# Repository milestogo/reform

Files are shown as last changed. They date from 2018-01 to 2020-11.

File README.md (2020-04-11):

# MNT Reform

This is the main repository for the MNT Reform open source laptop.

For details, check out [Finishing Reform](https://mntre.com/media/reform_md/2020-01-18-finishing-reform.html) and related articles.

## Impressions

Reform Version 2 Prototype
Reform Version 2 Motherboard

## License

Copyright 2018-2020 MNT Research GmbH.

The following licenses are used in the project, unless specified differently in a particular subfolder:

- Schematics, PCBs: [CERN-OHL-S v2](https://www.ohwr.org/project/cernohl/wikis/uploads/002d0b7d5066e6b3829168730237bddb/cern_ohl_s_v2.txt)
- Other documentation, artwork, photos and drawings that are not trademarks (see below): [CC-BY-SA 4.0](https://creativecommons.org/licenses/by-sa/4.0/legalcode)
- Software, firmware: Various. [GPL 3.0](https://www.gnu.org/licenses/gpl-3.0.en.html) if not specified otherwise in the file/subdirectory.

The "MNT" and "MNT REFORM" logos are trademarks of MNT Research GmbH. You may not use these in derived works. The reason for this is that we cannot be responsible for regulatory issues with derived boards and we cannot support them. If someone sees an MNT brand on a product, it has to be clear that it comes from MNT Research and not from a third party.

## Made With

* [KiCAD EDA](http://kicad-pcb.org/)
* [OpenSCAD](https://www.openscad.org/)
* [LUFA](http://www.fourwalledcubicle.com/LUFA.php)
* Autodesk Fusion (Case parts)

## MNT Reform Team

* **Lukas F. Hartmann (mntmn)** - *Schematics, PCB*
* **Ana Dantas** - *Industrial Design*
* **Greta Melnik** - *Quality & Assembly, Sleeve*

## Credits and Contributions

* [fully automated technologies](https://fully.automated.ee/) - *inrush limiter circuit*

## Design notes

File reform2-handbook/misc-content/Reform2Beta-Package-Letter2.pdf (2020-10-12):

MNT Research GmbH
Fehlerstr. 8, 12161 Berlin Germany

Email: lukas@mntre.com
Web: https://mntre.com

Director: Lukas F. Hartmann Amtsgericht Charlottenburg Aktenzeichen: HRB 136605 B WEEE: DE 33315564

Berlin, 2020-07-03
Dear MNT Customer,

Today we are delivering your MNT Reform 2.0 Beta unit. Thank you for putting your trust in us and for supporting our mission at this early stage: to ship a mobile computer that is as open and documented as possible, while still enabling productivity, privacy and easy maintenance.

We’ve put together this intro document to get you started quickly. We’re available for any further technical assistance.

Enjoy your MNT Reform!

Lukas F. Hartmann, Founder and Managing Director

Package Contents

- MNT Reform laptop with 2.0D-4 motherboard (with one wire patch for LTC4020 SHDN signal)
- MeanWell 24V 2.5A power supply with adapter
- This document and a hard copy of schematics

Safety

Please be extremely careful after opening the bottom panel, as there are up to 29V generated inside of the device which, when shorted, can cause sparks that can potentially ignite flammable material around the device. For this reason, we advise to unplug the battery cables from the motherboard before further disassembling the device. Do not touch/short the exposed metal pins of the battery holders with a metal tool!

Quick Start

First, you should learn a few keyboard shortcuts. Please note that currently, HYPER and the Circle Key (located next to F12) have the same function. This will likely change in the near future.

To turn the system on and off (hard power enable/disable) press Circle-1 or Circle-0 (zero), respectively. Circle-1 also does a hard reset of the main SoC if the system is already on.

To display cell voltage information, press Circle-V. Battery voltage, current and charger status can be checked with Circle-Y and Circle-S. The percentage displayed on the cell information screen is currently just a rough approximation based on total voltage. With the next update, a more useful percentage based on capacity and Amp hours spent will be implemented.

Circle-F1 and Circle-F2 decrease and increase the keyboard backlight brightness (but only if the main CPU/USB hub is powered). Circle-2 switches off the OLED. Circle-3 turns it back on.

To log in after boot, use “root” as the username with no password, and then create a new user account for yourself, following the on-screen instructions.

Boot

DIP switches SW5 on the motherboard allow you to toggle between eMMC and SD card boot (see schematics page 1). In the factory configuration, i.MX8MQ boots from the SD card.

Debugging

To control U-Boot or your own boot loader via UART, connect a UART adapter cable to the 3-pin header J18 (TX, RX and GND are labeled on the board) and configure your terminal to 115200 Baud 8N1. Please note that SER1 and SER2 labels are erroneously swapped on the silkscreen, so SER2 is UART1 and vice versa.

Trackball Tricks

The trackball has five buttons. The top two buttons function as left and right mouse buttons, the lower center button maps to the middle mouse button. Holding either the lower left or right buttons activates wheel mode, where vertical movement of the ball is translated into vertical mouse wheel events. The lower left button also generates a left click, but this will probably change in future versions.

The trackball is optical. We noticed that in direct bright sunlight, the optical sensor can be overwhelmed and works only if you block the sunlight with your other hand. This will be fixed by changing the trackball holder to a non-translucent material.

Display

The current beta version (2020-06-05) of the system image features an experimentally patched kernel module for the i.MX8MQ DCSS block that takes a parameter dcss_use_hdmi=1 (or 0) to activate either HDMI or internal MIPI DSI to eDP output at runtime. The eDP output is the default. Because the driver is loaded as a module, the display activates after a delay of a few seconds during boot. This is normal.

The display brightness can be controlled with the preinstalled brightnessctl tool (example: brightnessctl s 7). Brightness decrease/increase is mapped in sway to MNT-F1 / MNT-F2.

Speakers

To avoid damaging the speakers, keep the volume in check and lower it if audio distortion happens.

Further Information

The detailed Reform Operator’s Handbook is still being written. Meanwhile, refer to the following resources:

### 1. The system image build scripts

URL: https://source.mntmn.com/MNT/reform-system-image

Here you’ll find, in the reform2-imx8mq directory, the mkimage.sh and related scripts which generate the system image (including U-Boot and Linux Kernel) that is written on the MicroSD card preinstalled in your MNT Reform. You can find binary image files in the “Releases” section.

### 2. The interactive system diagram

URL: https://mntre.com/reform2-handbook/system.html

This is a technical block diagram of the individual components of the MNT Reform hardware with explanations and further links for each block.

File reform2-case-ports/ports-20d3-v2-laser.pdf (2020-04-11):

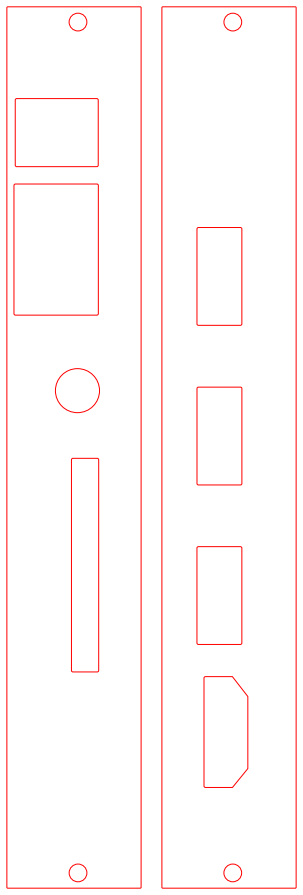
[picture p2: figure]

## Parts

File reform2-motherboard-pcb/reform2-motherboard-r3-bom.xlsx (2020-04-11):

Reference | Quantity | Value | Footprint | Distributor | Manufacturer | Manufacturer_No | THT | In Stock | To Order
J14 | 1 | USB_INT2 | Connector_JST:JST_PH_B4B-PH-K_1x04_P2.00mm_Vertical | Digikey | JST | B4B-PH-K-S(LF)(SN) | y
J16 | 1 | LINE_IN | Connector_PinHeader_2.00mm:PinHeader_1x03_P2.00mm_Vertical |  |  |  | y
J19 | 1 | JTAG | Connector_PinHeader_2.54mm:PinHeader_2x04_P2.54mm_Vertical | Mouser | Amphenol FCI | 79425-408HLF | y
J20 J18 | 2 | Conn_01x03_Male | Connector_PinHeader_2.54mm:PinHeader_1x03_P2.54mm_Vertical | Mouser | Wurth | 61300311121 | y
J21 | 1 | Conn_01x04 | Connector_JST:JST_PH_B4B-PH-K_1x04_P2.00mm_Vertical | Digikey | JST | B4B-PH-K-S(LF)(SN) | y
J22 | 1 | LPC_IO | Connector_PinHeader_2.54mm:PinHeader_2x08_P2.54mm_Vertical | Mouser | Molex | 87914-1616 | y
J23 | 1 | KDBSYSCTL | Connector_JST:JST_PH_B4B-PH-K_1x04_P2.00mm_Vertical | Digikey | JST | B4B-PH-K-S(LF)(SN) | y
J24 | 1 | EDP_HEADER | Connector_PinHeader_2.00mm:PinHeader_2x15_P2.00mm_Vertical | Mouser | Molex | 87758-3016 | y
J6 J5 J17 | 3 | USB3_A | Connector_USB:USB3_A_Molex_48393-001 | Mouser | Molex | 48393-0003 | y
J9 | 1 | USB_INT1 | Connector_JST:JST_PH_B4B-PH-K_1x04_P2.00mm_Vertical | Digikey | JST | B4B-PH-K-S(LF)(SN) | y
P1 | 1 | J0G-0003NL | footprints:PULSE_J0G-0003NL | Mouser | Pulse | J0G-0003NL | y
BT1 | 1 | CR1220 | Battery:BatteryHolder_Keystone_3000_1x12mm | Mouser | Keystone | 3000
C122 C161 | 2 | 100uF | Capacitor_SMD:CP_Elec_6.3x7.7 | Mouser | Panasonic | EEE-FTH101XAP
C141 C100 C111 C114 C129 C130 C4 C5 C32 C1 C146 C145 | 12 | 1uF | Capacitor_SMD:C_0603_1608Metric | Mouser | Taiyo Yuden | UMK107AB7105KA-T
C143 C144 C154 C142 C30 C29 C28 C27 C138 C56 C57 C52 C53 C54 C55 C58 C59 C60 C61 C119 C101 C103 C113 C118 C115 C105 C108 C106 C109 C107 C110 C135 C136 C23 C24 C25 C22 C26 C40 C42 C39 C41 C66 C73 C70 C85 C76 C77 C84 C67 C74 C75 C94 C93 C92 C90 C97 C96 C95 C89 C88 C87 C86 C14 C8 C13 C12 C11 C10 C9 C15 C7 C49 C50 C2 C80 C140 C149 | 78 | 0.1uF | Capacitor_SMD:C_0603_1608Metric | Mouser | Yageo | CC0603JPX7R9BB104
C147 C127 C83 C123 C124 C126 C121 | 7 | 47uF | Capacitor_SMD:C_0603_1608Metric | Mouser | Murata | GRM188R60J476ME15D
C150 C137 C120 C99 C112 C131 C133 C132 C134 C43 C91 C63 C81 C72 C69 C71 C37 C46 C47 C34 | 20 | 10uF | Capacitor_SMD:C_0603_1608Metric | Mouser | Murata | GRM188R6YA106MA73D
C151 C139 C35 C33 C6 | 5 | 4.7uF | Capacitor_SMD:C_0603_1608Metric | Mouser | TDK | C1608X5R1V475K080AC
C152 C153 C102 C104 C116 C117 C128 C148 | 8 | 10nF | Capacitor_SMD:C_0603_1608Metric | Mouser | KEMET | C0603C103K5RAC3190
C18 C16 C17 C19 | 4 | 220uF | Capacitor_SMD:CP_Elec_8x10 | Mouser | UCC | EMZR500ARA221MHA0G
C3 C31 | 2 | 0.33uF | Capacitor_SMD:C_0603_1608Metric | Mouser | TDK | C1608X7R1H334K080AC
C36 C38 | 2 | 6.8pF | Capacitor_SMD:C_0603_1608Metric | Mouser | Vishay | VJ0603A6R8DXQCW1BC
C44 C82 C125 C160 | 4 | 2.2uF | Capacitor_SMD:C_0603_1608Metric | Mouser | Taiyo Yuden | UMK107BBJ225KA-T
C45 | 1 | 0.033uF | Capacitor_SMD:C_0603_1608Metric | Mouser | KEMET | C0603C333J4REC7411
C65 | 1 | 680pF | Capacitor_SMD:C_0603_1608Metric | Mouser | KEMET | C0603C681J5GACTU
C68 C78 C79 C64 | 4 | 2nF | Capacitor_SMD:C_0603_1608Metric | Mouser | Murata | GRM1885C1H202JA01D
C98 C62 C21 C20 C51 C48 | 6 | 18pF | Capacitor_SMD:C_0603_1608Metric | Mouser | Yageo | CC0603JRNPO9BN180
D1 | 1 | BZT52C10 | Diode_SMD:D_SOD-123 | Mouser | Diodes, Inc. | BZT52C10-7-F
D11 | 1 | LED3V | LED_SMD:LED_0603_1608Metric | Mouser | ROHM | SMLEN3WBC8W1
D12 | 1 | LED5V | LED_SMD:LED_0603_1608Metric | Mouser | ROHM | SMLEN3WBC8W1
D2 | 1 | BAT46WJ,115 | Diode_SMD:D_SOD-323 | Mouser | Nexperia | BAT46WJ,115
D20 D21 | 2 | SK54A-LTP | Diode_SMD:D_SMA | Mouser | MCC | SK54A-LTP
D22 | 1 | LED_WLAN1 | LED_SMD:LED_0603_1608Metric | Mouser | ROHM | SMLEN3WBC8W1
D23 | 1 | LED_NVME | LED_SMD:LED_0603_1608Metric | Mouser | ROHM | SMLEN3WBC8W1
D3 D6 D4 | 3 | SBR0560S1 | Diode_SMD:D_SOD-123 | Mouser | Diodes, Inc. | SBR0560S1
D5 | 1 | RBR3MM60ATF | Diode_SMD:D_SOD-123 | Mouser | ROHM | RBR3MM60ATF
D7 | 1 | BZT52C6V2-7-F | Diode_SMD:D_SOD-123 | Mouser | Diodes, Inc. | BZT52C6V2-7-F
D8 | 1 | LEDCHG1 | LED_SMD:LED_0603_1608Metric | Mouser | ROHM | SML-D12Y1WT86
D9 | 1 | LEDCHG2 | LED_SMD:LED_0603_1608Metric | Mouser | ROHM | SML-D12Y1WT86
F2 F1 | 2 | 0157004.DR | footprints:fuse_smf | Mouser | Littelfuse | 0157004.DR
FB3 FB4 FB2 FB1 FB8 FB9 FB5 FB6 FB7 | 9 | 220@100MHz 1.4A | Inductor_SMD:L_0603_1608Metric | Mouser | Murata | BLM18PG221SH1D
H22 H24 H25 H27 | 4 | MountingHole_Pad | footprints:WA-SMSI-M2 | Mouser | Wurth | 9774010243
J1 | 1 | Jack-DC | footprints:SWC_RAPC712X | Mouser | Switchcraft | RAPC712X
J10 | 1 | 1-2199230-6 | footprints:TE_1-2199230-6 | Mouser | TE | 1-2199230-6
J11 | 1 | 48099-5701 | footprints:MOLEX_48099-5701 | Mouser | Molex | 48099-5701
J13 | 1 | BATCON1 | Connector_Molex:Molex_Pico-Lock_504050-0591_1x05-1MP_P1.50mm_Horizontal | Mouser | Molex | 504050-0591
J15 | 1 | Conn_01x33 | Connector_FFC-FPC:Hirose_FH12-33S-0.5SH_1x33-1MP_P0.50mm_Horizontal | Mouser | Hirose | FH12-33S-0.5SH(55)
J2 | 1 | BATCON2 | Connector_Molex:Molex_Pico-Lock_504050-0591_1x05-1MP_P1.50mm_Horizontal | Mouser | Molex | 504050-0591
J3 | 1 | SD_Card | footprints:TE_1775059-1 | Mouser | TE | 1775059-1
J4 | 1 | HDMI_A | footprints:HDMI-685119134923 | Mouser | Wurth | 685119134923
J7 | 1 | SJ-43516-SMT | footprints:SJ-43516-SMT | Mouser | CUI | SJ-43516-SMT-TR
J8 | 1 | USB_B_Micro | Connector_USB:USB_Micro-B_Molex-105017-0001 | Mouser | Molex | 105017-0001
L1 | 1 | 22uH 5A | Inductor_SMD:L_12x12mm_H6mm | Mouser | Wurth | 7447709220
L2 | 1 | IMC1210ER100K | Inductor_SMD:L_1210_3225Metric | Mouser | Vishay Dale | IMC1210ER100K
L3 L4 | 2 | 68uH | Inductor_SMD:L_Bourns_SRR1210A | Mouser | Bourns | SRR1210-680M
L5 | 1 | 10uH | Inductor_SMD:L_1210_3225Metric | Mouser | Taiyo Yuden | CBC3225T100MRV
L6 L7 | 2 | 2.2uH | Inductor_SMD:L_1210_3225Metric | Mouser | Taiyo Yuden | BRL3225T2R2M
Q14 Q11 Q5 Q10 Q9 Q8 Q7 Q6 Q12 | 9 | PMV50EPEAR | Package_TO_SOT_SMD:SOT-23 | Mouser | Nexperia | PMV50EPEAR
Q18 Q3 | 2 | Si7461DP | footprints:PowerPAK_SO-8_Single_8Pads | Mouser | Vishay Siliconix | SI7461DP-T1-E3
Q2 Q1 Q15 Q17 | 4 | Si7850DP | footprints:PowerPAK_SO-8_Single_8Pads | Mouser | Vishay Siliconix | SI7850DP-T1-E3
R1 | 1 | 9.1k 1% | Resistor_SMD:R_0603_1608Metric | Mouser | Yageo | RC0603FR-079K1L
R113 R119 R118 R117 R115 R45 R161 R128 R172 R54 | 10 | 10k | Resistor_SMD:R_0603_1608Metric | Mouser | Yageo | RC0603FR-0710KL
R120 R46 R86 R85 R84 R81 R178 R179 R181 R3 R56 R53 R8 R188 R189 | 15 | 100k | Resistor_SMD:R_0603_1608Metric | Mouser | Vishay Dale | CRCW0603100KJNEAC
R135 R136 R43 R44 R132 R131 R59 R58 R63 R60 R69 R68 R174 | 13 | 4.7k | Resistor_SMD:R_0603_1608Metric | Mouser | Yageo | RC0603FR-074K7L
R138 R114 R139 R150 R151 R121 R31 R25 R30 R29 R28 R27 R26 R32 R70 R72 | 16 | 33 | Resistor_SMD:R_0603_1608Metric | Mouser | Vishay Dale | CRCW060333R0FKEAC
R140 | 1 | 680 | Resistor_SMD:R_0603_1608Metric | Mouser | Yageo | RC0603FR-07680RL
R143 R142 R144 R48 R47 R80 | 6 | 47k | Resistor_SMD:R_0603_1608Metric | Mouser | Vishay Dale | CRCW060347K0FKEAC
R15 R9 R14 R13 R12 R11 R10 R16 R7 R52 R176 | 11 | 100 | Resistor_SMD:R_0603_1608Metric | Mouser | Vishay Dale | CRCW0603100RFKEAC
R156 R41 R55 R96 R97 R4 R5 R6 R153 | 9 | 1M | Resistor_SMD:R_0603_1608Metric | Mouser | Yageo | RC0603FR-071ML
R159 R158 R155 R154 R111 R191 R192 R145 R141 R187 R152 R35 R34 R65 R107 R104 R108 R105 R109 R106 R166 R149 R39 R123 R148 R77 R133 R134 R130 R129 R116 R146 R147 R103 R89 R88 R100 R101 R82 R83 R94 R95 R98 R73 R74 R75 R76 R79 R78 R124 R125 R126 R127 R157 R165 R163 R175 R51 R182 R185 R186 R137 R190 R193 | 64 | 0 | Resistor_SMD:R_0603_1608Metric | Mouser | Vishay Dale | CRCW06030000Z0EAC
R167 | 1 | 62 | Resistor_SMD:R_0603_1608Metric | Mouser | Yageo | RC0603FR-0762RL
R169 R170 R171 R168 R42 R160 R122 R40 R38 R37 R102 R71 | 12 | 1.5k | Resistor_SMD:R_0603_1608Metric | Mouser | Yageo | RC0603FR-071K5L
R173 | 1 | 49.9k | Resistor_SMD:R_0603_1608Metric | Mouser | Vishay Dale | CRCW060349K9FKEAC
R177 | 1 | 0.02 | Resistor_SMD:R_0612_1632Metric | Mouser | ROHM | LTR18EZPFSR020
R180 | 1 | 150k | Resistor_SMD:R_0603_1608Metric | Mouser | Vishay Dale | CRCW0603150KFKEAC
R2 | 1 | 1.3k 1% | Resistor_SMD:R_0603_1608Metric | Mouser | Yageo | RC0603FR-071K3L
R23 R17 R22 R21 R20 R19 R18 R24 | 8 | 3.3k | Resistor_SMD:R_0603_1608Metric | Mouser | Vishay Dale | CRCW06033K30FKEAC
R33 R164 R183 R184 | 4 | 1k | Resistor_SMD:R_0603_1608Metric | Mouser | Yageo | RC0603FR-071KL
R50 R49 | 2 | 0.01 | Resistor_SMD:R_0612_1632Metric | Mouser | ROHM | LTR18EZPFU10L0
R57 | 1 | 9.53k | Resistor_SMD:R_0603_1608Metric | Mouser | Yageo | RC0603FR-079K53L
R61 | 1 | 90.9k 1% | Resistor_SMD:R_0603_1608Metric | Mouser | Vishay Dale | CRCW060390K9FKEAC
R62 | 1 | 10k 1% | Resistor_SMD:R_0603_1608Metric | Mouser | Yageo | RC0603FR-0710KL
R64 | 1 | 51k | Resistor_SMD:R_0603_1608Metric | Mouser | Yageo | RC0603FR-0751KL
R66 R112 | 2 | 220 | Resistor_SMD:R_0603_1608Metric | Mouser | Yageo | RC0603FR-07220RL
R67 R110 R36 | 3 | 475 | Resistor_SMD:R_0603_1608Metric | Mouser | Yageo | RC0603FR-07475RL
R87 R99 | 2 | 24.9k | Resistor_SMD:R_0603_1608Metric | Mouser | Yageo | RC0603FR-0724K9L
R90 R92 R91 R93 | 4 | 27 | Resistor_SMD:R_0603_1608Metric | Mouser | Yageo | RC0603FR-0727RL
SW1 | 1 | SW_LPCPROG | Button_Switch_SMD:SW_DIP_SPSTx01_Slide_Omron_A6S-110x_W8.9mm_P2.54mm | Mouser | Omron | A6S-1101-H
SW2 | 1 | SW_LPCRST | Button_Switch_SMD:SW_Push_1P1T_NO_CK_KMR2 | Mouser | CK | KMR223NGULCLFG
SW3 | 1 | SW_DIP_x01 | Button_Switch_SMD:SW_DIP_SPSTx01_Slide_Omron_A6S-110x_W8.9mm_P2.54mm | Mouser | Omron | A6S-1101-H
SW5 | 1 | SW_DIP_x04 | Button_Switch_SMD:SW_DIP_SPSTx04_Slide_Omron_A6S-410x_W8.9mm_P2.54mm | Mouser | Omron | A6S-4101-H
SW6 | 1 | SW_Push | Button_Switch_SMD:SW_Push_1P1T_NO_CK_KMR2 | Mouser | CK | KMR223NGULCLFG
U1 | 1 | Nitrogen8M | footprints:TE_1473149-4 | Mouser | TE | 1717254-1
U10 | 1 | SN65DSI86IPAPQ1 | Package_QFP:HTQFP-64-1EP_10x10mm_P0.5mm_EP8x8mm | Mouser | Texas Instruments | SN65DSI86IPAPQ1
U11 | 1 | 679105700 | footprints:MOLEX_67910-5700 | Mouser | Molex | 67910-5700
U12 | 1 | LM2677SX-3.3 | Package_TO_SOT_SMD:TO-263-7_TabPin8 | Mouser | Texas Instruments | LM2677S-3.3/NOPB
U13 U19 | 2 | TLV62568DBV | Package_TO_SOT_SMD:SOT-23-5 | Mouser | Texas Instruments | TLV62568DBVR
U14 | 1 | LM2841X | Package_TO_SOT_SMD:TSOT-23-6 | Mouser | Texas Instruments | LM2841XMK-ADJL/NOPB
U15 U16 | 2 | TPS2561 | Package_SON:VSON-10-1EP_3x3mm_P0.5mm_EP1.65x2.4mm_ThermalVias | Mouser | Texas Instruments | TPS2561DRCR
U17 | 1 | TLV1117-18 | Package_TO_SOT_SMD:SOT-223 | Mouser | Texas Instruments | TLV1117-18CDCYR
U18 | 1 | LPC11U24FBD48-301 | Package_QFP:LQFP-48_7x7mm_P0.5mm | Mouser | NXP | LPC11U24FBD48-301
U2 | 1 | LTC4020EUHFPBF | Package_DFN_QFN:QFN-38-1EP_5x7mm_P0.5mm_EP3.15x5.15mm | Mouser | Analog Devices | LTC4020EUHF#PBF
U22 | 1 | TPD12S521 | footprints:TSSOP50P640X120-38N | Mouser | Texas Instruments | TPD12S521
U23 | 1 | IDT5V41066 | Package_SO:TSSOP-20_4.4x6.5mm_P0.65mm | Mouser | IDT | 5V41066PGGI8
U3 | 1 | WM8960 | Package_DFN_QFN:QFN-32-1EP_5x5mm_P0.5mm_EP3.45x3.45mm_ThermalVias | Mouser | Cirrus Logic | WM8960CGEFL/V
U4 | 1 | LTC6803-4 | Package_SO:SSOP-44_5.3x12.8mm_P0.5mm | Mouser | Analog Devices | LTC6803IG-4#PBF
U5 | 1 | PCF8523T | Package_SO:SOIC-8_3.9x4.9mm_P1.27mm | Mouser | NXP | PCF8523T/1,118
U6 | 1 | INA260 | Package_SO:TSSOP-16_4.4x5mm_P0.65mm | Mouser | Texas Instruments | INA260AIPWR
U7 | 1 | LM2677SX-5 | Package_TO_SOT_SMD:TO-263-7_TabPin8 | Mouser | Texas Instruments | LM2677SX-5
U8 | 1 | TXS0108EPW | Package_SO:TSSOP-20_4.4x6.5mm_P0.65mm | Mouser | Texas Instruments | TXS0108EPW
U9 | 1 | TUSB8041IPAPRQ1 | Package_QFP:HTQFP-64-1EP_10x10mm_P0.5mm_EP8x8mm_Mask4.4x4.4mm_ThermalVias | Mouser | Texas Instruments | TUSB8041IPAPRQ1
Y1 | 1 | 24MHz | Crystal:Crystal_SMD_Abracon_ABM8G-4Pin_3.2x2.5mm | Mouser | Abracon | ABM8AIG-24.000MHz-R40-4-T
Y2 | 1 | 12MHz | Crystal:Crystal_SMD_Abracon_ABM8G-4Pin_3.2x2.5mm | Mouser | Abracon | ABM8AIG-12.000MHz-2-T
Y3 | 1 | 25MHz | Crystal:Crystal_SMD_Abracon_ABM8G-4Pin_3.2x2.5mm | Mouser | Abracon | ABM8AIG-25.000MHz-R40-4-T
Y4 | 1 | 32.768 kHz | Crystal:Crystal_SMD_3215-2Pin_3.2x1.5mm | Mouser | ECS | ECS-.327-7-34B-TR
 | 441

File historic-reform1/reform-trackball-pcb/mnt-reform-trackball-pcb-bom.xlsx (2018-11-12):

 |  |  | MNT Reform-Trackball 20PCS BOM
Item # | *Ref Des | *Qty | Manufacturer | *Mfg Part # | Description / Value | *Package | Type | Your Instructions / Notes
1 | C1,C2 | 2 | Generic | Generic | 18pF >=6V | 0603 | SMD
2 | C3 | 1 | Generic | Generic | 0.1uF >=6V | 0603 | SMD
3 | C4 | 1 | Generic | Generic | 1uF >=6V | 0603 | SMD
4 | U1 | 1 | Microchip | ATMEGA32U2-AU | 8 Bit MCU | TQFP-32 | SMD | Pin 1 on bottom right
5 | Y1 | 1 | Fox | FC3BACALI16.0 | 16MHz 18pF 30ppm -40C +125C | 3.2 mm x 2.5 mm x 1.7 mm | SMD | Pin 1 on bottom left
6 | R1,R2 | 2 | Generic | Generic | 10kOhm | 0603 | SMD

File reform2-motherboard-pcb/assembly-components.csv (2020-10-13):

references | value | manufacturer | part_number | qty
ZPCB | PCB | MNT Research / PCBWay | MREFPMOB20R01 | 1

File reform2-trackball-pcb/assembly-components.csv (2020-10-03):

references | value | manufacturer | part_number | qty
ZPCB | PCB | MNT Research | MREFPTBC20R01 | 1

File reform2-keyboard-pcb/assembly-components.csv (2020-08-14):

references | value | manufacturer | part_number | qty
ZKCAP15 | Keycap 1.5U | Kailh | BSPG1350-06009 | 10
ZKCAP10 | Keycap 1U | Kailh | BSPG1350-06001P2 | 72
ZPCB | PCB | MNT Research / PCBWay | MREFPKBD20D04 | 1

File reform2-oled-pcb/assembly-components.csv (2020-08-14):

references | value | manufacturer | part_number | qty
ZPCB | PCB | MNT Research | MREFPOLE20D04 | 1

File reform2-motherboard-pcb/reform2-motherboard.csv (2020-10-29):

Reference | Quantity | Value | Footprint | Datasheet | Checked | Distributor | Manufacturer | Manufacturer_No | DNP | Availability | Field12 | Field13 | Field14 | Field15 | Field17 | Field18 | Field21 | Field22 | Field23 | Field25 | Field28 | Field30 | Field33 | Field34 | Field38 | Field39 | Field40 | Field42 | Field43 | Field5 | Field6 | Field4
BT1 | 1 | CR1220 | Battery:BatteryHolder_Keystone_3000_1x12mm | ~ | y | Mouser | Keystone | 3000
C122 C161 | 2 | 100uF | Capacitor_SMD:CP_Elec_6.3x7.7 | ~ | y | Mouser | Panasonic | EEE-FTH101XAP
C141 C162 C163 C100 C111 C114 C129 C130 C4 C5 C32 C1 C146 C145 | 14 | 1uF | Capacitor_SMD:C_0603_1608Metric | ~ | y | Mouser | Taiyo Yuden | UMK107BJ105KA-T
C143 C144 C154 C142 C156 C158 C165 C166 C30 C29 C28 C27 C138 C56 C57 C169 C168 C53 C54 C55 C59 C60 C61 C119 C101 C103 C113 C118 C115 C105 C108 C106 C109 C107 C110 C135 C136 C23 C24 C25 C22 C26 C86 C87 C88 C89 C95 C96 C97 C90 C92 C93 C94 C75 C74 C67 C84 C77 C76 C85 C70 C73 C66 C41 C39 C42 C40 C14 C8 C13 C12 C11 C10 C9 C15 C7 C49 C50 C2 C80 C140 C149 | 82 | 0.1uF | Capacitor_SMD:C_0603_1608Metric | ~ | y | Mouser | Yageo | CC0603JPX7R9BB104
C147 C127 C83 C123 C124 C126 C121 | 7 | 47uF | Capacitor_SMD:C_0603_1608Metric | ~ | y | Mouser | Murata | GRM188R60J476ME15D
C150 C137 C120 C155 C99 C112 C131 C133 C132 C134 C164 C71 C69 C72 C81 C63 C91 C43 C167 C37 C46 C47 C34 | 23 | 10uF | Capacitor_SMD:C_0603_1608Metric | ~ | y | Mouser | Murata | GRM188R6YA106MA73D
C151 C139 C170 C35 C33 C6 | 6 | 4.7uF | Capacitor_SMD:C_0603_1608Metric | ~ | y | Mouser | TDK | C1608X5R1V475K080AC
C157 C159 | 2 | 470nF | Capacitor_SMD:C_0603_1608Metric | ~ | y | Mouser | Taiyo Yuden | TMK107B7474KA-TR
C16 C17 | 2 | 100uF | Capacitor_SMD:CP_Elec_8x10 | ~ | y | Mouser | UCC | EMZR500ARA221MHA0G
C18 C19 | 2 | 220uF | Capacitor_SMD:CP_Elec_8x10 | ~ | y | Mouser | UCC | EMZR500ARA221MHA0G
C3 C31 | 2 | 0.33uF | Capacitor_SMD:C_0603_1608Metric | ~ | y | Mouser | TDK | C1608X7R1H334K080AC
C36 C38 | 2 | 6.8pF | Capacitor_SMD:C_0603_1608Metric | ~ | y | Mouser | Vishay | VJ0603A6R8DXQCW1BC
C44 C82 C125 C160 | 4 | 2.2uF | Capacitor_SMD:C_0603_1608Metric | ~ | y | Mouser | Taiyo Yuden | UMK107BBJ225KA-T
C45 | 1 | 0.033uF | Capacitor_SMD:C_0603_1608Metric | ~ | y | Mouser | KEMET | C0603C333J4REC7411
C52 C58 C152 C153 C102 C104 C116 C117 C128 C148 | 10 | 10nF | Capacitor_SMD:C_0603_1608Metric | ~ | y | Mouser | KEMET | C0603C103K5RAC3190
C65 | 1 | 680pF | Capacitor_SMD:C_0603_1608Metric | ~ | y | Mouser | KEMET | C0603C681J5GACTU
C79 C78 C68 C64 | 4 | 2nF | Capacitor_SMD:C_0603_1608Metric | ~ | y | Mouser | Murata | GRM1885C1H202JA01D
C98 C62 C20 C21 C51 C48 | 6 | 18pF | Capacitor_SMD:C_0603_1608Metric |  | y | Mouser | Yageo | CC0603JRNPO9BN180
D1 | 1 | BZT52C10 | Diode_SMD:D_SOD-123 | ~ | y | Mouser | Diodes, Inc. | BZT52C10-7-F
D10 | 1 | SP0503BAHT | Package_TO_SOT_SMD:SOT-143 | http://www.littelfuse.com/~/media/files/littelfuse/technical%20resources/documents/data%20sheets/sp05xxba.pdf | y | Mouser | Littelfuse | SP0503BAHT
D11 | 1 | LED3V | LED_SMD:LED_0603_1608Metric | ~ | y | Mouser | ROHM | SMLEN3WBC8W1
D12 | 1 | LED5V | LED_SMD:LED_0603_1608Metric | ~ | y | Mouser | ROHM | SMLEN3WBC8W1
D13 | 1 | SMAJ36CA-E3/5A | Diode_SMD:D_SMA | ~ | y | Mouser | Vishay | SMAJ36CA-E3/5A
D14 D15 | 2 | SD0603S040S0R2 | Diode_SMD:D_0603_1608Metric_Castellated | ~ | y | Mouser | AVX | SD0603S040S0R2
D2 | 1 | BAT46WJ,115 | Diode_SMD:D_SOD-323 | ~ | y | Mouser | Nexperia | BAT46WJ,115
D20 D21 | 2 | SK54A-LTP | Diode_SMD:D_SMA | https://www.mouser.de/datasheet/2/258/SK52A-L-SK510A-L(DO-214AC)-1375089.pdf | y | Mouser | MCC | SK54A-LTP
D22 | 1 | LED_WLAN1 | LED_SMD:LED_0603_1608Metric | ~ | y | Mouser | ROHM | SMLEN3WBC8W1
D23 | 1 | LED_NVME | LED_SMD:LED_0603_1608Metric | ~ | y | Mouser | ROHM | SMLEN3WBC8W1
D3 D6 D4 | 3 | SBR0560S1 | Diode_SMD:D_SOD-123 |  | y | Mouser | Diodes, Inc. | SBR0560S1-7
D5 | 1 | RBR3MM60ATF | Diode_SMD:D_SOD-123 | ~ | y | Mouser | ROHM | RBR3MM60ATFTR
D7 | 1 | BZT52C6V2-7-F | Diode_SMD:D_SOD-123 | ~ | y | Mouser | Diodes, Inc. | BZT52C6V2-7-F
D8 | 1 | LEDCHG1 | LED_SMD:LED_0603_1608Metric | ~ | y | Mouser | ROHM | SML-D12Y1WT86
D9 | 1 | LEDCHG2 | LED_SMD:LED_0603_1608Metric | ~ | y | Mouser | ROHM | SML-D12Y1WT86
F2 F1 | 2 | 0157004.DR | footprints:fuse_smf | ~ | y | Mouser | Littelfuse | 0157004.DR
FB10 FB11 FB16 FB17 FB20 FB18 FB19 FB21 FB22 FB3 FB4 FB12 FB15 FB14 | 14 | 100@100MHz 3A | Inductor_SMD:L_0603_1608Metric | ~ | y | Mouser | Murata | BLM18KG101TN1D
FB7 FB6 FB5 FB9 FB8 FB1 FB2 | 7 | 220@100MHz 1.4A | Inductor_SMD:L_0603_1608Metric | ~ | y | Mouser | Murata | BLM18PG221SH1D
H1 | 1 | NGFF-Mount1 | footprints:WA-SMSI-M2 | ~ | y | None |  |  | y
H10 | 1 | LOGO_REFORM | reform2-motherboard:mntreform | ~ | y | None |  |  | y
H11 | 1 | LABEL_MPCIE1 | footprints:mpcie | ~ | y | None |  |  | y
H12 | 1 | LABEL_MPCIE2 | footprints:nvme | ~ | y | None |  |  | y
H13 | 1 | LABEL_CPU | footprints:cpu | ~ | y | None |  |  | y
H14 | 1 | BADGE | footprints:reform2-motherboard-badge | ~ | y | None |  |  | y
H15 | 1 | NOTOUCH | Symbol:ESD-Logo_8.9x8mm_SilkScreen | ~ | y | None |  |  | y
H2 | 1 | NGFF-Mount2 | footprints:WA-SMSI-M2 | ~ | y | None |  |  | y
H22 H24 H25 H27 | 4 | MountingHole_Pad | footprints:WA-SMSI-M2 | ~ | y | Mouser | Wurth | 9774010243
H3 | 1 | NGFF-Mount3 | footprints:WA-SMSI-M2 | ~ | y | None |  |  | y
H8 H7 H6 H5 | 4 | MountingHole_Pad | MountingHole:MountingHole_2.2mm_M2_DIN965_Pad | ~ | y | None |  |  | y
H9 | 1 | OSHWA_DE17 | footprints:oshwa-de17 | ~ | y | None |  |  | y
J1 | 1 | Jack-DC | footprints:SWC_RAPC712X | ~ | y | Mouser | Switchcraft | RAPC712X
J10 | 1 | 1-2199230-6 | footprints:TE_1-2199230-6 |  | y | Mouser | TE | 1-2199230-6
J11 | 1 | 48099-5701 | footprints:MOLEX_48099-5701 |  | y | Mouser | Molex | 48099-5701
J13 | 1 | BATCON1 | Connector_Molex:Molex_Pico-Lock_504050-0591_1x05-1MP_P1.50mm_Horizontal | ~ | y | Mouser | Molex | 504050-0591
J14 | 1 | USB_INT2 | Connector_JST:JST_PH_B4B-PH-K_1x04_P2.00mm_Vertical | ~ | y | Digikey | JST | B4B-PH-K-S(LF)(SN)
J15 | 1 | Conn_01x33 | Connector_FFC-FPC:Hirose_FH12-33S-0.5SH_1x33-1MP_P0.50mm_Horizontal | ~ | y | Mouser | Hirose | FH12-33S-0.5SH(55)
J16 | 1 | LINE_IN | Connector_PinHeader_2.00mm:PinHeader_1x03_P2.00mm_Vertical | ~ | y |  |  |  | y
J18 | 1 | Conn_01x03_Male | Connector_PinHeader_2.54mm:PinHeader_1x03_P2.54mm_Horizontal | ~ | y | Mouser | Wurth | 61300311121
J19 | 1 | JTAG | Connector_PinHeader_1.27mm:PinHeader_2x05_P1.27mm_Vertical | ~ | y | Mouser | Amphenol FCI | 20021111-00010T4LF
J2 | 1 | BATCON2 | Connector_Molex:Molex_Pico-Lock_504050-0591_1x05-1MP_P1.50mm_Horizontal | ~ | y | Mouser | Molex | 504050-0591
J20 | 1 | Conn_01x03_Male | Connector_PinHeader_2.54mm:PinHeader_1x03_P2.54mm_Vertical | ~ | y | Mouser | Wurth | 61300311121
J21 | 1 | Conn_01x04 | Connector_JST:JST_PH_B4B-PH-K_1x04_P2.00mm_Vertical | ~ | y | Digikey | JST | B4B-PH-K-S(LF)(SN)
J22 | 1 | LPC_IO | Connector_PinHeader_2.54mm:PinHeader_2x08_P2.54mm_Vertical | ~ | y | Mouser | Molex | 87914-1616
J23 | 1 | KDBSYSCTL | Connector_JST:JST_PH_B4B-PH-K_1x04_P2.00mm_Vertical | ~ | y | Digikey | JST | B4B-PH-K-S(LF)(SN)
J24 | 1 | EDP_HEADER | Connector_PinHeader_2.00mm:PinHeader_2x15_P2.00mm_Vertical | ~ | y | Mouser | Molex | 87758-3016
J3 | 1 | SD_Card | footprints:TE_1775059-1 | https://www.te.com/usa-en/product-1775059-1.html | y | Mouser | TE | 1775059-1
J4 | 1 | HDMI_A | footprints:HDMI-685119134923 | https://en.wikipedia.org/wiki/HDMI | y | Mouser | Wurth | 685119134923
J5 J17 J6 | 3 | USB3_A | footprints:692121030100 | ~ | y | Mouser | Wurth | 692121030100
J7 | 1 | SJ-43516-SMT | footprints:SJ-43516-SMT |  | y | Mouser | CUI | SJ-43516-SMT-TR
J8 | 1 | USB_B_Micro | footprints:WE_629105136821 | ~ | y | Mouser | Wurth | 629105136821
J9 | 1 | USB_INT1 | Connector_JST:JST_PH_B4B-PH-K_1x04_P2.00mm_Vertical | ~ | y | Digikey | JST | B4B-PH-K-S(LF)(SN)
L1 | 1 | 22uH 5A | Inductor_SMD:L_12x12mm_H6mm | ~ | y | Mouser | Wurth | 7447709220
L10 L9 L11 L8 | 4 | 15uH | Inductor_SMD:L_1210_3225Metric | ~ | y | Mouser | Murata | LQH32PB150MN0L
L2 | 1 | IMC1210ER100K | Inductor_SMD:L_1210_3225Metric | ~ | y | Mouser | Vishay Dale | IMC1210ER100K
L3 L4 | 2 | 68uH | Inductor_SMD:L_Bourns_SRR1210A | ~ | y | Mouser | Bourns | SRR1210-680M
L5 | 1 | 10uH | Inductor_SMD:L_1210_3225Metric | ~ | y | Mouser | Taiyo Yuden | CBC3225T100MRV
L6 L7 | 2 | 2.2uH | Inductor_SMD:L_1210_3225Metric | ~ | y | Mouser | Taiyo Yuden | BRL3225T2R2M
P1 | 1 | J0G-0003NL | footprints:PULSE_J0G-0003NL | Conn RJ-45 Integrated Magnetics F 8 POS 2.03mm Solder RA Thru-Hole 17 Terminal 1 Port | y | Mouser | Pulse | J0G-0003NL |  | Good
Q11 Q5 Q10 Q9 Q8 Q7 Q6 Q12 | 8 | PMV50EPEAR | Package_TO_SOT_SMD:SOT-23 | https://www.diodes.com/assets/Datasheets/DMG2301L.pdf | y | Mouser | Nexperia | PMV50EPEAR
Q13 Q14 Q4 | 3 | PMV50ENEAR | Package_TO_SOT_SMD:SOT-23 | http://www.diodes.com/assets/Datasheets/ds30376.pdf | y | Mouser | Nexperia | PMV50ENEAR
Q18 Q3 | 2 | Si7461DP | footprints:PowerPAK_SO-8_Single_8Pads |  | y | Mouser | Vishay Siliconix | SI7461DP-T1-E3
Q2 Q1 Q15 Q17 | 4 | Si7850DP | footprints:PowerPAK_SO-8_Single_8Pads | http://www.irf.com/product-info/datasheets/data/irf8721pbf-1.pdf | y | Mouser | Vishay Siliconix | SI7850DP-T1-E3
R113 R119 R118 R117 R115 R45 R161 R196 R83 R2 R128 R172 R54 R95 | 14 | 10k | Resistor_SMD:R_0603_1608Metric | ~ | y | Mouser | Yageo | RC0603FR-0710KL
R120 R46 R160 R82 R81 R84 R85 R86 R103 R178 R179 R181 R3 R56 R8 R188 R189 R89 R94 R88 | 20 | 100k | Resistor_SMD:R_0603_1608Metric | ~ | y | Mouser | Vishay Dale | CRCW0603100KJNEAC
R123 R148 R198 R199 | 4 | 49.9 | Resistor_SMD:R_0603_1608Metric | ~ | y | Mouser | Yageo | RC0603FR-1049R9L
R135 R136 R43 R44 R132 R131 R60 R63 R58 R59 R69 R68 R174 | 13 | 4.7k | Resistor_SMD:R_0603_1608Metric | ~ | y | Mouser | Yageo | RC0603FR-074K7L
R138 R114 R139 R150 R151 R121 R70 R72 | 8 | 33 | Resistor_SMD:R_0603_1608Metric | ~ | y | Mouser | Vishay Dale | CRCW060333R0FKEAC
R140 | 1 | 680 | Resistor_SMD:R_0603_1608Metric | ~ | y | Mouser | Yageo | RC0603FR-07680RL
R143 R142 R144 R48 R47 R197 R80 | 7 | 47k | Resistor_SMD:R_0603_1608Metric | ~ | y | Mouser | Vishay Dale | CRCW060347K0FKEAC
R15 R9 R14 R13 R12 R11 R10 R16 R7 R52 R175 R176 | 12 | 100 | Resistor_SMD:R_0603_1608Metric | ~ | y | Mouser | Vishay Dale | CRCW0603100RFKEAC
R155 R154 R111 R141 R187 R152 R65 R107 R104 R108 R105 R109 R106 R39 R101 R77 R130 R129 R116 R146 R147 R73 R74 R75 R76 R79 R78 R124 R125 R126 R127 R157 R51 R182 R185 R186 R137 R194 R1 R193 R100 R98 | 42 | 0 | Resistor_SMD:R_0603_1608Metric | ~ | y | Mouser | Vishay Dale | CRCW06030000Z0EAC
R156 R97 R96 R55 R41 R4 R5 R6 R153 | 9 | 1M | Resistor_SMD:R_0603_1608Metric |  | y | Mouser | Yageo | RC0603FR-071ML
R167 | 1 | 62 | Resistor_SMD:R_0603_1608Metric | ~ | y | Mouser | Yageo | RC0603FR-0762RL
R169 R170 R171 R168 R42 R35 R122 R40 R38 R37 R102 R71 R195 | 13 | 1.5k | Resistor_SMD:R_0603_1608Metric | ~ | y | Mouser | Yageo | RC0603FR-071K5L
R173 | 1 | 49.9k | Resistor_SMD:R_0603_1608Metric | ~ | y | Mouser | Vishay Dale | CRCW060349K9FKEAC
R177 | 1 | 0.02 | Resistor_SMD:R_0612_1632Metric | ~ | y | Mouser | ROHM | LTR18EZPFSR020
R180 R34 | 2 | 150k | Resistor_SMD:R_0603_1608Metric | ~ | y | Mouser | Vishay Dale | CRCW0603150KFKEAC
R192 | 1 | 27k | Resistor_SMD:R_0603_1608Metric | ~ | y | Mouser | Bourns | CR0603-FX-2702ELF
R23 R17 R22 R21 R20 R19 R18 R24 | 8 | 3.3k | Resistor_SMD:R_0603_1608Metric | ~ | y | Mouser | Vishay Dale | CRCW06033K30FKEAC
R31 R25 R30 R29 R28 R27 R26 R32 | 8 | 4.7 | Resistor_SMD:R_2512_6332Metric | ~ | y | Mouser | TE Connectivity | 35224R7JT
R36 | 1 | 475 | Resistor_SMD:R_0603_1608Metric | ~ | y | Mouser | Yageo | RC0603FR-07475RL
R50 R49 | 2 | 0.01 | Resistor_SMD:R_0612_1632Metric | ~ | y | Mouser | ROHM | LTR18EZPFU10L0
R53 | 1 | 330 | Resistor_SMD:R_0603_1608Metric | ~ | y | Mouser | Yageo | RC0603FR-07330RL
R57 | 1 | 9.53k | Resistor_SMD:R_0603_1608Metric | ~ | y | Mouser | Yageo | RC0603FR-079K53L
R61 | 1 | 90.9k 1% | Resistor_SMD:R_0603_1608Metric | ~ | y | Mouser | Vishay Dale | CRCW060390K9FKEAC
R62 | 1 | 10k 1% | Resistor_SMD:R_0603_1608Metric | ~ | y | Mouser | Yageo | RC0603FR-0710KL
R64 | 1 | 51k | Resistor_SMD:R_0603_1608Metric | ~ | y | Mouser | Yageo | RC0603FR-0751KL
R66 R112 | 2 | 220 | Resistor_SMD:R_0603_1608Metric | ~ | y | Mouser | Yageo | RC0603FR-07220RL
R67 R110 R33 R164 R183 R184 | 6 | 1k | Resistor_SMD:R_0603_1608Metric | ~ | y | Mouser | Yageo | RC0603FR-071KL
R93 R91 R92 R90 | 4 | 27 | Resistor_SMD:R_0603_1608Metric | ~ | y | Mouser | Yageo | RC0603FR-0727RL
R99 R87 | 2 | 24.9k | Resistor_SMD:R_0603_1608Metric | ~ | y | Mouser | Yageo | RC0603FR-0724K9L
SW3 SW1 | 2 | SW_DIP_x01 | Button_Switch_SMD:SW_DIP_SPSTx01_Slide_Omron_A6S-110x_W8.9mm_P2.54mm | ~ | y | Mouser | Apem | DM01
SW5 | 1 | SW_DIP_x04 | Button_Switch_SMD:SW_DIP_SPSTx04_Slide_Copal_CHS-04B_W7.62mm_P1.27mm |  | y | Mouser | Diptronics | DHA-04TQ
SW6 SW2 | 2 | SW_Push | footprints:UK-B0206-G3.8-250-JZ | ~ | y | Mouser | USAKRO | UK-B0206-G3.8-250-JZ
TP1 | 1 | IMX_PWM4 | TestPoint:TestPoint_Pad_D1.0mm | ~ | y | None |  |  | y
TP10 | 1 | T_M4_NMI | TestPoint:TestPoint_Pad_D1.0mm | ~ | y | None |  |  | y
TP12 | 1 | SAI2_RXC | TestPoint:TestPoint_Pad_D1.0mm | ~ | y | None |  |  | y
TP2 | 1 | T_OTG | TestPoint:TestPoint_Pad_D1.0mm | ~ | y | None |  |  | y
TP8 | 1 | T_PMIC_ON_REQ | TestPoint:TestPoint_Pad_D1.0mm | ~ | y | None |  |  | y
U1 | 1 | Nitrogen8M | footprints:TE_1473149-4 |  | y | Mouser | TE | 1717254-1
U10 | 1 | SN65DSI86IPAPQ1 | Package_QFP:HTQFP-64-1EP_10x10mm_P0.5mm_EP8x8mm | http://www.ti.com/lit/ds/symlink/sn65dsi86-q1.pdf | y | Mouser | Texas Instruments | SN65DSI86IPAPQ1
U11 | 1 | 679105700 | footprints:MOLEX_67910-5700 |  | y | Mouser | Molex | 67910-5700
U12 | 1 | LM2677SX-3.3 | Package_TO_SOT_SMD:TO-263-7_TabPin8 | http://www.ti.com/lit/ds/symlink/lm2677.pdf | y | Mouser | Texas Instruments | LM2677S-3.3/NOPB
U13 U19 | 2 | TLV62568DBV | Package_TO_SOT_SMD:SOT-23-5 | http://www.ti.com/lit/ds/symlink/tlv62568.pdf | y | Mouser | Texas Instruments | TLV62568DBVR
U14 | 1 | LMR16006YQ3 | Package_TO_SOT_SMD:TSOT-23-6 |  | y | Mouser | Texas Instruments | LMR16006YQ3
U16 U15 | 2 | TPS2561 | Package_SON:VSON-10-1EP_3x3mm_P0.5mm_EP1.65x2.4mm_ThermalVias | http://www.ti.com/lit/ds/symlink/tps2561.pdf | y | Mouser | Texas Instruments | TPS2561DRCR
U17 | 1 | TLV1117-18 | Package_TO_SOT_SMD:SOT-223 | http://www.ti.com/lit/ds/symlink/tlv1117.pdf | y | Mouser | Texas Instruments | TLV1117-18CDCYR
U18 | 1 | LPC11U24FBD48-301 | Package_QFP:LQFP-48_7x7mm_P0.5mm | http://www.nxp.com/documents/data_sheet/LPC11U2X.pdf | y | Mouser | NXP | LPC11U24FBD48-301
U2 | 1 | LTC4020EUHFPBF | Package_DFN_QFN:QFN-38-1EP_5x7mm_P0.5mm_EP3.15x5.15mm |  | y | Mouser | Analog Devices | LTC4020EUHF#PBF |  |  |  |  |  |  |  |  |  |  |  |  |  |  |  |  |  |  |  |  |  |  |  | ltc4020euhf#pbf
U20 U24 U27 | 3 | AP22815 | footprints:TSOT-25 |  | y | Mouser | Diodes, Inc. | AP22815AWT-7
U22 | 1 | TPD12S521 | footprints:TSSOP50P640X120-38N |  | y | Mouser | Texas Instruments | TPD12S521
U23 | 1 | IDT5V41066 | Package_SO:TSSOP-20_4.4x6.5mm_P0.65mm | https://www.idt.com/document/dst/5v41066-datasheet | y | Mouser | IDT | 5V41066PGGI8
U26 U25 U21 | 3 | SP3012-06UTG | footprints:SON50P350X135X55-14N |  | y | Mouser | Littelfuse | SP3012-06UTG |  |  | 0.5 | 0.0 | 3.4 | 02/23/17 | 0.55 | 0.25 | 0.35 | 0.55mm | 0.2 | 14.0 | 0.15 | 0.25 | 3.6 | 0.0 | IPC 7351B | 1.35 | 3.5 | Littelfuse | 0.3 | 1.45 | 1.25
U28 | 1 | SN74AVC1T45 | Package_TO_SOT_SMD:SOT-23-6 |  | y | Mouser | Texas Instruments | SN74AVC1T45
U3 | 1 | WM8960 | Package_DFN_QFN:QFN-32-1EP_5x5mm_P0.5mm_EP3.45x3.45mm_ThermalVias |  | y | Mouser | Cirrus Logic | WM8960CGEFL/V
U4 | 1 | LTC6803-4 | Package_SO:SSOP-44_5.3x12.8mm_P0.5mm | https://www.analog.com/media/en/technical-documentation/data-sheets/680324fa.pdf | y | Mouser | Analog Devices | LTC6803IG-4#PBF
U5 | 1 | PCF8523T | Package_SO:SOIC-8_3.9x4.9mm_P1.27mm | https://www.nxp.com/docs/en/data-sheet/PCF8523.pdf | y | Mouser | NXP | PCF8523T/1,118
U6 | 1 | INA260 | Package_SO:TSSOP-16_4.4x5mm_P0.65mm | http://www.ti.com/lit/ds/symlink/ina260.pdf | y | Mouser | Texas Instruments | INA260AIPWR
U7 | 1 | LM2677SX-5 | Package_TO_SOT_SMD:TO-263-7_TabPin8 | http://www.ti.com/lit/ds/symlink/lm2677.pdf | y | Mouser | Texas Instruments | LM2677SX-5
U8 | 1 | TXS0108EPW | Package_SO:TSSOP-20_4.4x6.5mm_P0.65mm | www.ti.com/lit/ds/symlink/txs0108e.pdf | y | Mouser | Texas Instruments | TXS0108EPW
U9 | 1 | TUSB8041IPAPRQ1 | Package_QFP:HTQFP-64-1EP_10x10mm_P0.5mm_EP8x8mm_Mask4.4x4.4mm_ThermalVias | http://www.ti.com/lit/ds/symlink/tusb8041.pdf | y | Mouser | Texas Instruments | TUSB8041IPAPRQ1
Y1 | 1 | 24MHz | Crystal:Crystal_SMD_Abracon_ABM8G-4Pin_3.2x2.5mm | https://www.mouser.de/datasheet/2/3/ABM8AIG-783590.pdf | y | Mouser | Abracon | ABM8AIG-24.000MHz-R40-4-T
Y2 | 1 | 12MHz | Crystal:Crystal_SMD_Abracon_ABM8G-4Pin_3.2x2.5mm | https://www.mouser.de/datasheet/2/3/ABM8AIG-783590.pdf | y | Mouser | Abracon | ABM8AIG-12.000MHz-2-T
Y3 | 1 | 25MHz | Crystal:Crystal_SMD_Abracon_ABM8G-4Pin_3.2x2.5mm |  | y | Mouser | Abracon | ABM8AIG-25.000MHz-R40-4-T
Y4 | 1 | 32.768 kHz | Crystal:Crystal_SMD_3215-2Pin_3.2x1.5mm | ~ | y | Mouser | ECS | ECS-.327-7-34B-TR

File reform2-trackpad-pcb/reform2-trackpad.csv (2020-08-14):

Reference | Quantity | Value | Footprint | Datasheet | Manufacturer | Manufacturer_No | Flags
C1 C2 | 2 | 18pF | Capacitor_SMD:C_0603_1608Metric |  | Yageo | CC0603JRNPO9BN180
C3 C5 | 2 | 0.1uF | Capacitor_SMD:C_0603_1608Metric |  | Yageo | CC0603JPX7R9BB104
C4 | 1 | 1uF | Capacitor_SMD:C_0603_1608Metric |  | Taiyo Yuden | UMK107BJ105KA-T
J1 | 1 | Conn_USB | Connector_JST:JST_PH_B4B-PH-K_1x04_P2.00mm_Vertical |  | JST | B4B-PH-K-S(LF)(SN)
J2 | 1 | Conn_01x06_Female | Connector_FFC-FPC:Hirose_FH12-6S-0.5SH_1x06-1MP_P0.50mm_Horizontal |  | Hirose | FH12-6S-0.5SH(55)
MK1 | 1 | WEEE | Symbol:WEEE-Logo_4.2x6mm_SilkScreen
MK13 | 1 | LOGO | footprints:mnt-minilogo
MK5 MK6 | 2 | Mounting_Hole | MountingHole:MountingHole_2.2mm_M2_Pad
R10 R11 | 2 | 4.7k | Resistor_SMD:R_0603_1608Metric |  | Yageo | RC0603FR-074K7L
R2 R1 | 2 | 10k | Resistor_SMD:R_0603_1608Metric |  | Vishay Dale | CRCW060310K0JNEAC
R8 R9 | 2 | 22 | Resistor_SMD:R_0603_1608Metric |  | Yageo | RT0603DRD0722RL
SW6 | 1 | SW_RST | Button_Switch_SMD:SW_Push_1P1T_NO_CK_KMR2 |  | CK | KMR221GLFS
SW7 | 1 | SW_HWB | Button_Switch_SMD:SW_DIP_SPSTx01_Slide_Omron_A6S-110x_W8.9mm_P2.54mm |  | Omron | A6S-1101-H
U1 | 1 | ATmega32U2-AU | Package_QFP:TQFP-32_7x7mm_P0.8mm |  | Microchip | ATMEGA32U2-AU
U2 | 1 | TLV75533PDBV | Package_TO_SOT_SMD:SOT-23-5 |  | Texas Instruments | TLV75533PDBVR
Y1 | 1 | Crystal_GND24 | Crystal:Crystal_SMD_3225-4Pin_3.2x2.5mm_HandSoldering |  | Abracon | ABM8AIG-16.000MHz-4-T

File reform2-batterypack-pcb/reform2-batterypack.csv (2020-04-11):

Reference | Quantity | Value | Footprint | Datasheet | Manufacturer | Manufacturer_No
H1 H2 H3 H4 H5 H6 H7 H8 | 8 | MountingHole | MountingHole:MountingHole_2.2mm_M2 | ~
H9 | 1 | LOGO | footprints:mnt-minilogo | ~
J1 | 1 | Conn_01x05_Female | Connector_Molex:Molex_Pico-Lock_504050-0591_1x05-1MP_P1.50mm_Horizontal | ~ | Molex | 504050-0591
U2 U3 U4 U1 | 4 | KEYSTONE_54 | reform2-batterypack:Keystone54 |  | Keystone | 54

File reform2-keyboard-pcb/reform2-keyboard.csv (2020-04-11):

Reference | Quantity | Value | Footprint | Datasheet | Manufacturer | Manufacturer_No
C1 C2 | 2 | 18pF | Capacitor_SMD:C_0603_1608Metric |  | Yageo | CC0603JRNPO9BN180
C10 C7 | 2 | 4.7uF | Capacitor_SMD:C_0603_1608Metric | ~ | Taiyo Yuden | JMK107BB7475KA-T
C3 C5 C9 C8 | 4 | 1uF | Capacitor_SMD:C_0603_1608Metric |  | TDK | C1608X8L1C105K080AC
C4 C6 | 2 | 0.1uF | Capacitor_SMD:C_0603_1608Metric |  | Yageo | CC0603JPX7R9BB104
D1 D7 D13 D19 D25 D31 D37 D43 D49 D55 D61 D67 D73 D78 D8 D14 D20 D26 D32 D38 D44 D50 D56 D62 D68 D74 D79 D9 D15 D21 D27 D33 D39 D45 D51 D57 D63 D69 D75 D80 D4 D10 D16 D22 D28 D34 D40 D46 D52 D58 D64 D70 D76 D81 D5 D11 D17 D23 D29 D35 D41 D47 D53 D59 D65 D71 D77 D82 D6 D12 D18 D24 D30 D36 D42 D3 D2 D48 D54 D60 D66 D72 | 82 | MMDL914T1G | Diode_SMD:D_0603_1608Metric_Pad1.05x0.95mm_HandSolder |  | ON | MMDL914T1G
D83 | 1 | B250-13-F | Diode_SMD:D_SMB_Handsoldering | ~ | Diodes | B250-13-F
D84 D85 D86 D87 D88 D89 D90 D91 D94 D95 D96 D97 D98 D99 D100 D101 D104 D105 D106 D107 D108 D109 D110 D111 D114 D115 D116 D117 D118 D119 D120 D121 D124 D125 D126 D127 D128 D129 D130 D131 D134 D135 D136 D137 D138 D139 D140 D141 D144 D145 D146 D147 D148 D149 D150 D151 D154 D155 D156 D157 D158 D159 D160 D161 D92 D93 D102 D103 D112 D113 D122 D123 D132 D133 D142 D143 D152 D153 D162 D163 | 80 | WLED | LED_SMD:LED_0603_1608Metric | ~ | OSRAM | LW Q38E-Q2OO-3K5L
GFX1 GFX2 | 2 | MNT | reform2-keyboard:mntreform | ~
H1 | 1 | MH1 | MountingHole:MountingHole_2.2mm_M2_Pad | ~
H2 | 1 | MH2 | MountingHole:MountingHole_2.2mm_M2_Pad | ~
H3 | 1 | MH3 | MountingHole:MountingHole_2.2mm_M2_Pad | ~
H4 | 1 | MH4 | MountingHole:MountingHole_2.2mm_M2_Pad | ~
H5 | 1 | MH5 | MountingHole:MountingHole_2.2mm_M2_Pad | ~
H6 | 1 | MH6 | MountingHole:MountingHole_2.2mm_M2_Pad | ~
J1 | 1 | USB | Connector_JST:JST_PH_S4B-PH-SM4-TB_1x04-1MP_P2.00mm_Horizontal |  | JST | S4B-PH-SM4-TB(LF)(SN)
J2 | 1 | UART | Connector_JST:JST_PH_S4B-PH-SM4-TB_1x04-1MP_P2.00mm_Horizontal |  | JST | S4B-PH-SM4-TB(LF)(SN)
J3 | 1 | AUX | Connector_FFC-FPC:Molex_200528-0040_1x04-1MP_P1.00mm_Horizontal |  | Molex | 200528-0040
J4 | 1 | USB_C_Receptacle_USB2.0 | Connector_USB:USB_C_Receptacle_Amphenol_12401610E4-2A | https://www.usb.org/sites/default/files/documents/usb_type-c.zip | Amphenol | 12401610E4#2A
L1 | 1 | 10uH | reform2-keyboard:IND_SRP4020TA-150M | ~ | Bourns | SRP4020TA-100M
R10 | 1 | 715K | Resistor_SMD:R_0603_1608Metric | ~ | Vishay Dale | CRCW0603715KFKEA
R11 | 1 | 1M | Resistor_SMD:R_0603_1608Metric | ~ | Panasonic | ERJ-3EKF1004V
R12 | 1 | 54.9K | Resistor_SMD:R_0603_1608Metric | ~ | Yageo | RC0603FR-0754K9L
R13 R14 | 2 | 5.1k | Resistor_SMD:R_0603_1608Metric | ~ | Yageo | AC0603FR-135K1L
R2 R1 | 2 | 22 | Resistor_SMD:R_0603_1608Metric |  | Vishay Dale | CRCW06030000Z0EAC
R3 | 1 | 10k | Resistor_SMD:R_0603_1608Metric |  | Yageo | AF0603JR-0710KL
R4 R9 | 2 | 0 | Resistor_SMD:R_0603_1608Metric |  | Vishay Dale | CRCW06030000Z0EAC
R5 R6 | 2 | 4.7k | Resistor_SMD:R_0603_1608Metric | ~ | Vishay Dale | CRCW06034K70FKEAC
R7 | 1 | 62K | Resistor_SMD:R_0603_1608Metric | ~ | Vishay Dale | CRCW060362K0FKEAC
R8 | 1 | 604K | Resistor_SMD:R_0603_1608Metric | ~ | Vishay Dale | CRCW0603604KFKEA
SW1 SW7 SW13 SW19 SW25 SW31 SW37 SW43 SW49 SW55 SW61 SW67 SW73 SW78 SW8 SW14 SW20 SW26 SW32 SW38 SW44 SW50 SW56 SW62 SW68 SW74 SW79 SW9 SW15 SW21 SW27 SW33 SW39 SW45 SW51 SW57 SW63 SW69 SW75 SW80 SW4 SW10 SW16 SW22 SW28 SW34 SW40 SW46 SW52 SW58 SW64 SW70 SW76 SW81 SW5 SW11 SW17 SW23 SW29 SW35 SW41 SW47 SW53 SW59 SW65 SW71 SW77 SW82 SW6 SW12 SW18 SW24 SW30 SW36 SW42 SW3 SW2 SW48 SW54 SW60 SW66 SW72 | 82 | Choc | keyswitches:PG1350 |  | Kailh | Choc
SW83 | 1 | RESET | Button_Switch_SMD:SW_Push_1P1T_NO_CK_KMR2 | ~ | C&K | KMR221GLFS
SW84 | 1 | SW_DIP_x01 | Button_Switch_SMD:SW_DIP_SPSTx01_Slide_Omron_A6S-110x_W8.9mm_P2.54mm | ~ | Omron | A6S-1101-H
U1 | 1 | ATMEGA32U4-AU | Housings_QFP:TQFP-44_10x10mm_Pitch0.8mm |  | Microchip | ATMEGA32U4-AU
U2 | 1 | TPS61185 | Package_DFN_QFN:VQFN-24-1EP_4x4mm_P0.5mm_EP2.45x2.45mm |  | Texas Instruments | TPS61185
Y1 | 1 | 16MHz | Crystals:Crystal_SMD_3225-4pin_3.2x2.5mm_HandSoldering |  | Abracon | ABM8AIG-16.000MHz-4-T

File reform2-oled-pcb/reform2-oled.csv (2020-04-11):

Reference | Quantity | Value | Footprint | Datasheet | Manufacturer | Manufacturer_No
C3 C4 | 2 | 10uF | Capacitor_SMD:C_0603_1608Metric_Pad1.05x0.95mm_HandSolder |  | Taiyo Yuden | LMK107BBJ106KALT
C5 C6 C1 C2 C7 | 5 | 1uF | Capacitor_SMD:C_0603_1608Metric_Pad1.05x0.95mm_HandSolder |  | Taiyo Yuden | UMK107BJ105KA-T
GFX1 | 1 | MNT | reform2:mntreform | ~
H1 | 1 | MH1 | MountingHole:MountingHole_2.2mm_M2_Pad | ~
H2 | 1 | MH2 | MountingHole:MountingHole_2.2mm_M2_Pad | ~
J1 | 1 | AUX | Connector_FFC-FPC:Molex_200528-0040_1x04-1MP_P1.00mm_Horizontal |  | Molex | 200528-0040
R1 | 1 | 330k | Resistor_SMD:R_0603_1608Metric_Pad1.05x0.95mm_HandSolder |  | Yageo | AF0603FR-07330KL
R2 | 1 | 4.7k | Resistor_SMD:R_0603_1608Metric_Pad1.05x0.95mm_HandSolder |  | Yageo | RC0603FR-074K7L
U1 | 1 | SSD1306 | KiCad-SSD1306_OLED-0:SSD1306_OLED-0.91-128x32

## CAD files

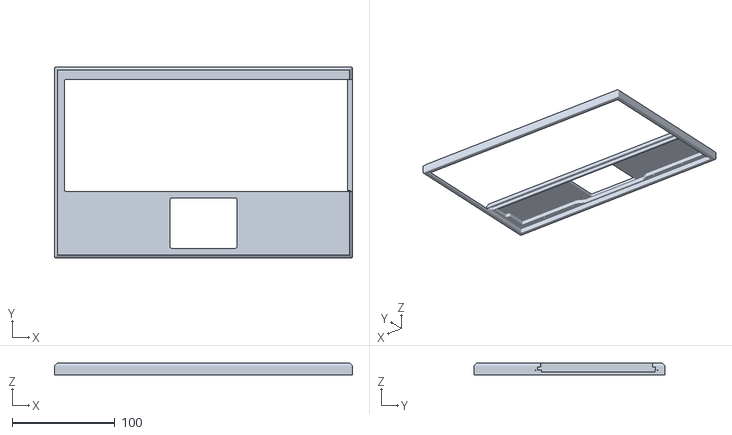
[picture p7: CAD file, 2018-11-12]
historic-reform1/case-parts/main box_top_v2.STL
290.0 x 186.0 x 12.0

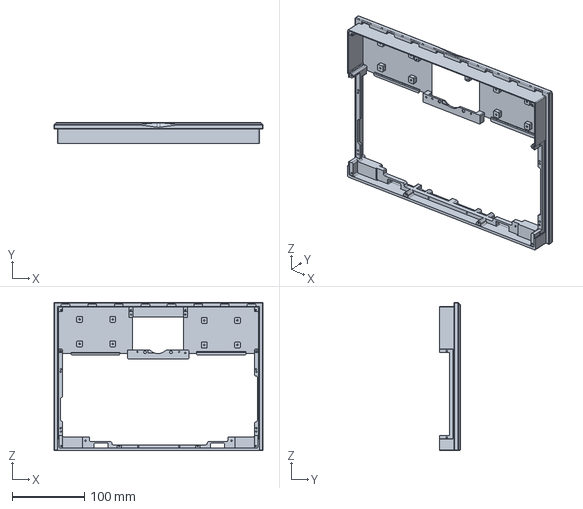
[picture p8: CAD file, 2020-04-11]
reform2-case-cnc/reform2-beta-2d4/main box top_25.02.20.step
290.0 x 29.0 x 205.5 mm

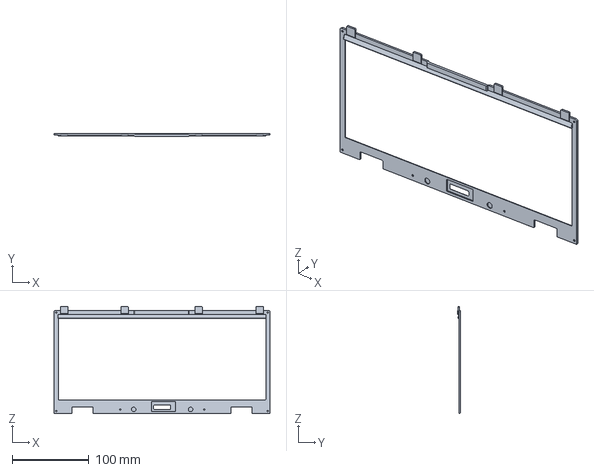
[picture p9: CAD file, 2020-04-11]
reform2-case-cnc/reform2-beta-2d4/closing main box_top_25.02.20.step
280.7 x 4.00 x 139.3 mm

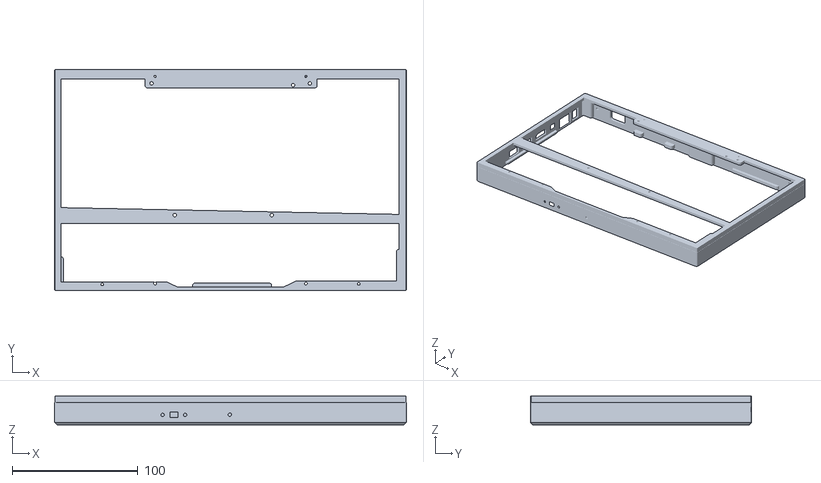
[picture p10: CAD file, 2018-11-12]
historic-reform1/case-parts/main box_bottom_v4.STL
280.0 x 176.0 x 23.0

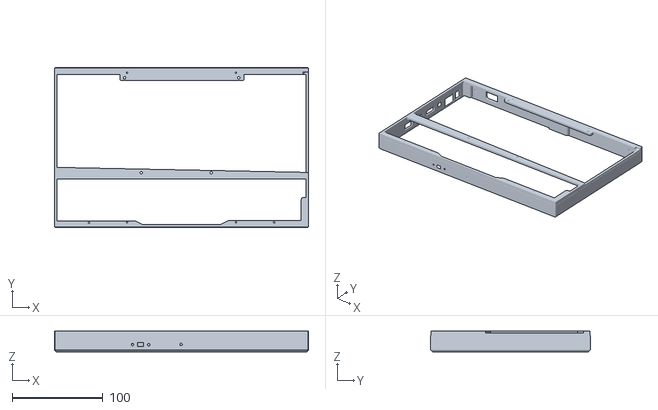
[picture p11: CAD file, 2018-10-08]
historic-reform1/case-parts/main_box_bottom_v3.STL
280.0 x 176.0 x 23.0

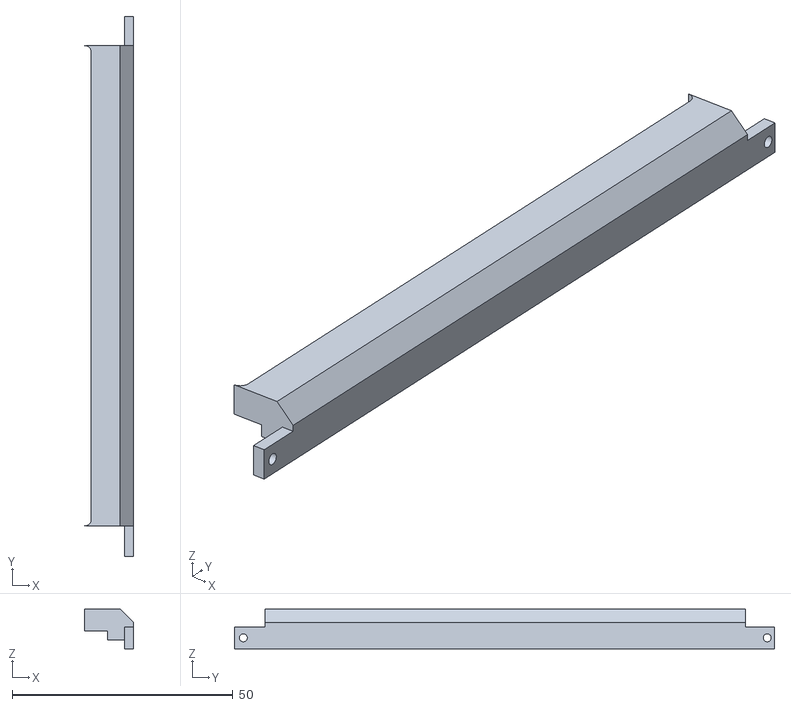
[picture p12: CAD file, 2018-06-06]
historic-reform1/case-parts/main box_closing_v2.STL
11.1 x 122.3 x 9.00

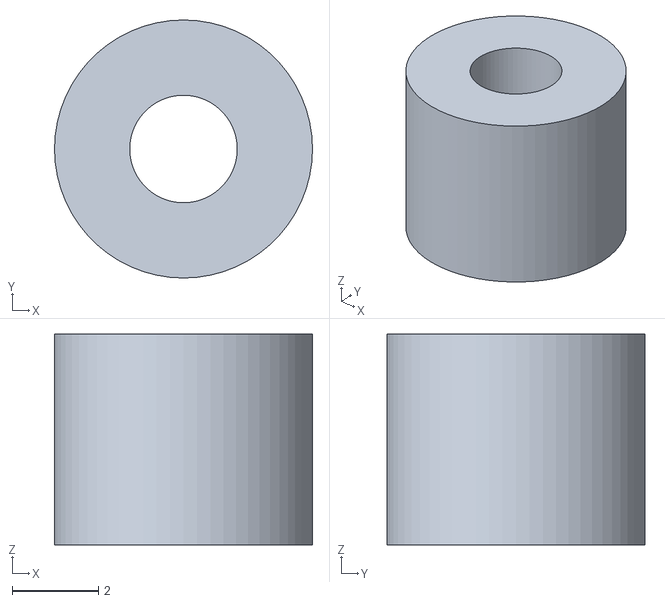
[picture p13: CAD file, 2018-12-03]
historic-reform1/case-parts/trackball-spacer.stl
6.00 x 6.00 x 4.90

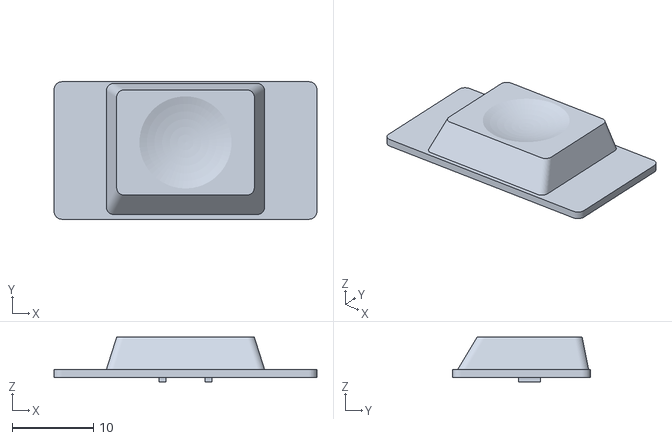
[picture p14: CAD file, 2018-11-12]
historic-reform1/keycaps/ctrl-new.stl
32.4 x 17.0 x 5.50

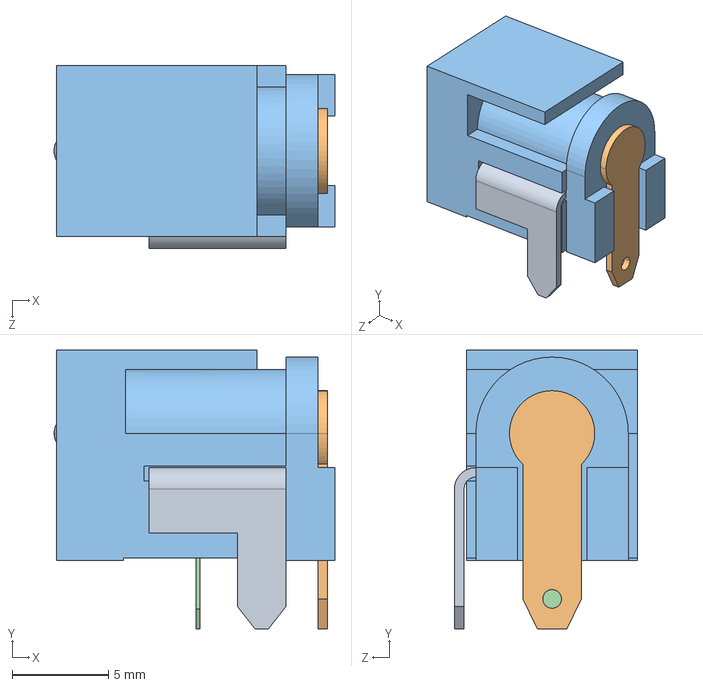
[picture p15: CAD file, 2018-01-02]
historic-reform1/reform-motherboard/693072010801/SW3dPS-rapc722.STEP
14.6 x 14.5 x 9.52 mm

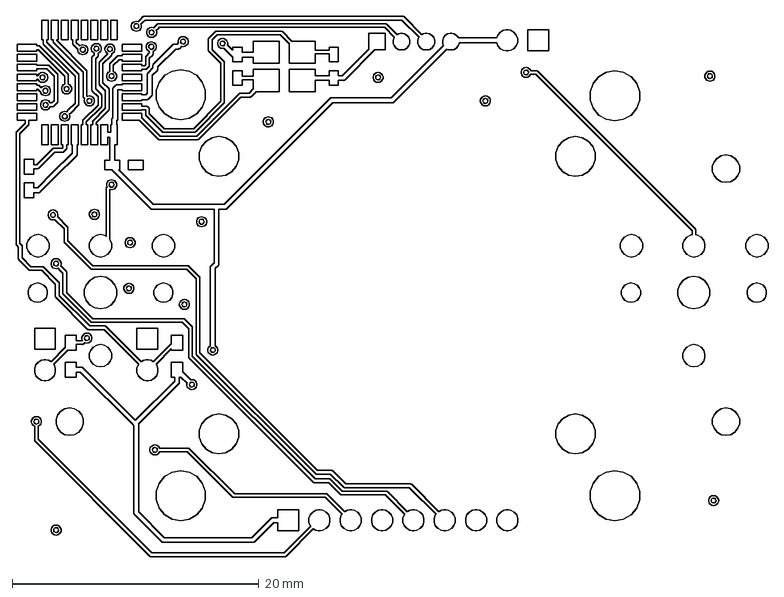
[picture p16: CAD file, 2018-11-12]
historic-reform1/reform-trackball-pcb/dxf/#reform-trackball-F.Cu.dxf
61.0 x 43.8 mm

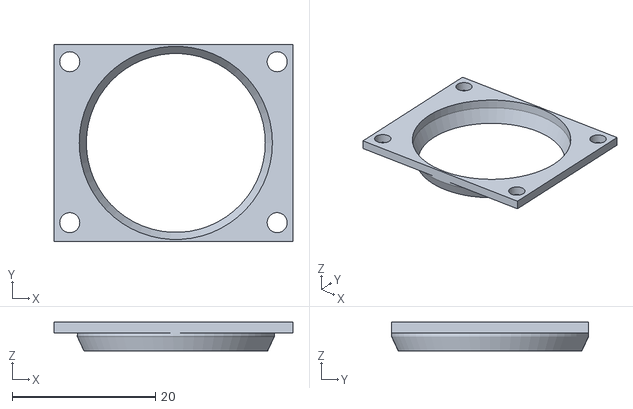
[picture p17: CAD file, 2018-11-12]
historic-reform1/trackball-parts/trackball_cap.stl
33.4 x 27.6 x 4.00

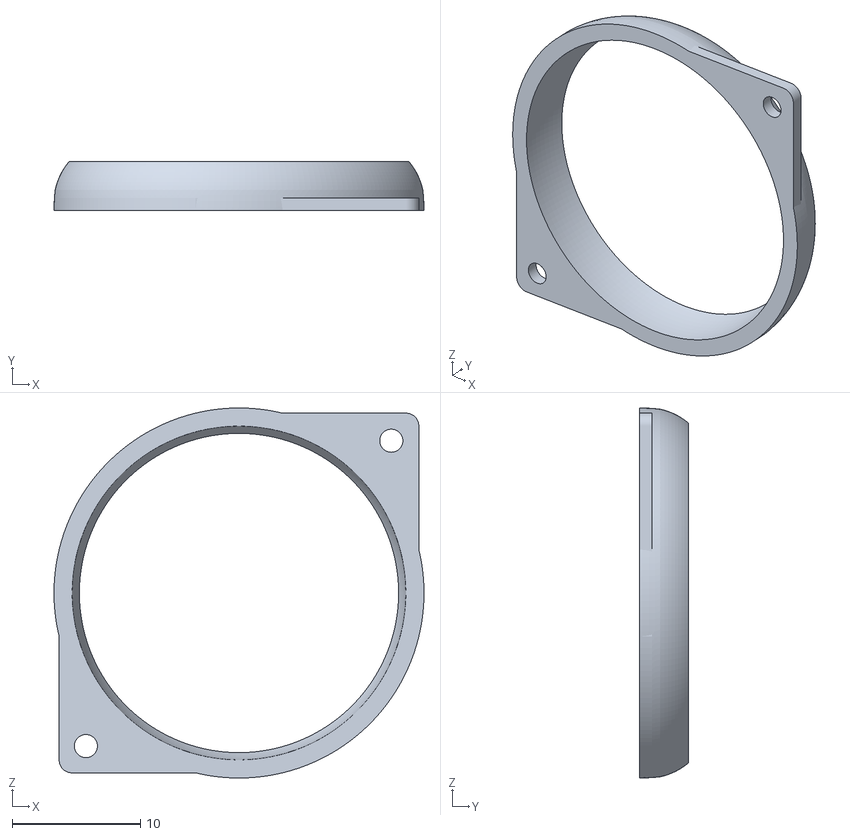
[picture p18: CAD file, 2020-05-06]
reform2-3d-printed-parts/historic-reform2-stl-2d4/trackball lid 20191007.stl
28.8 x 3.83 x 28.8

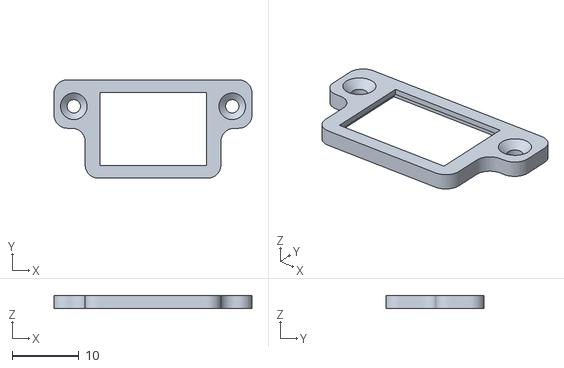
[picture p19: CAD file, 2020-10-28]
reform2-3d-printed-parts/speakers/reform2-speaker-closer-20201005.stl
29.7 x 14.8 x 2.00

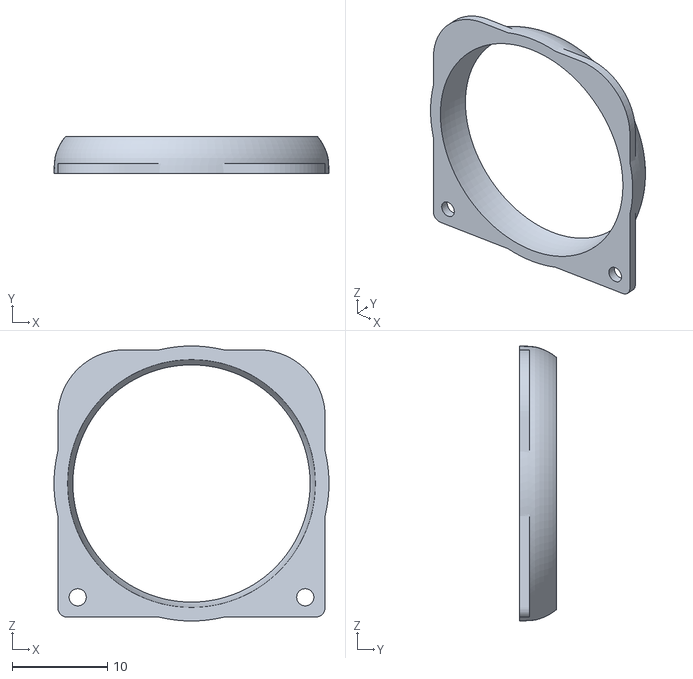
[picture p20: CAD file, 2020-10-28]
reform2-3d-printed-parts/trackball/reform2-trackball-lid-20201005.stl
28.8 x 3.83 x 28.8

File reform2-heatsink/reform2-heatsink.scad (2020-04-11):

x1 = 8;
y1 = 4;

x2 = x1+23;
y2 = y1+10;

x3 = x2+12.75;
y3 = y2+60;

sink_width = 54;
sink_height = 6;
sink_depth = 25+y3+1;

fins_y = 20.5;
fin_width = sink_width+2;
fin_thickness = 2;
fin_spacing = 3;
fin_depth = sink_height-2;

module screw_hole(x,y,height) {
  shh=3;
  translate([x,y,height])   cylinder(h=shh, r=5/2, center = true, $fn=40);
  translate([x,y,height/2]) cylinder(h=height+1, r=2.2/2, center = true, $fn=20);
}

union() {
difference() {
  cube([sink_width,sink_depth,sink_height]);
  
  screw_hole(x1,y1,sink_height);
  screw_hole(x2,y1,sink_height);
  screw_hole(x3,y2,sink_height);
  screw_hole(x3,y3,sink_height);
  
  for (i = [-4 : -2]) {
    translate([-1,fins_y+i*fin_spacing,sink_height-fin_depth]) cube([fin_width-15,fin_thickness,fin_depth+1]);
  }
  
  for (i = [-1 : 16]) {
    translate([-1,fins_y+i*fin_spacing,sink_height-fin_depth]) cube([fin_width,fin_thickness,fin_depth+1]);
  }
  
  for (i = [17 : 18]) {
    translate([-1,fins_y+i*fin_spacing,sink_height-fin_depth]) cube([fin_width-15,fin_thickness,fin_depth+1]);
  }
  
  for (i = [19 : 25]) {
    translate([-1,fins_y+i*fin_spacing,sink_height-fin_depth]) cube([fin_width,fin_thickness,fin_depth+1]);
  }
  
  //translate([42.5,1.5,6.5]) linear_extrude(height = 2, center = true, convexity = 10) scale(0.12) import(file = "mnt.svg");
}

// cpu contact pad
translate([x3-17-15,y2+18.6-3.2,-1]) color([1,0,0]) cube([17,17,1]);
}

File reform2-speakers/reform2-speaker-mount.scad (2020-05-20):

translate([0,20,0])
union() {
    difference() {
        translate([-1,0,0]) cube([22,13.5,1]);
        translate([1.5,1.75,-0.5]) cube([15,10,2]);
    }

    translate([-5.5,0,0]) 
    union() {
        difference() {
            translate([0,0,-1]) cube([5,13.5,2]);
            translate([2.5,4.25,0.5]) cylinder(h = 4, r1 = 1.5, r2 = 1, 
                $fn = 20, center = true);
            translate([2.5,9.5,0.5]) cylinder(h = 4, r1 = 1.5, r2 = 1, 
                $fn = 20, center = true);
        }
    }
    
    translate([19,0,-1.5])
    cube([2,13.5,1.5]);
}

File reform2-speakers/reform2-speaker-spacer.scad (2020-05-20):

difference() {
    cube([18.5,13.5,1]);
    translate([1.75,1.75,-0.5]) cube([15,10,2]);
}

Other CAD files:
reform2-case-cnc/reform2-production-case-20201013/mntreform2-main-box-20201008.step
historic-reform1/reform-trackball-pcb/pcb tracking ball_shape.dxf
reform2-3d-printed-parts/trackpad/reform2-trackpad-support-20201005.stl
reform2-batterypack-pcb/3d-models/KEYSTONE 54 A.step
historic-reform1/case-parts/screen-front-v4b.scad
historic-reform1/case-parts/battery_holder_modified.blend
historic-reform1/case-parts/battery_holder_modified2.stl
historic-reform1/case-parts/screen support bottom_v3.STL
historic-reform1/case-parts/screen support closing.STL
historic-reform1/case-parts/screen_back_3dprint.STL
historic-reform1/case-parts/screen_front_v3.STL
historic-reform1/case-parts/trackball-spacer.scad
historic-reform1/keycaps/back space_final.STL
historic-reform1/keycaps/base keyboard stabilizer_C.STL
historic-reform1/keycaps/base keyboard stabilizer_U.STL
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

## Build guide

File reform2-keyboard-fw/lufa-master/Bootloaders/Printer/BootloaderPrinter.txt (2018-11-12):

/** \file
 *
 *  This file contains special DoxyGen information for the generation of the main page and other special
 *  documentation pages. It is not a project source file.
 */

/** \mainpage Printer Class USB AVR Bootloader
 *
 *  \section Sec_Compat Demo Compatibility:
 *
 *  The following list indicates what microcontrollers are compatible with this demo.
 *
 *  \li Series 7 USB AVRs (AT90USBxxx7)
 *  \li Series 6 USB AVRs (AT90USBxxx6)
 *  \li Series 4 USB AVRs (ATMEGAxxU4)
 *  \li Series 2 USB AVRs (AT90USBxx2, ATMEGAxxU2)
 *
 *  \section Sec_Info USB Information:
 *
 *  The following table gives a rundown of the USB utilization of this demo.
 *
 *  <table>
 *   <tr>
 *    <td><b>USB Mode:</b></td>
 *    <td>Device</td>
 *   </tr>
 *   <tr>
 *    <td><b>USB Class:</b></td>
 *    <td>Printer Class</td>
 *   </tr>
 *   <tr>
 *    <td><b>USB Subclass:</b></td>
 *    <td>Printer Subclass</td>
 *   </tr>
 *   <tr>
 *    <td><b>Relevant Standards:</b></td>
 *    <td>USBIF Printer Class Standard</td>
 *   </tr>
 *   <tr>
 *    <td><b>Supported USB Speeds:</b></td>
 *    <td>Full Speed Mode</td>
 *   </tr>
 *  </table>
 *
 *  \section Sec_Description Project Description:
 *
 *  This bootloader enumerates to the host as a Generic Text Only Printer device, capable of reading and parsing
 *  "printed" plain-text Intel HEX files to load firmware onto the AVR.
 *
 *  Out of the box this bootloader builds for the AT90USB1287 with an 8KB bootloader section size, and will fit
 *  into 4KB of bootloader space. If you wish to alter this size and/or change the AVR model, you will need to
 *  edit the MCU, FLASH_SIZE_KB and BOOT_SECTION_SIZE_KB values in the accompanying makefile.
 *
 *  When the bootloader is running, the board's LED(s) will flash at regular intervals to distinguish the
 *  bootloader from the normal user application.
 *
 *  \section Sec_Running Running the Bootloader
 *
 *  On the USB AVR8 devices, setting the \c HWBE device fuse will cause the bootloader to run if the \c HWB pin of
 *  the AVR is grounded when the device is reset.
 *
 *  The are two behaviours of this bootloader, depending on the device's fuses:
 *
 *  <b>If the device's BOOTRST fuse is set</b>, the bootloader will run any time the system is reset from
 *  the external reset pin, unless no valid user application has been loaded. To initiate the bootloader, the
 *  device's external reset pin should be grounded momentarily.
 *
 *  <b>If the device's BOOTRST fuse is not set</b>, the bootloader will run only if initiated via a software
 *  jump, or if the \c HWB pin was low during the last device reset (if the \c HWBE fuse is set).
 *
 *  For board specific exceptions to the above, see below.
 *
 *  \subsection SSec_XPLAIN Atmel Xplain Board
 *  Ground the USB AVR JTAG's \c TCK pin to ground when powering on the board to start the bootloader. This assumes the
 *  \c HWBE fuse is cleared and the \c BOOTRST fuse is set as the HWBE pin is not user accessible on this board.
 *
 *  \subsection SSec_Leonardo Arduino Leonardo Board
 *  Ground \c IO13 when powering the board to start the bootloader. This assumes the \c HWBE fuse is cleared and the
 *  \c BOOTRST fuse is set as the HWBE pin is not user accessible on this board.
 *
 *  \section Sec_Installation Driver Installation
 *
 *  This bootloader uses the Generic Text-Only printer drivers inbuilt into all modern operating systems, thus no
 *  additional drivers need to be supplied for correct operation.
 *
 *  \section Sec_HostApp Host Controller Application
 *
 *  This bootloader is compatible with Notepad under Windows, and the command line \c lpr utility under Linux.
 *
 *  \subsection SSec_Notepad Notepad (Windows)
 *
 *  While most text applications under Windows will be compatible with the bootloader, the inbuilt Notepad utility
 *  is recommended as it will introduce minimal formatting changes to the output stream. To program with Notepad,
 *  open the target HEX file and print it to the Generic Text Only printer device the bootloader creates.
 *
 *  \subsection SSec_LPR LPR (Linux)
 *
 *  While the CUPS framework under Linux will enumerate the bootloader as a Generic Text-Only printer, many
 *  applications will refuse to print to the device due to the lack of rich formatting options available. As a result,
 *  under Linux HEX files must be printed via the low level \c lpr utility instead.
 *
 *  \code
 *  cat Mouse.hex | lpr
 *  \endcode
 *
 *  \section Sec_API User Application API
 *
 *  Several user application functions for FLASH and other special memory area manipulations are exposed by the bootloader,
 *  allowing the user application to call into the bootloader at runtime to read and write FLASH data.
 *
 *  By default, the bootloader API jump table is located 32 bytes from the end of the device's FLASH memory, and follows the
 *  following layout:
 *
 *  \code
 *  #define BOOTLOADER_API_TABLE_SIZE          32
 *  #define BOOTLOADER_API_TABLE_START         ((FLASHEND + 1UL) - BOOTLOADER_API_TABLE_SIZE)
 *  #define BOOTLOADER_API_CALL(Index)         (void*)((BOOTLOADER_API_TABLE_START + (Index * 2)) / 2)
 *
 *  void    (*BootloaderAPI_ErasePage)(uint32_t Address)               = BOOTLOADER_API_CALL(0);
 *  void    (*BootloaderAPI_WritePage)(uint32_t Address)               = BOOTLOADER_API_CALL(1);
 *  void    (*BootloaderAPI_FillWord)(uint32_t Address, uint16_t Word) = BOOTLOADER_API_CALL(2);
 *  uint8_t (*BootloaderAPI_ReadSignature)(uint16_t Address)           = BOOTLOADER_API_CALL(3);
 *  uint8_t (*BootloaderAPI_ReadFuse)(uint16_t Address)                = BOOTLOADER_API_CALL(4);
 *  uint8_t (*BootloaderAPI_ReadLock)(void)                            = BOOTLOADER_API_CALL(5);
 *  void    (*BootloaderAPI_WriteLock)(uint8_t LockBits)               = BOOTLOADER_API_CALL(6);
 *
 *  #define BOOTLOADER_MAGIC_SIGNATURE_START   (BOOTLOADER_API_TABLE_START + (BOOTLOADER_API_TABLE_SIZE - 2))
 *  #define BOOTLOADER_MAGIC_SIGNATURE         0xDCFB
 *
 *  #define BOOTLOADER_CLASS_SIGNATURE_START   (BOOTLOADER_API_TABLE_START + (BOOTLOADER_API_TABLE_SIZE - 4))
 *  #define BOOTLOADER_PRINTER_SIGNATURE       0xDF20
 *
 *  #define BOOTLOADER_ADDRESS_START           (BOOTLOADER_API_TABLE_START + (BOOTLOADER_API_TABLE_SIZE - 8))
 *  #define BOOTLOADER_ADDRESS_LENGTH          4
 *  \endcode
 *
 *  From the application the API support of the bootloader can be detected by reading the FLASH memory bytes located at address
 *  \c BOOTLOADER_MAGIC_SIGNATURE_START and comparing them to the value \c BOOTLOADER_MAGIC_SIGNATURE. The class of bootloader
 *  can be determined by reading the FLASH memory bytes located at address \c BOOTLOADER_CLASS_SIGNATURE_START and comparing them
 *  to the value \c BOOTLOADER_PRINTER_SIGNATURE. The start address of the bootloader can be retrieved by reading the bytes of FLASH
 *  memory starting from address \c BOOTLOADER_ADDRESS_START.
 *
 *  \subsection SSec_API_MemLayout Device Memory Map
 *  The following illustration indicates the final memory map of the device when loaded with the bootloader.
 *
 *  \verbatim
 *  +----------------------------+ 0x0000
 *  |                            |
 *  |                            |
 *  |                            |
 *  |                            |
 *  |                            |
 *  |                            |
 *  |                            |
 *  |                            |
 *  |      User Application      |
 *  |                            |
 *  |                            |
 *  |                            |
 *  |                            |
 *  |                            |
 *  |                            |
 *  |                            |
 *  +----------------------------+ FLASHEND - BOOT_SECTION_SIZE
 *  |                            |
 *  |   Bootloader Application   |
 *  | (Not User App. Accessible) |
 *  |                            |
 *  +----------------------------+ FLASHEND - 96
 *  |   API Table Trampolines    |
 *  | (Not User App. Accessible) |
 *  +----------------------------+ FLASHEND - 32
 *  |    Bootloader API Table    |
 *  |   (User App. Accessible)   |
 *  +----------------------------+ FLASHEND - 8
 *  |   Bootloader ID Constants  |
 *  |   (User App. Accessible)   |
 *  +----------------------------+ FLASHEND
 *  \endverbatim
 *
 *
 *  \section Sec_KnownIssues Known Issues:
 *
 *  \par On Linux machines, new firmware fails to be sent to the device via CUPS.
 *  Only a limited subset of normal printer functionality is exposed via the
 *  bootloader, causing CUPS to reject print requests from applications that
 *  are unable to handle true plain-text printing. For best results, the low
 *  level \c lpr command should be used to print new firmware to the bootloader.
 *
 *  \section Sec_Options Project Options
 *
 *  The following defines can be found in this demo, which can control the demo behaviour when defined, or changed in value.
 *
 *  <table>
 *   <tr>
 *    <td>
 *     None
 *    </td>
 *   </tr>
 *  </table>
 */

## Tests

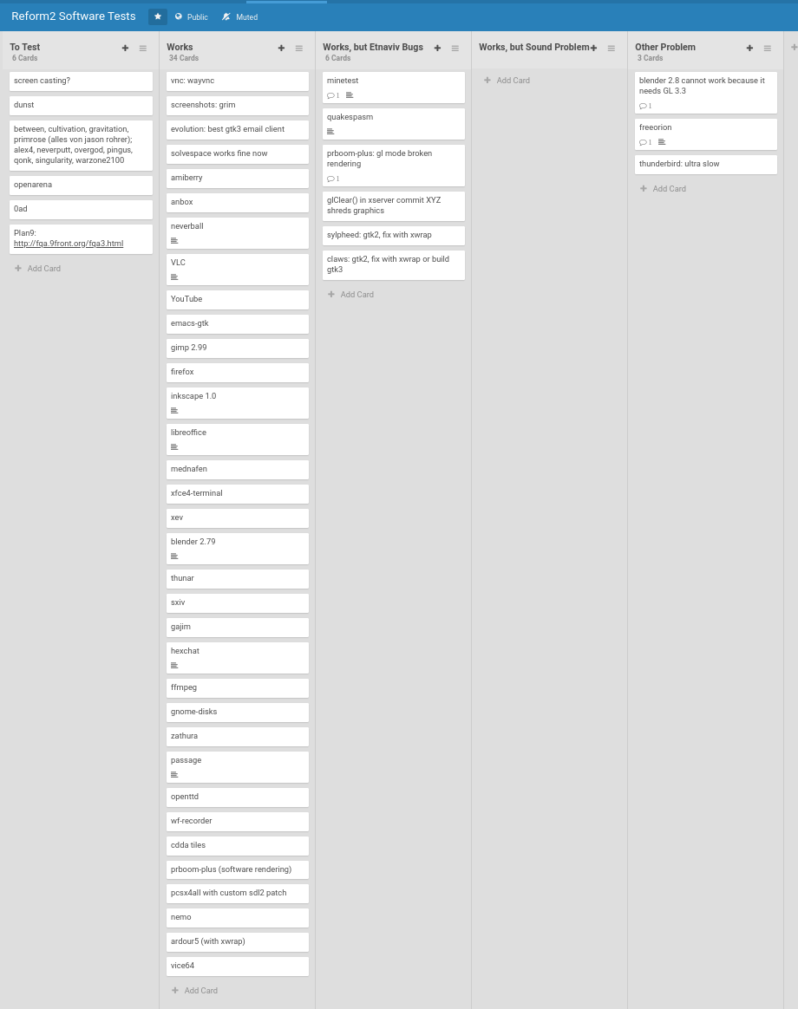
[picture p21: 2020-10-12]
reform2-handbook/misc-content/software-tests.png

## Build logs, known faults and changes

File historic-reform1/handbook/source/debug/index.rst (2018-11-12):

Debugging
=========

Power
-----

The TinyRex module has a red and a green LED. Both have to light up to signal good power.

To troubleshoot power, disconnect the internal battery and all internal and external peripherals, connect the 5V wall adapter. If you want to unplug the TinyRex module, you should take the motherboard out of the case first.

Turn the power switch on. Get a multimeter and find the following voltages in the system:

- **5V** The main input rail. Can be found on pin 1 of J25 or J29.
- **3.3V** The big regulator U4 (AP1501A-33) turns 5V into 3.3V. Check test point TP3 next to the big coil L2.
- **2.5V** Regulated by U11 (LP3962EMP-2.5). Check TP5 next to it.
- **1.5V** Regulated by U13. Check TP12. Needed for PCIe.
- **1.1V** Regulated by U5 near the USB hub U9. Check TP6.

If voltages are way off, there can be a short somewhere on the board which usually generates heat.
  
Serial Console
--------------

The motherboard connector labelled CONSOLE is a serial port (UART) to which U-Boot and the Linux kernel output diagnostic information on startup. The baud rate is 115200.

Wire up a generic USB-to-UART adapter to the following pins of J25 (pin 1 is next to the J25 label):

- **1** 5V, don't connect
- **2** UART1_TXD, connect to RX of your adapter
- **3** UART1_RXD, connect to TX of your adapter
- **4** UART1_RTS, don't connect
- **5** UART1_CTS, don't connect
- **6** GND, connect to GND of your adapter

Then, use a terminal program such as screen on your host computer:

.. code-block:: none

   screen /dev/ttyUSB0 115200

If you then switch on Reform with a prepared SD card inserted, you should see the U-Boot console in *screen*.

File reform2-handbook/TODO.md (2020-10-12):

# MNT Reform: Operator Manual

## TOC

- Preface
- List of existing manuals / references / online communications channels
- Safety / Hazards / Warnings
- Quickstart
  - How to unwrap, plug in, turn on
  - First steps in Debian GNU/Linux
  - Important functions of the default sway-based desktop
    - Windows and workspaces
    - Display brightness
    - CPU/IO/Mem meter
    - Network
    - Audio
    - Date and time
  - (maybe) functions of the alternative GNOME desktop
- Writing a small game/program
  - Creating graphics
  - Making sound
  - Putting it all together
- Software recommendations
  - List of tested productivity applications (creative, office)
  - List of tested communication programs (email, chat, voip)
  - List of tested games
  - List of tested tools
- Reference
  - Electronics
    - Schematics
    - Short explanation of important chips/parts
  - Mechanical
    - Diagram/drawings of mechanical parts
    - Explanation of what connects to what / which screw goes where
  - Common Problems
  - Maintenance
- Credits / Thanks

## Tech

- Sphinx worked well as a generator for the old handbook. Probably we can use it again. I might rather go with markdown than with RSt this time, but this is up for discussion. I'm also OK with looking around for another tool that can do PDF layout.
- We don't have a printing service selected yet, and should do it soon.
- The print format can be unusual, like A4. Ideas welcome.

## Style

- Inspiration: classic computer manuals, like ZX Spectrum, QL, Commodore 64, Amiga 500. But also LISP machines, classic Macintosh. Classic Sony, Nintendo?
- International Typographic Style https://en.wikipedia.org/wiki/International_Typographic_Style
- TODO: Moodboard

## See also

- https://mntre.com/reform2-handbook/system.html
- https://mntre.com/reform2-ibom/reform2-motherboard/ibom.html

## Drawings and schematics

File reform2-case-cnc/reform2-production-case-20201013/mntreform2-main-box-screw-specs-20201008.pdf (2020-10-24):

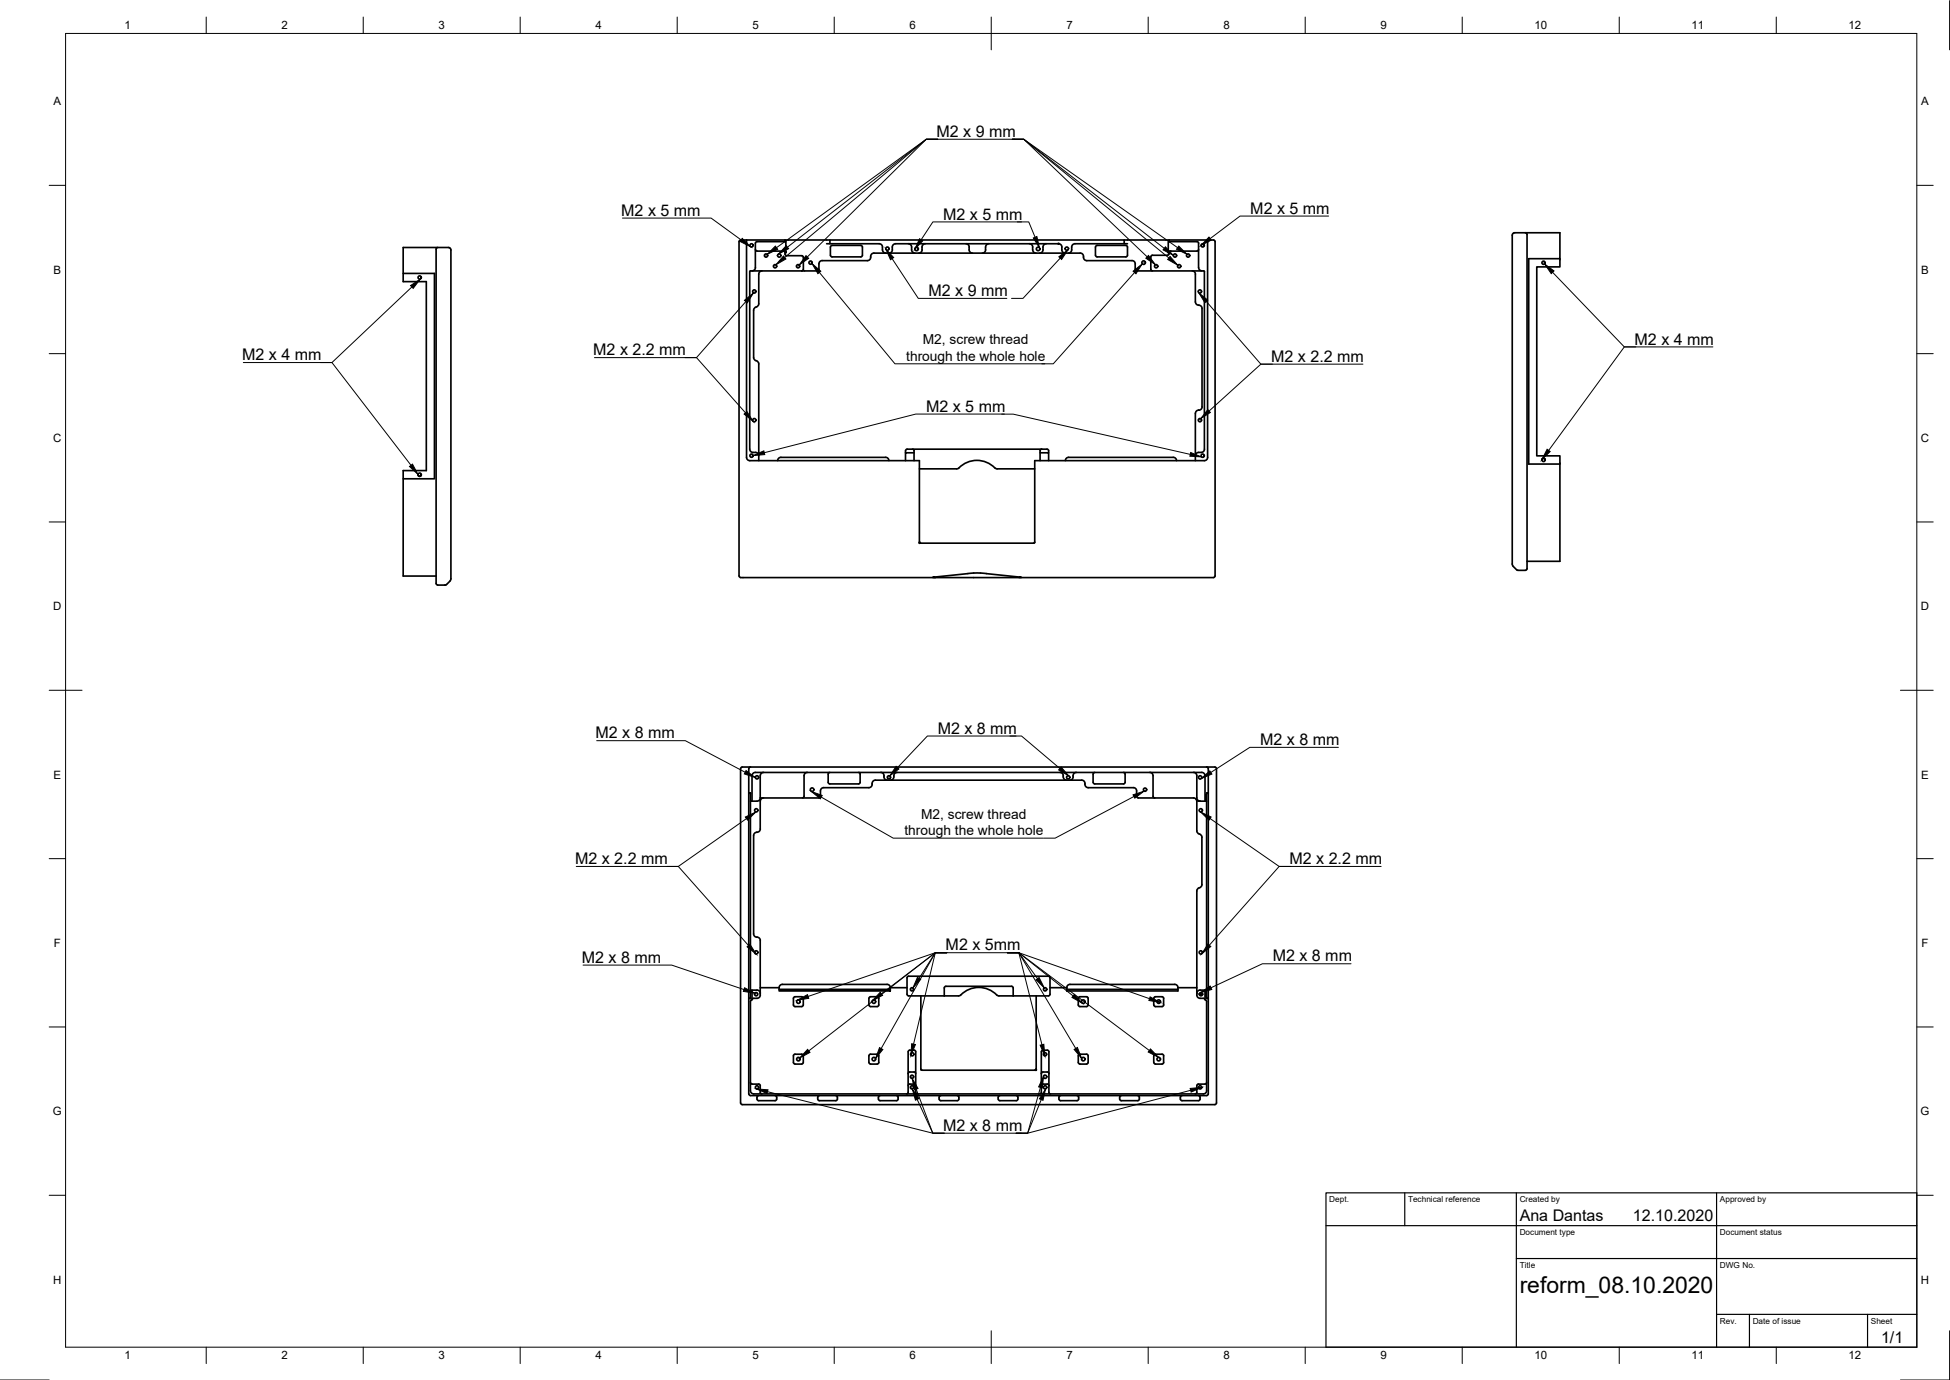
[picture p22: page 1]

M2, screw thread
through the whole hole

Dept. | Technical reference | Created by Ana Dantas 12.10.2020 | Approved by

Document type | Document status

Title reform_08.10.2020 | DWG No.

Rev. | Date of issue | Sheet 1/1

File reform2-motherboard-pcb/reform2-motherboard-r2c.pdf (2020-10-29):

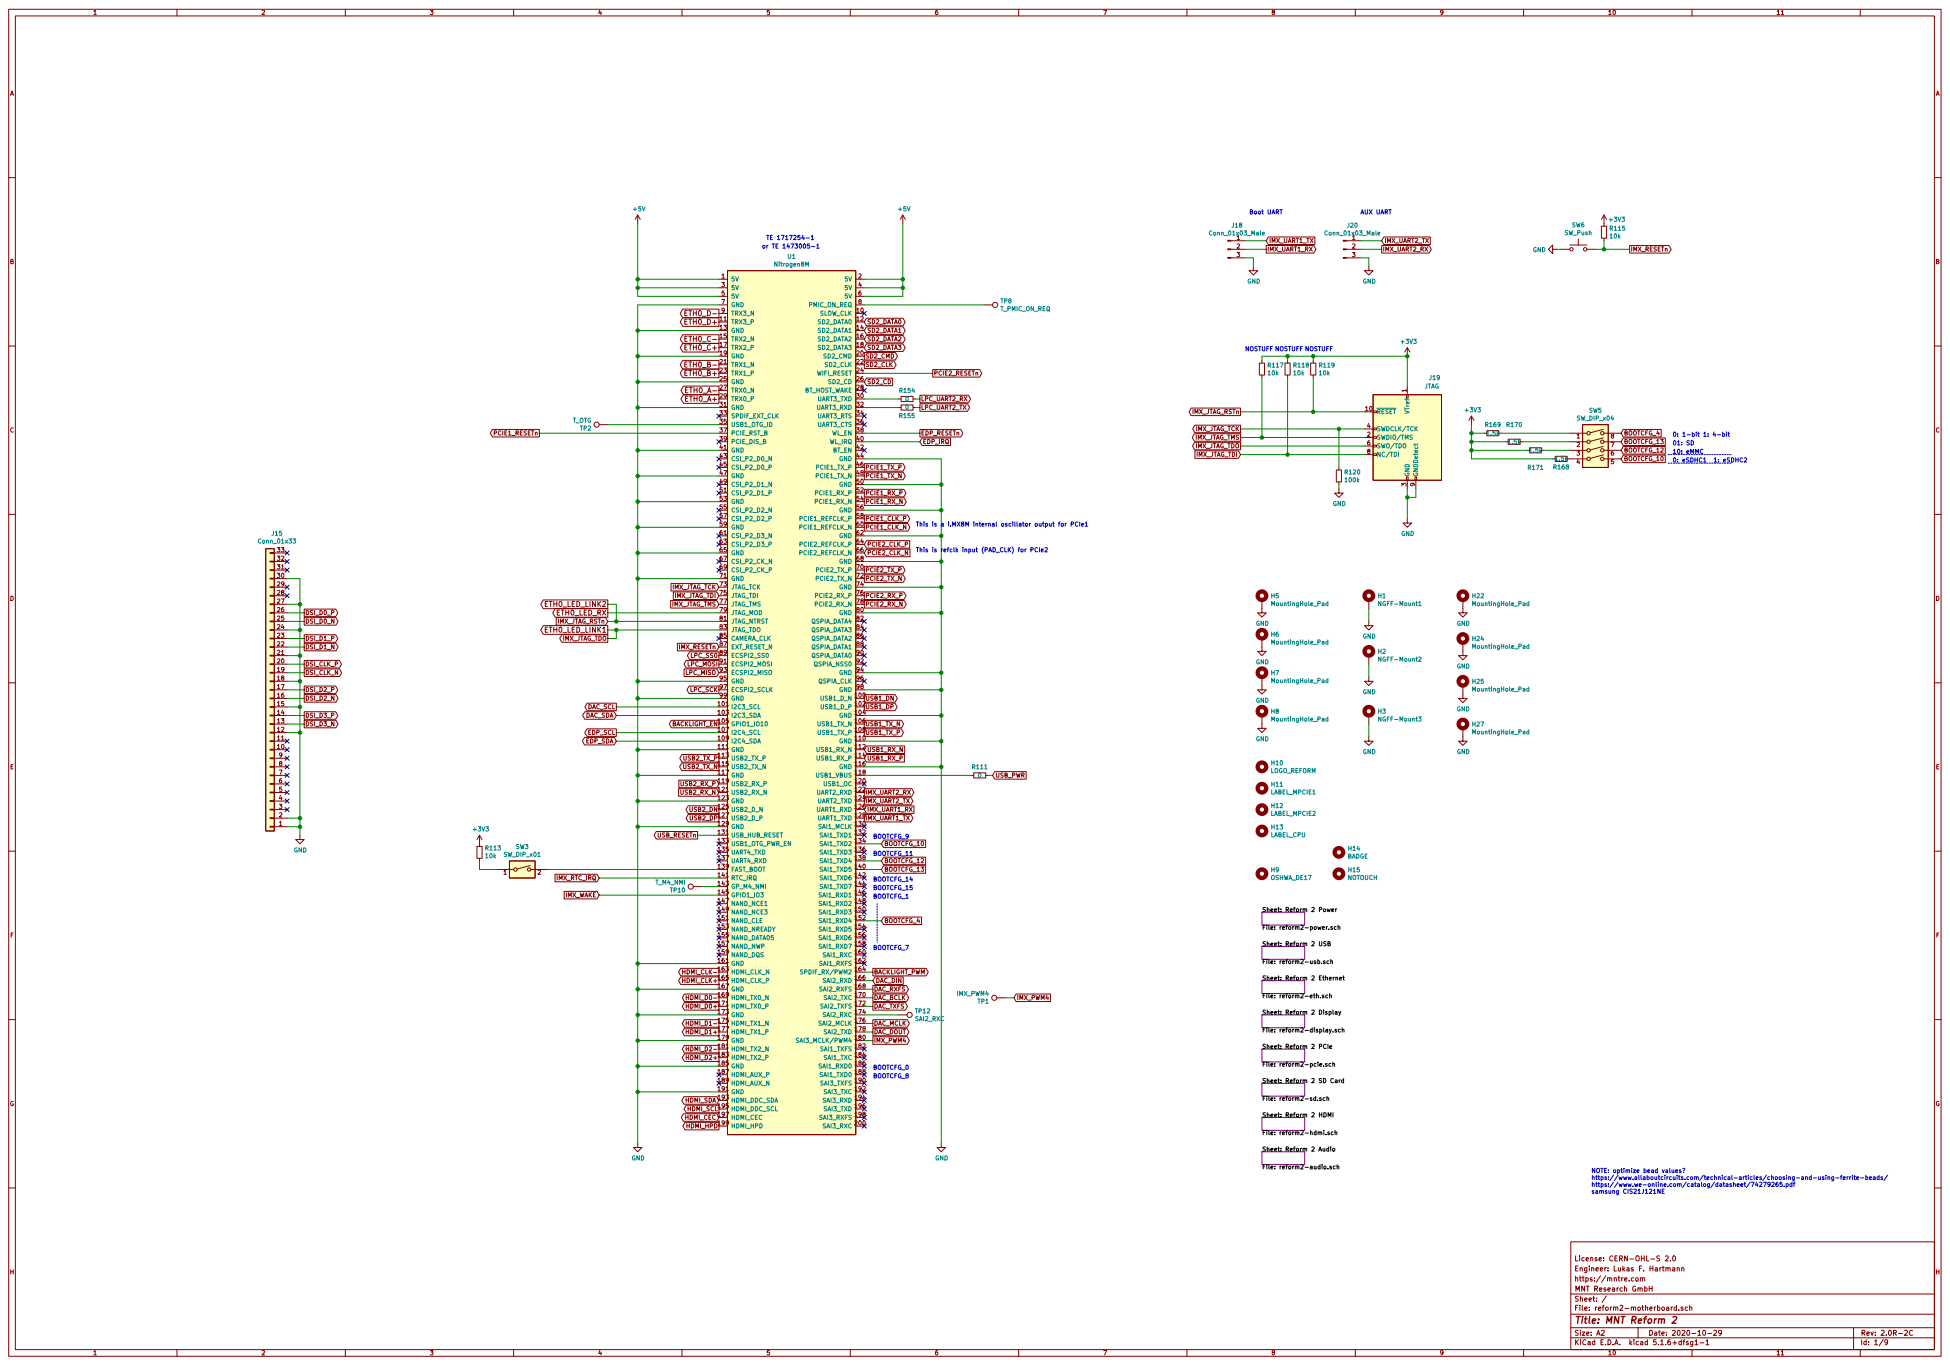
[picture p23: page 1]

This is a i.MX8M internal oscillator output for PCIe1

This is refclk input (PAD_CLK) for PCIe2

File: reform2-display.sch Sheet: Reform 2 Ethernet File: reform2-eth.sch Sheet: Reform 2 USB

License: CERN-OHL-S 2.0 Sheet: Reform 2 Audio File: reform2-audio.sch Sheet: Reform 2 HDMI File: reform2-hdmi.sch Sheet: Reform 2 SD Card File: reform2-sd.sch Sheet: Reform 2 PCIe File: reform2-pcie.sch

NOTE: optimize bead values?
https://www.allaboutcircuits.com/technical-articles/choosing-and-using-ferrite-beads/
https://www.we-online.com/catalog/datasheet/74279265.pdf
samsung CIS21J121NE

Engineer: Lukas F. Hartmann
https://mntre.com
File: reform2-motherboard.sch Sheet: / MNT Research GmbH

Id: 1/9 Title: MNT Reform 2

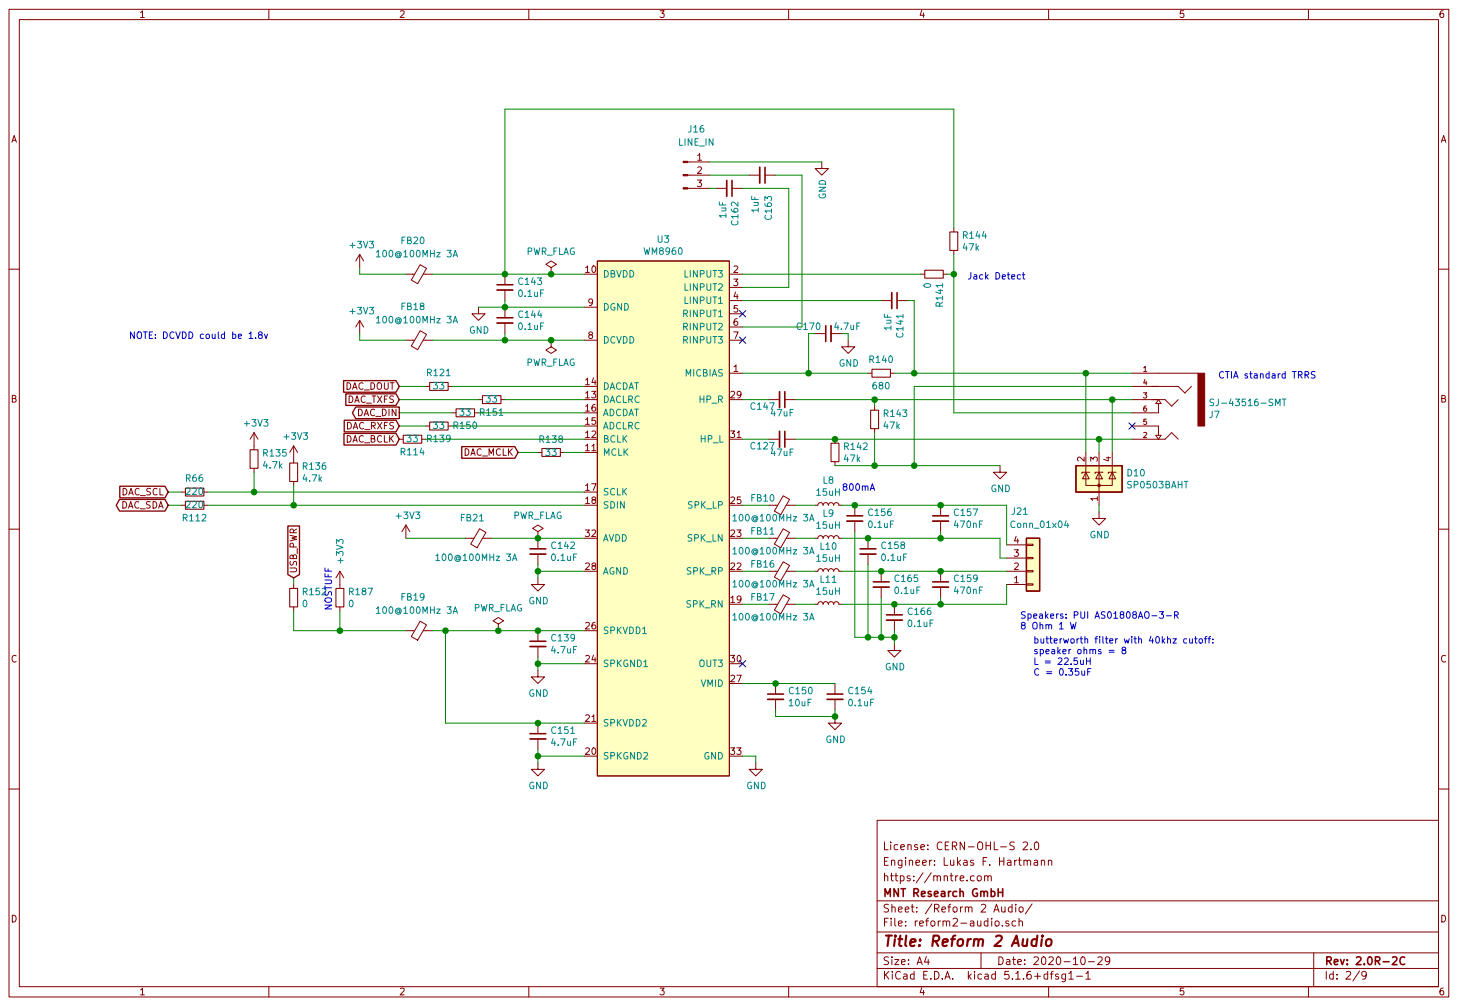
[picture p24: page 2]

C = 0.35uF NOTE: DCVDD could be 1.8v

Speakers: PUI AS01808AO-3-R
8 Ohm 1 W
butterworth filter with 40khz cutoff: speaker ohms = 8

License: CERN-OHL-S 2.0
Engineer: Lukas F. Hartmann
https://mntre.com
File: reform2-audio.sch Sheet: /Reform 2 Audio/ MNT Research GmbH

Id: 2/9 Title: Reform 2 Audio

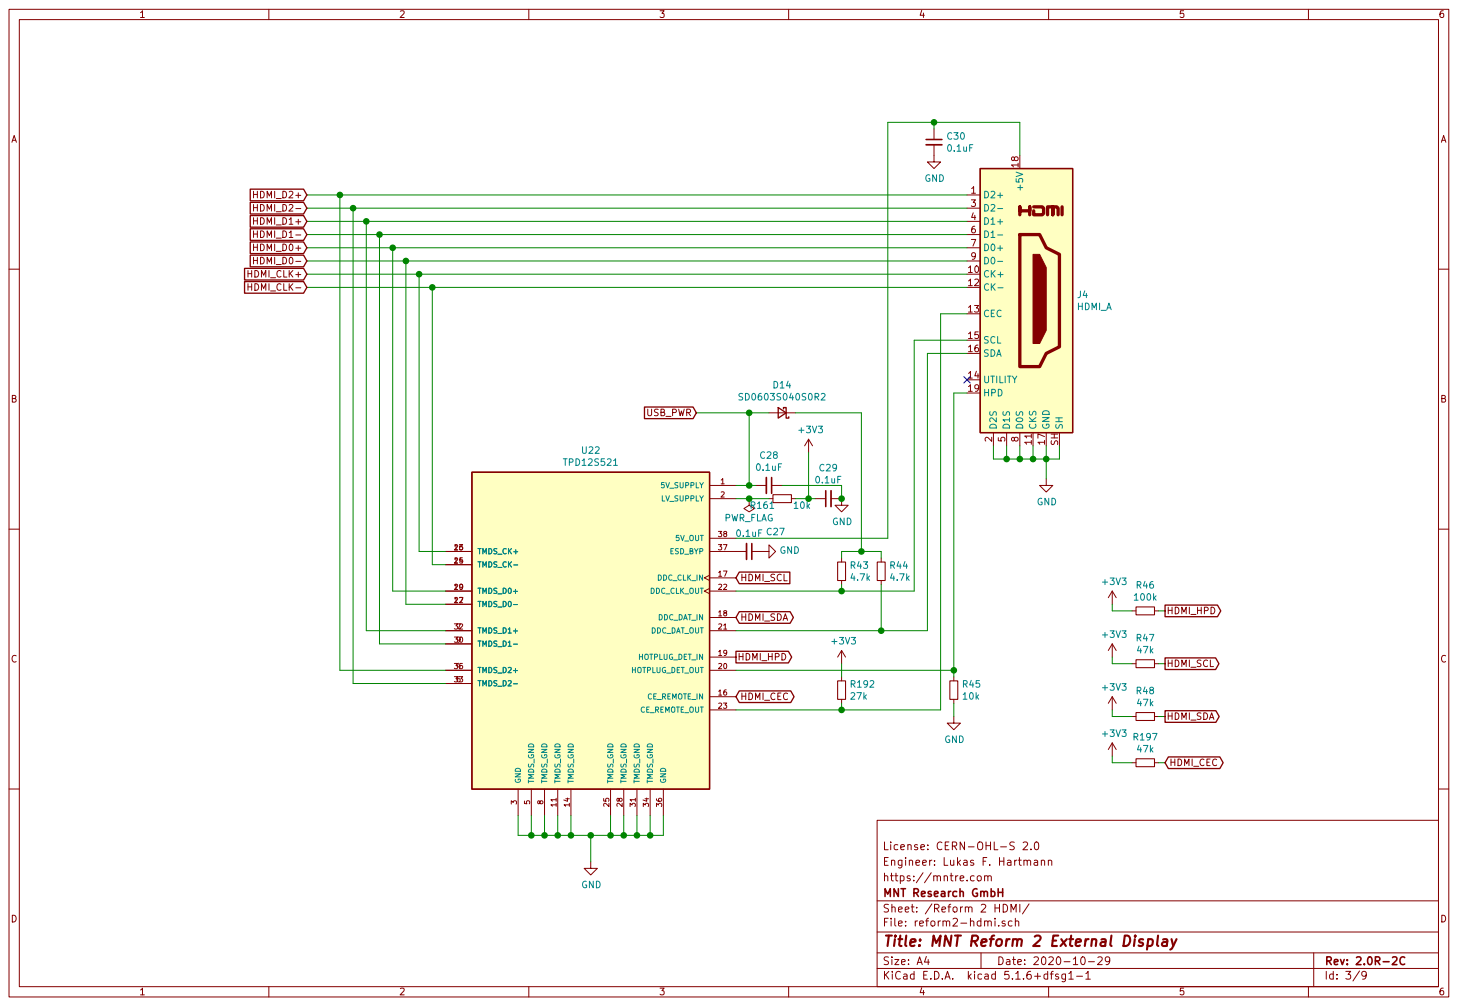
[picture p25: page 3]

License: CERN-OHL-S 2.0 GND

Engineer: Lukas F. Hartmann
https://mntre.com
File: reform2-hdmi.sch Sheet: /Reform 2 HDMI/ MNT Research GmbH

Id: 3/9 Title: MNT Reform 2 External Display

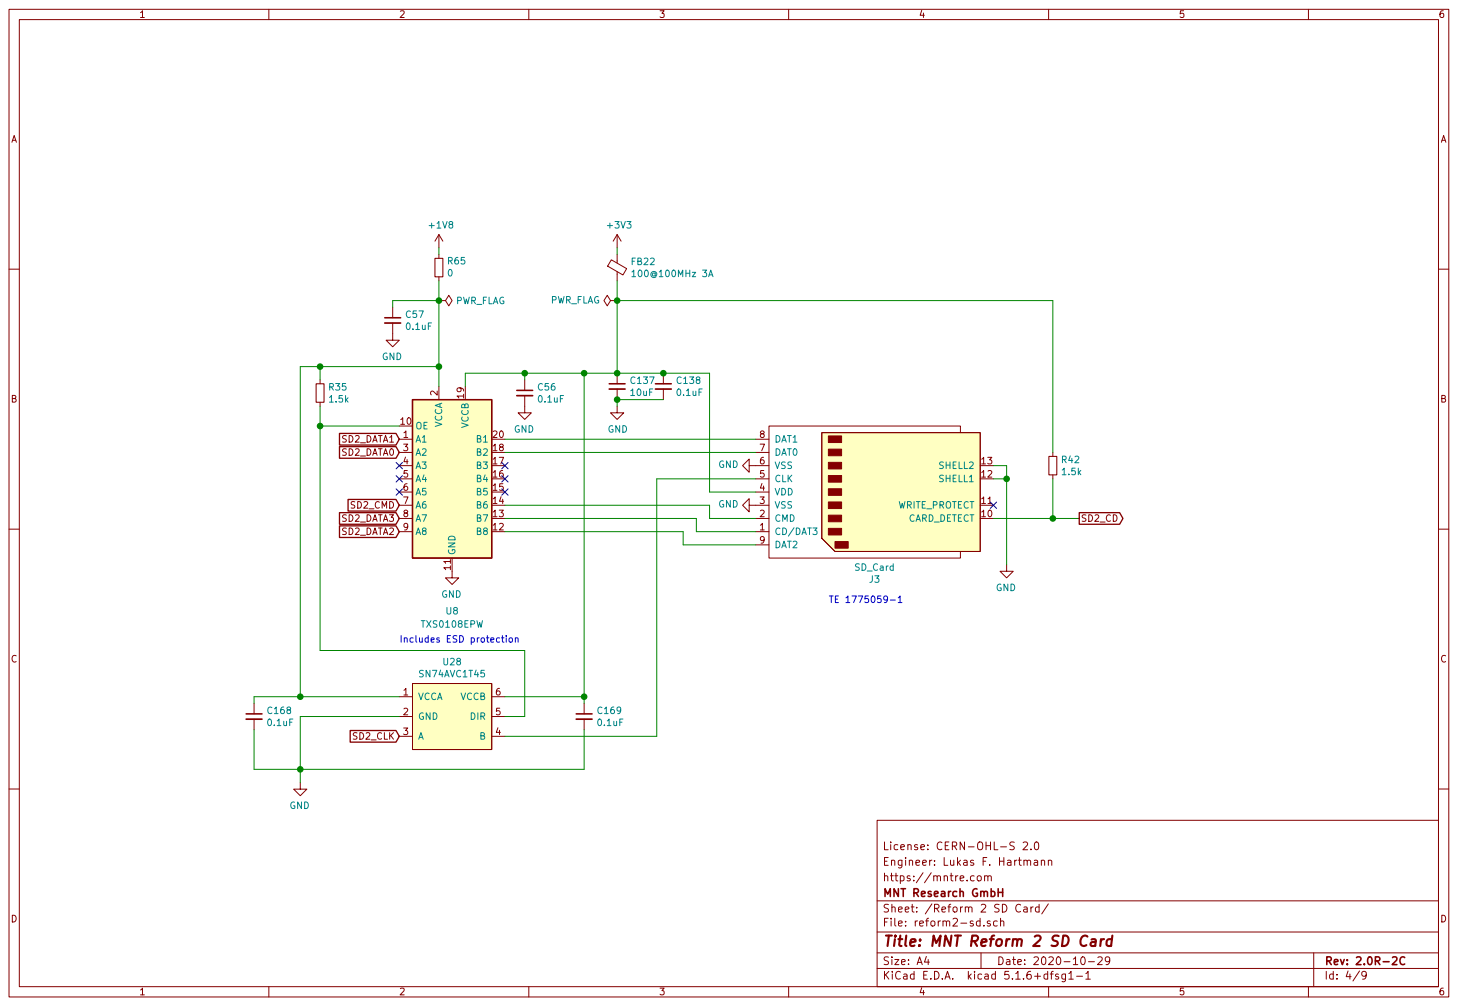
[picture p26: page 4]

License: CERN-OHL-S 2.0 GND

Engineer: Lukas F. Hartmann
https://mntre.com
File: reform2-sd.sch Sheet: /Reform 2 SD Card/ MNT Research GmbH

Id: 4/9 Title: MNT Reform 2 SD Card

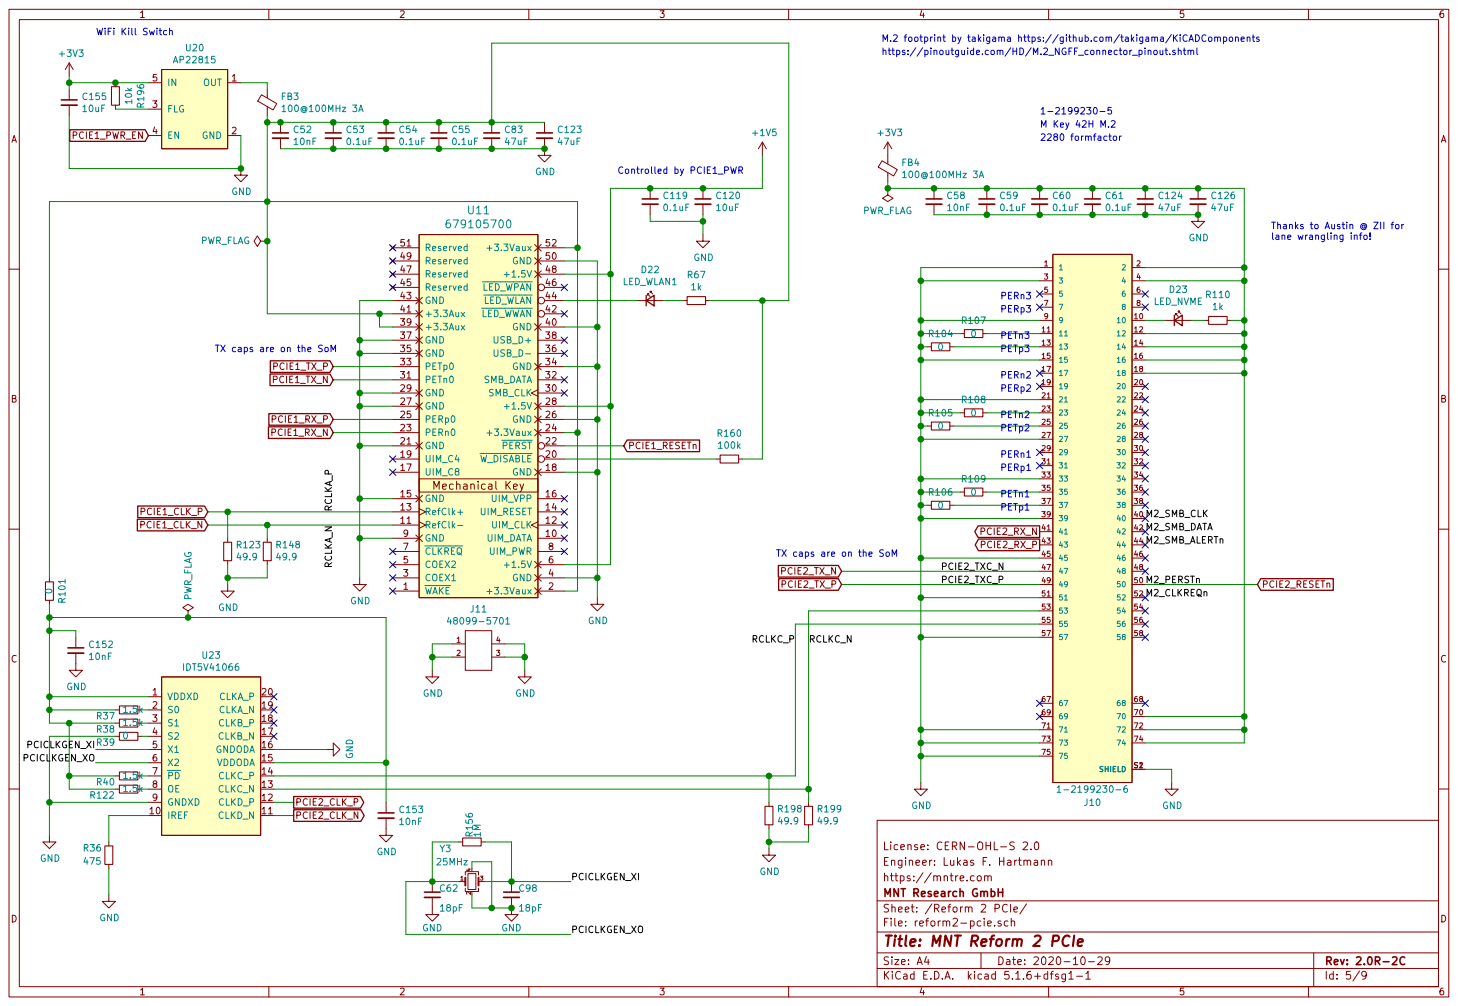
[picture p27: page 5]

1-2199230-5 M.2 footprint by takigama https://github.com/takigama/KiCADComponents

TX caps are on the SoM
PCIE2_TX_N
PCIE2_TX_P

License: CERN-OHL-S 2.0 VDDXD 1

Engineer: Lukas F. Hartmann
https://mntre.com
File: reform2-pcie.sch Sheet: /Reform 2 PCIe/ MNT Research GmbH

Id: 5/9 Title: MNT Reform 2 PCIe

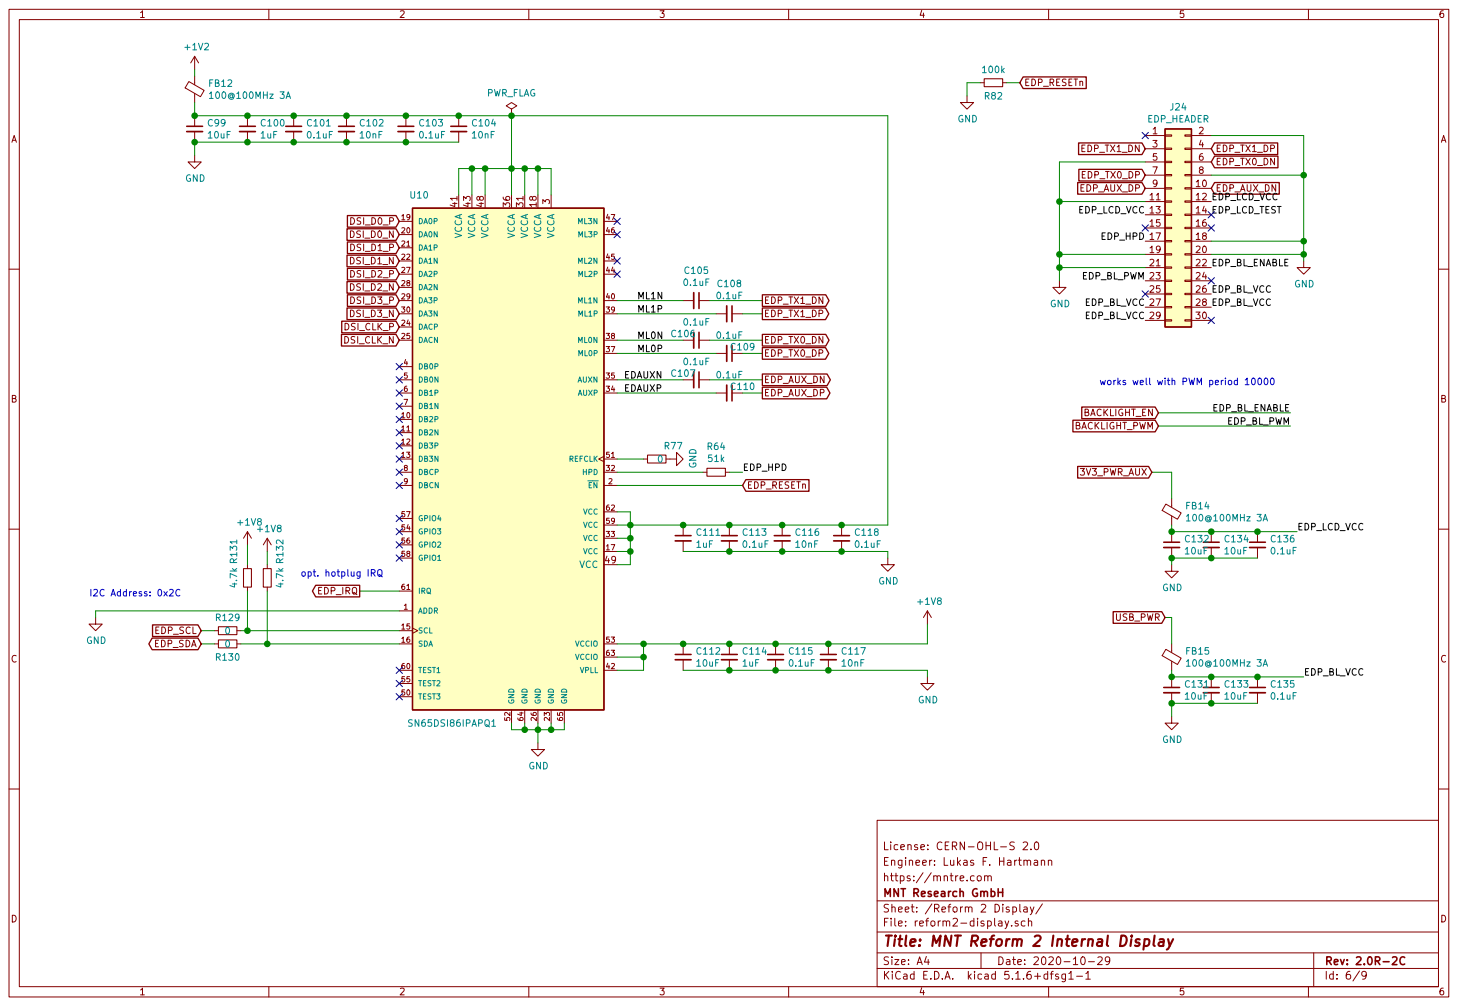
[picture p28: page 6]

3 DA3N 30 VCCA 31 HPD 32 VCC 33 AUXP 34 AUXN 35 VCCA 36 ML0P 37 ML0N 38 ML1P 39 DB0P 4 ML1N 40 VCCA 41

works well with PWM period 10000

License: CERN-OHL-S 2.0
Engineer: Lukas F. Hartmann
https://mntre.com
Sheet: /Reform 2 Display/ MNT Research GmbH

File: reform2-display.sch
Id: 6/9 Title: MNT Reform 2 Internal Display

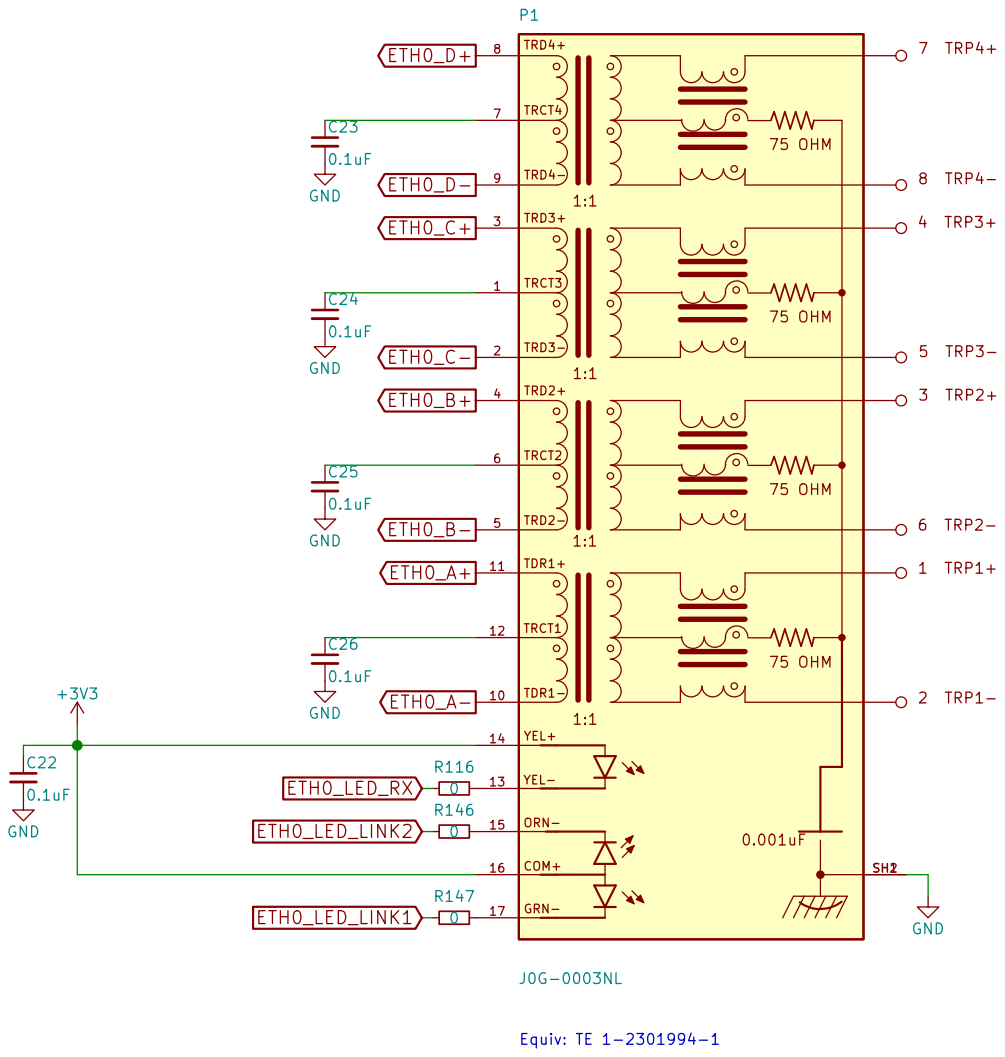
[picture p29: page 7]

8 TRP4- COM+ GRN- ORN- TDR1+ TDR1- TRCT1 TRCT2 TRCT3 TRCT4 TRD2+ TRD2- TRD3+ TRD3- TRD4+ TRD4- YEL+ YEL- 1

License: CERN-OHL-S 2.0
Engineer: Lukas F. Hartmann
https://mntre.com
Id: 7/9 Title: MNT Reform 2 Ethernet File: reform2-eth.sch Sheet: /Reform 2 Ethernet/ MNT Research GmbH

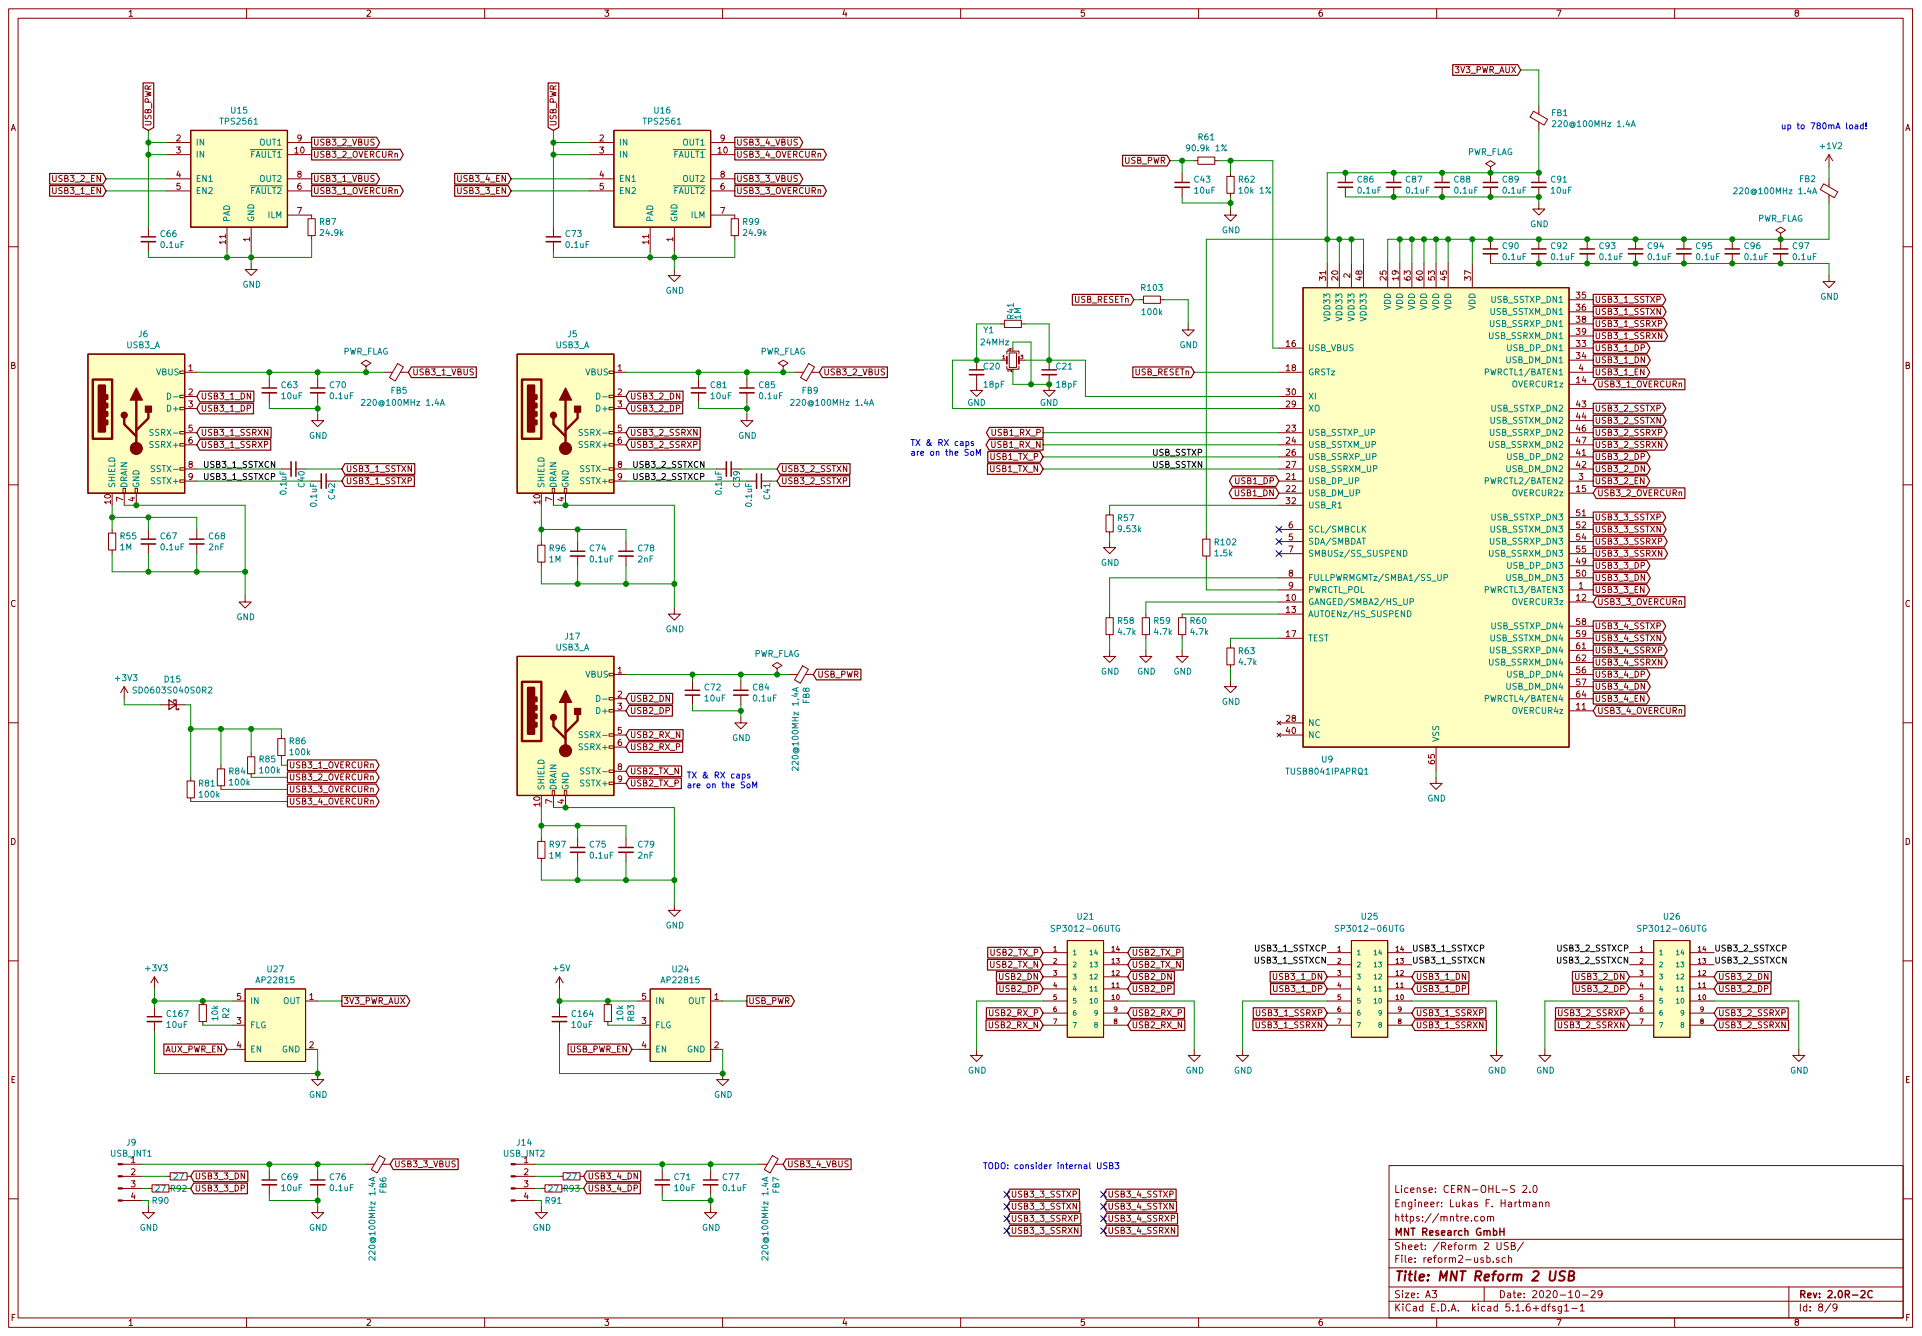
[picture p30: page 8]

2 VDD33 20 USB_DP_UP 21 USB_DM_UP 22 USB_SSTXP_UP 23 USB_SSTXM_UP 24 VDD 25 USB_SSRXP_UP 26 USB_SSRXM_UP 27 NC 28 XO 29 PWRCTL2/BATEN2 3 XI 30 VDD33 31 USB_R1 32 USB_DP_DN1 33 USB_DM_DN1 34 USB_SSTXP_DN1 35 USB_SSTXM_DN1 VDD 36 37 USB_SSRXP_DN1 38 USB_SSRXM_DN1 39 PWRCTL1/BATEN1 4 NC 40 USB_DP_DN2 41 USB_DM_DN2 42 USB_SSTXP_DN2 43 USB_SSTXM_DN2 44 VDD 45 USB_SSRXP_DN2 46 USB_SSRXM_DN2 47 VDD33 48 USB_DP_DN3 49 SDA/SMBDAT 5 USB_DM_DN3 50 USB_SSTXP_DN3 51 USB_SSTXM_DN3 52 VDD 53 USB_SSRXP_DN3 54 USB_SSRXM_DN3 55 USB_DP_DN4 56 USB_DM_DN4 57 USB_SSTXP_DN4 58 USB_SSTXM_DN4 59 SCL/SMBCLK 6 VDD 60 USB_SSRXP_DN4 61 USB_SSRXM_DN4 62 VDD 63 PWRCTL4/BATEN4 64 VSS 65 SMBUSz/SS_SUSPEND 7 FULLPWRMGMTz/SMBA1/SS_UP 8 PWRCTL_POL 9 U9 TUSB8041IPAPRQ1 OUT 1 GND 2 FLG 3 EN 4
GND

TX & RX caps are on the SoM

License: CERN-OHL-S 2.0
Engineer: Lukas F. Hartmann
https://mntre.com
File: reform2-usb.sch Sheet: /Reform 2 USB/ MNT Research GmbH

Id: 8/9 Title: MNT Reform 2 USB

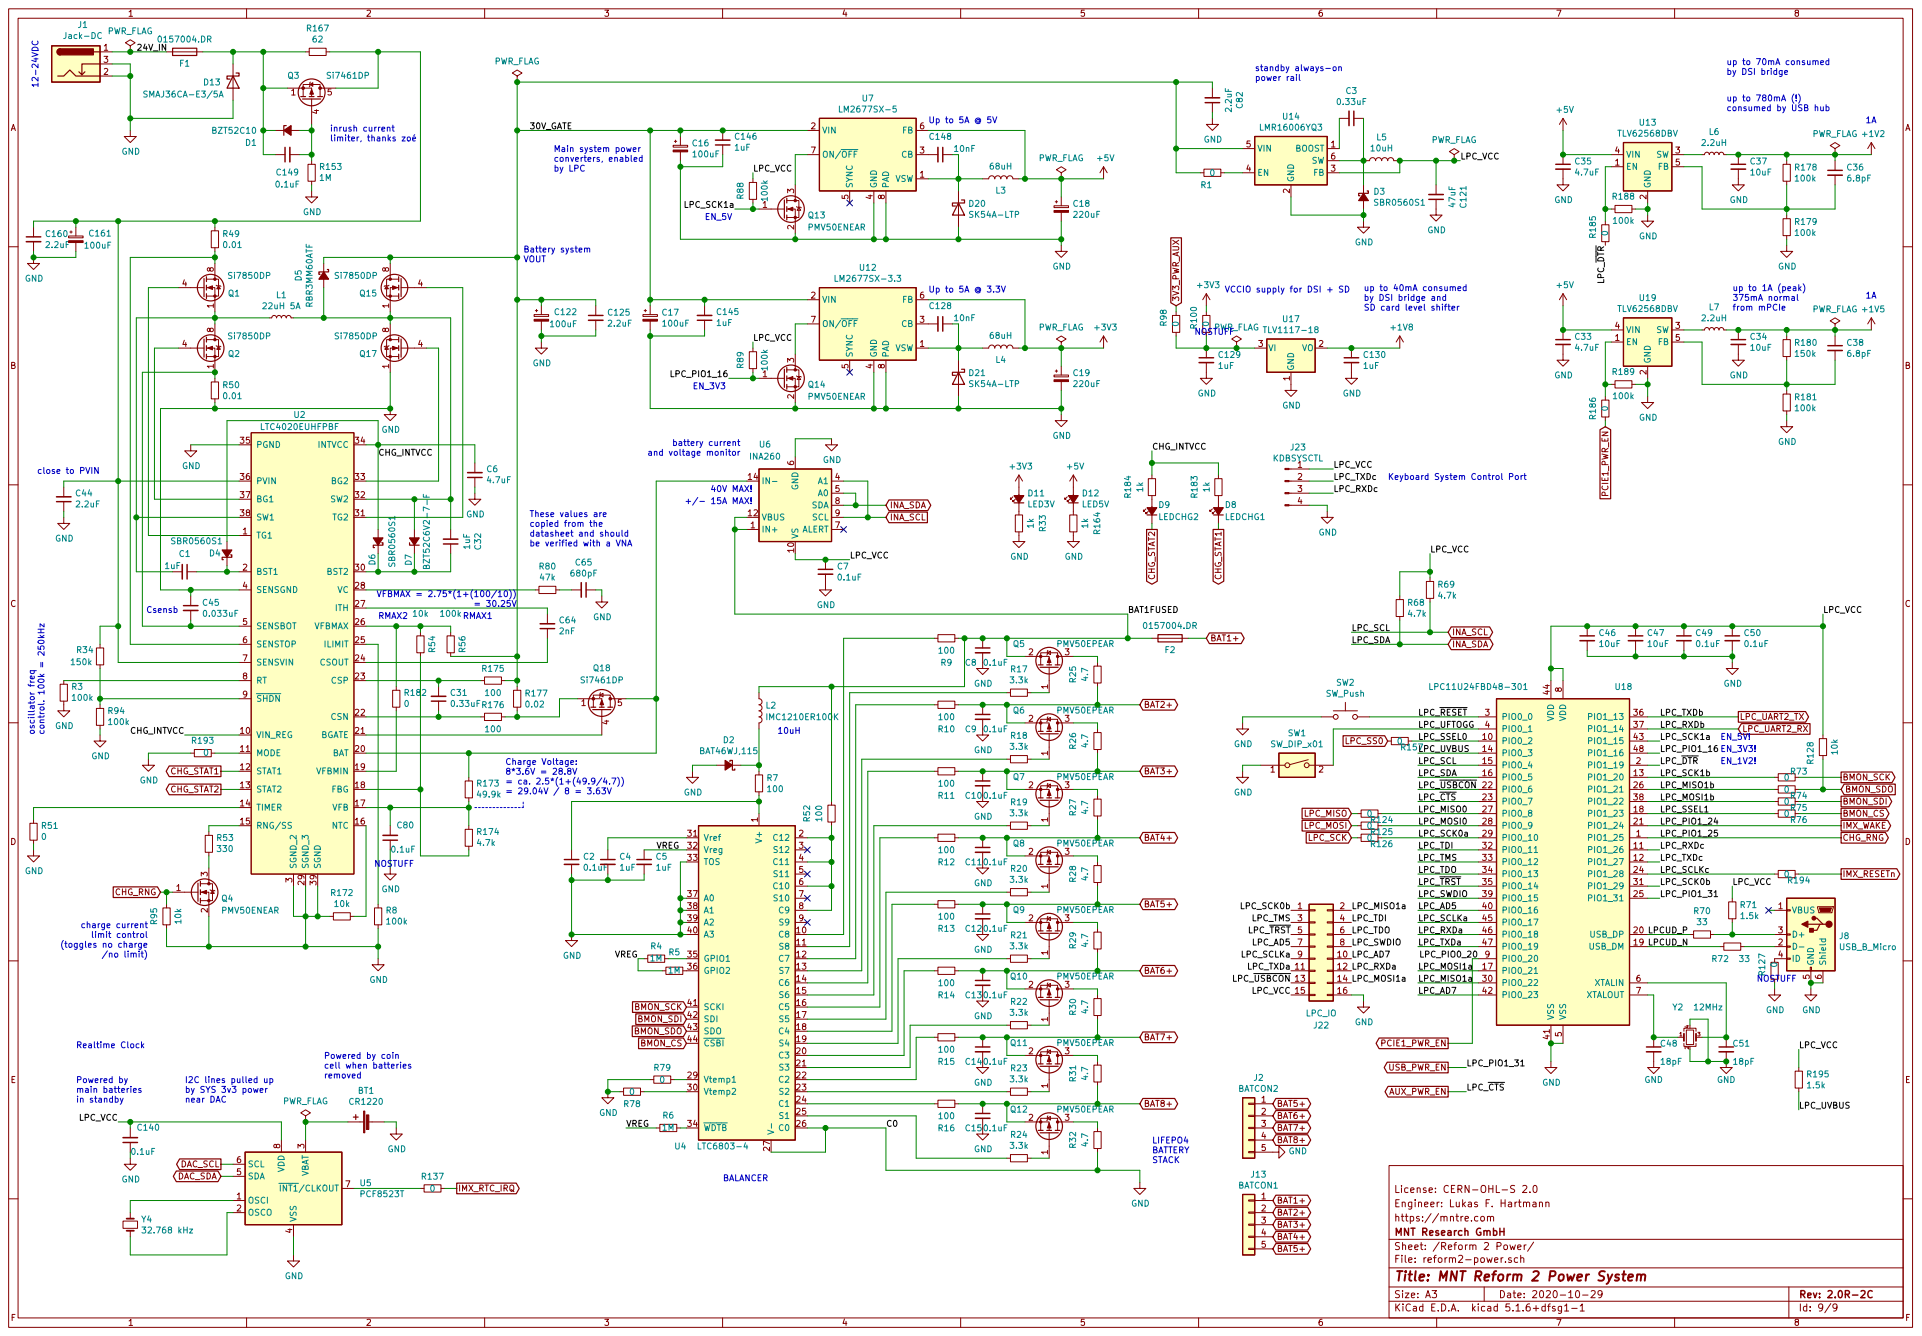
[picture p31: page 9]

consumed by USB hub

2 FB 3 EN 4 VIN 5 SW 6 U14

5 FB 6 ON/OFF 7 PAD

Main system power converters, enabled
PCIE1_PWR_EN 3V3_PWR_AUX

40V MAX! +/- 15A MAX! Battery system

VCCIO supply for DSI + SD

up to 1A (peak) 375mA normal

Keyboard System Control Port

These values are
copied from the
datasheet and should
be verified with a VNA

charge current
limit control (toggles no charge

Powered by main batteries

I2C lines pulled up
by SYS 3v3 power near DAC

Engineer: Lukas F. Hartmann
https://mntre.com
File: reform2-power.sch Sheet: /Reform 2 Power/ MNT Research GmbH

Id: 9/9 Title: MNT Reform 2 Power System

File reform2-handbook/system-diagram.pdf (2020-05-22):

# MNT Reform 2.0D-4 System Diagram

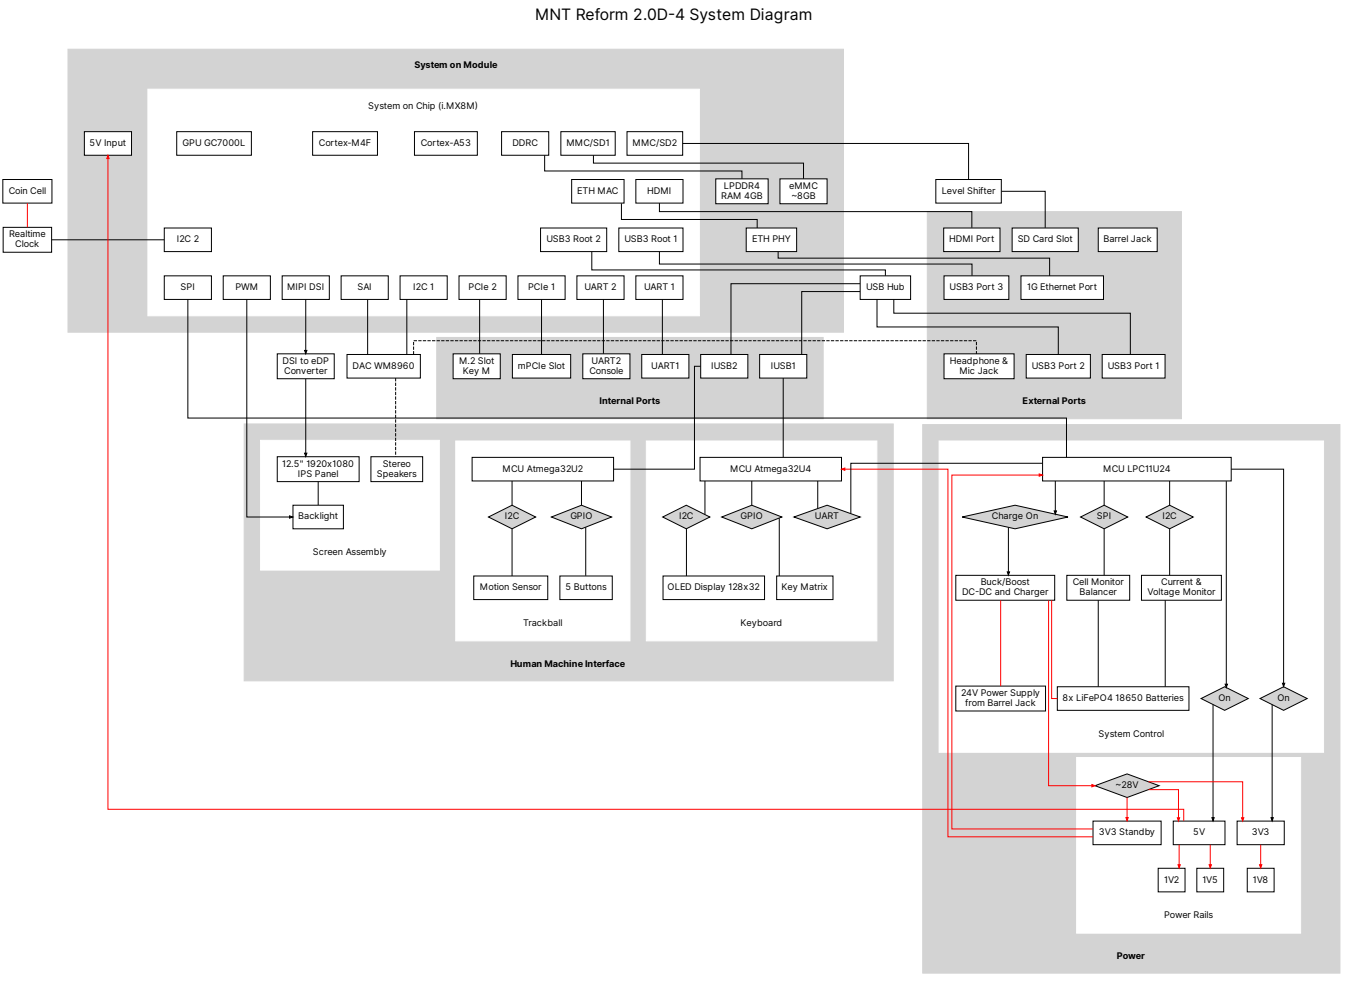
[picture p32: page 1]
Internal Ports; Power; System Control; Power Rails; External Ports; Screen Assembly; Trackball; Keyboard; Realtime Clock; Coin Cell; MIPI DSI; HDMI; HDMI Port; SAI; DAC WM8960; USB3 Root 1; USB3 Port 3; USB3 Root 2; USB Hub; DDRC; LPDDR4 RAM 4GB; MMC/SD1; eMMC ~8GB; MMC/SD2; Level Shifter; UART 2; UART2 Console; PCIe 1; mPCIe Slot; PCIe 2; M.2 Slot Key M; UART 1; UART1; PWM; Backlight; ETH MAC; ETH PHY; GPU GC7000L; Cortex-M4F; Cortex-A53; SPI; MCU LPC11U24; 1G Ethernet Port; 5V Input; IUSB2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

System on Module

System on Chip (i.MX8M)

DSI to eDP
Converter

Buck/Boost
DC-DC and Charger

Human Machine Interface

24V Power Supply
from Barrel Jack

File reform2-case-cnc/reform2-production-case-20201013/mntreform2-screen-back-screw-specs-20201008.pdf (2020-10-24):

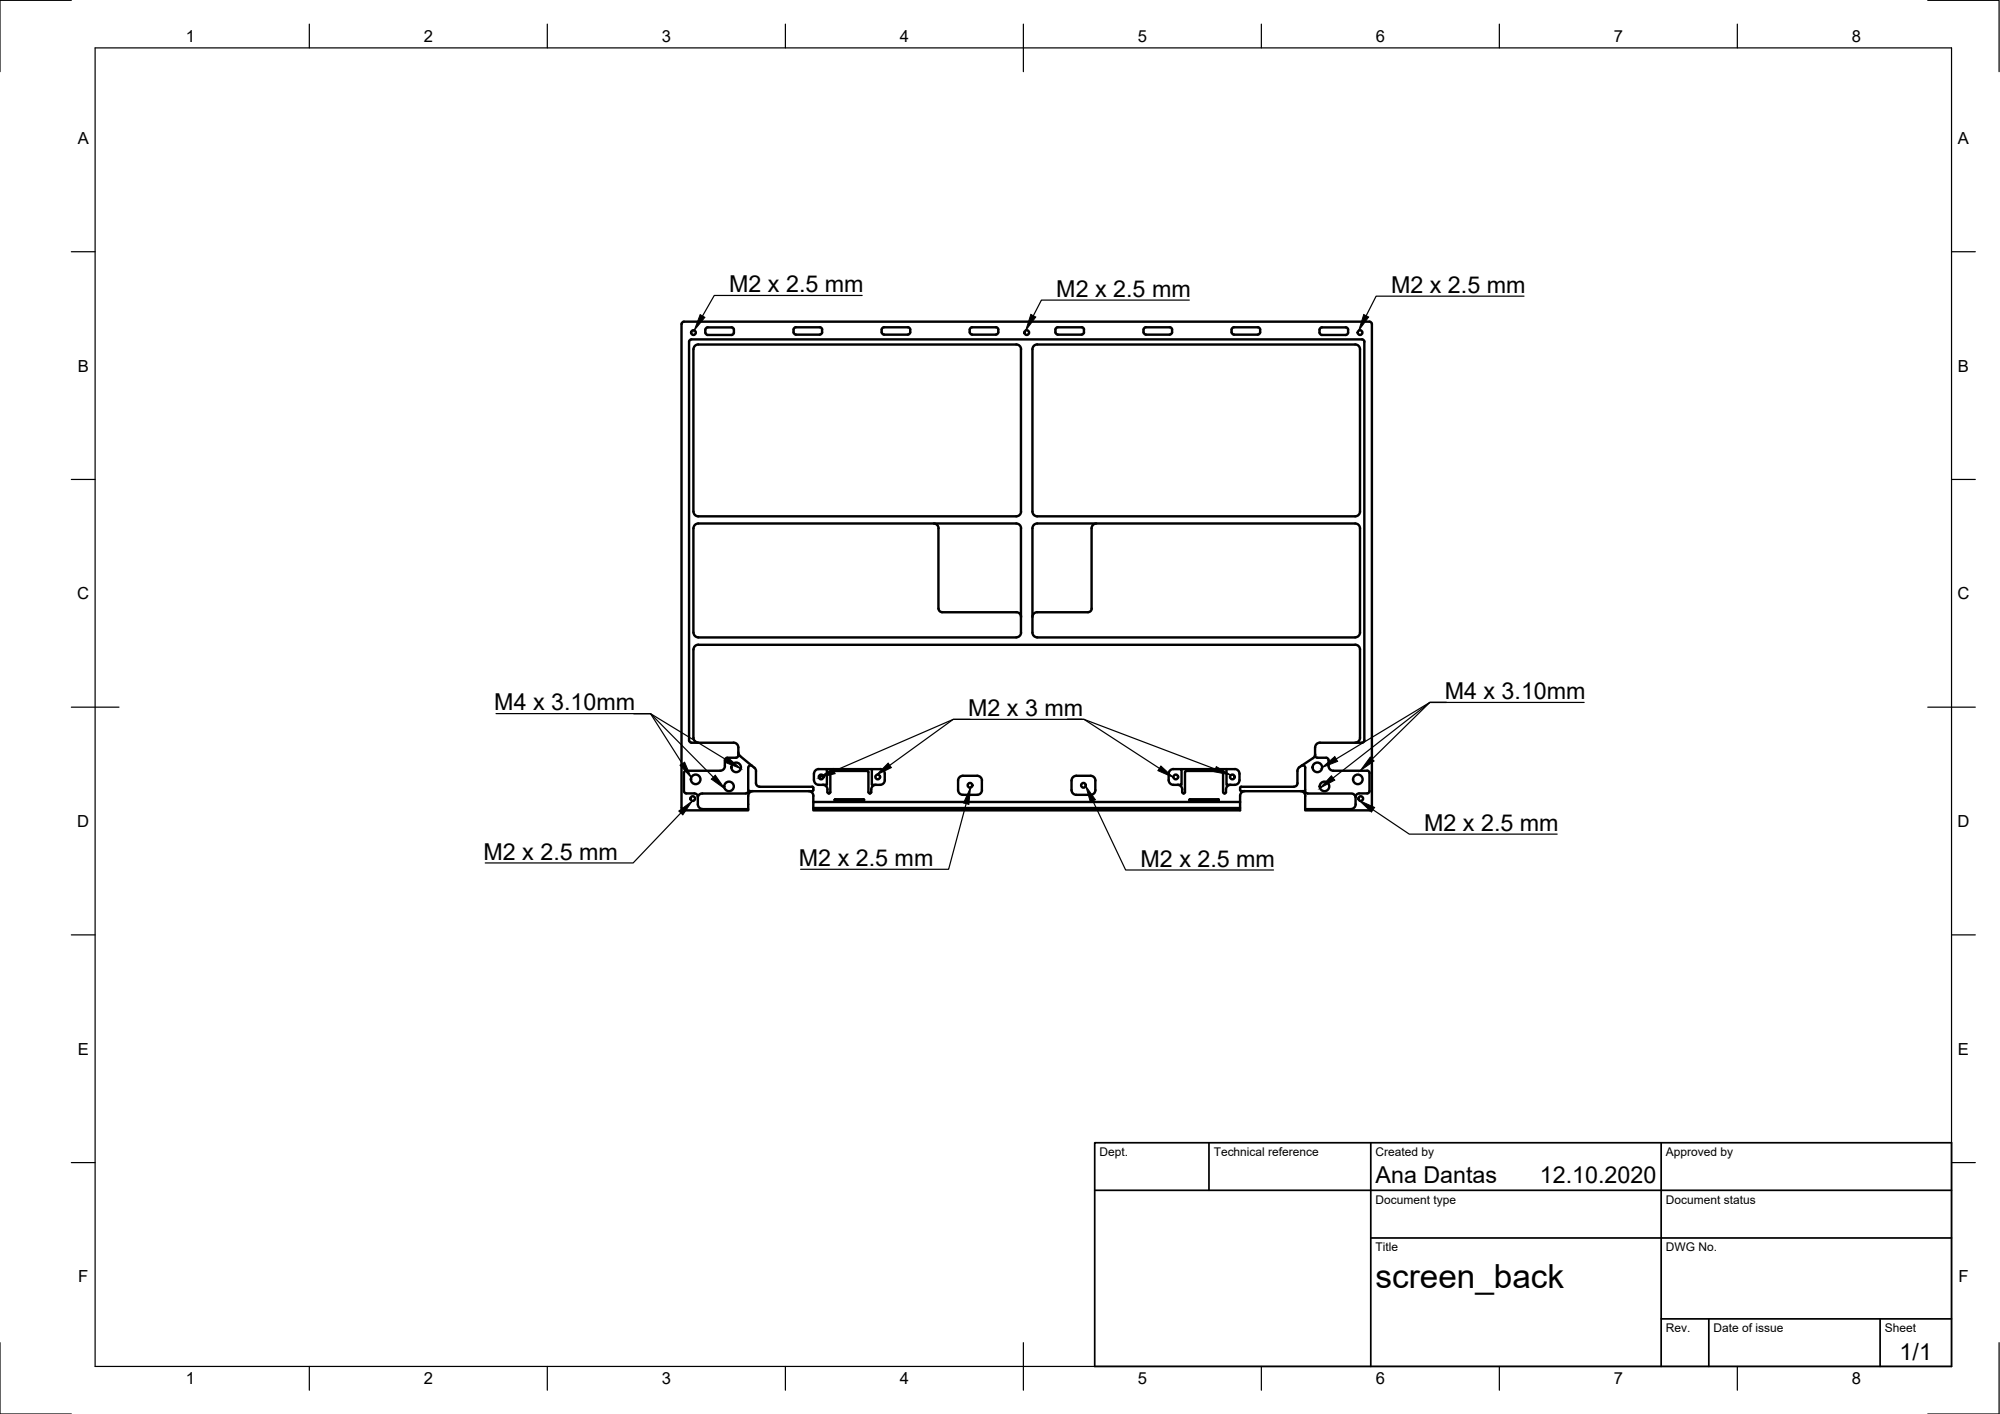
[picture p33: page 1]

Dept. | Technical reference | Created by Ana Dantas 12.10.2020 | Approved by

Document type | Document status

Title screen_back | DWG No.

Rev. | Date of issue | Sheet 1/1



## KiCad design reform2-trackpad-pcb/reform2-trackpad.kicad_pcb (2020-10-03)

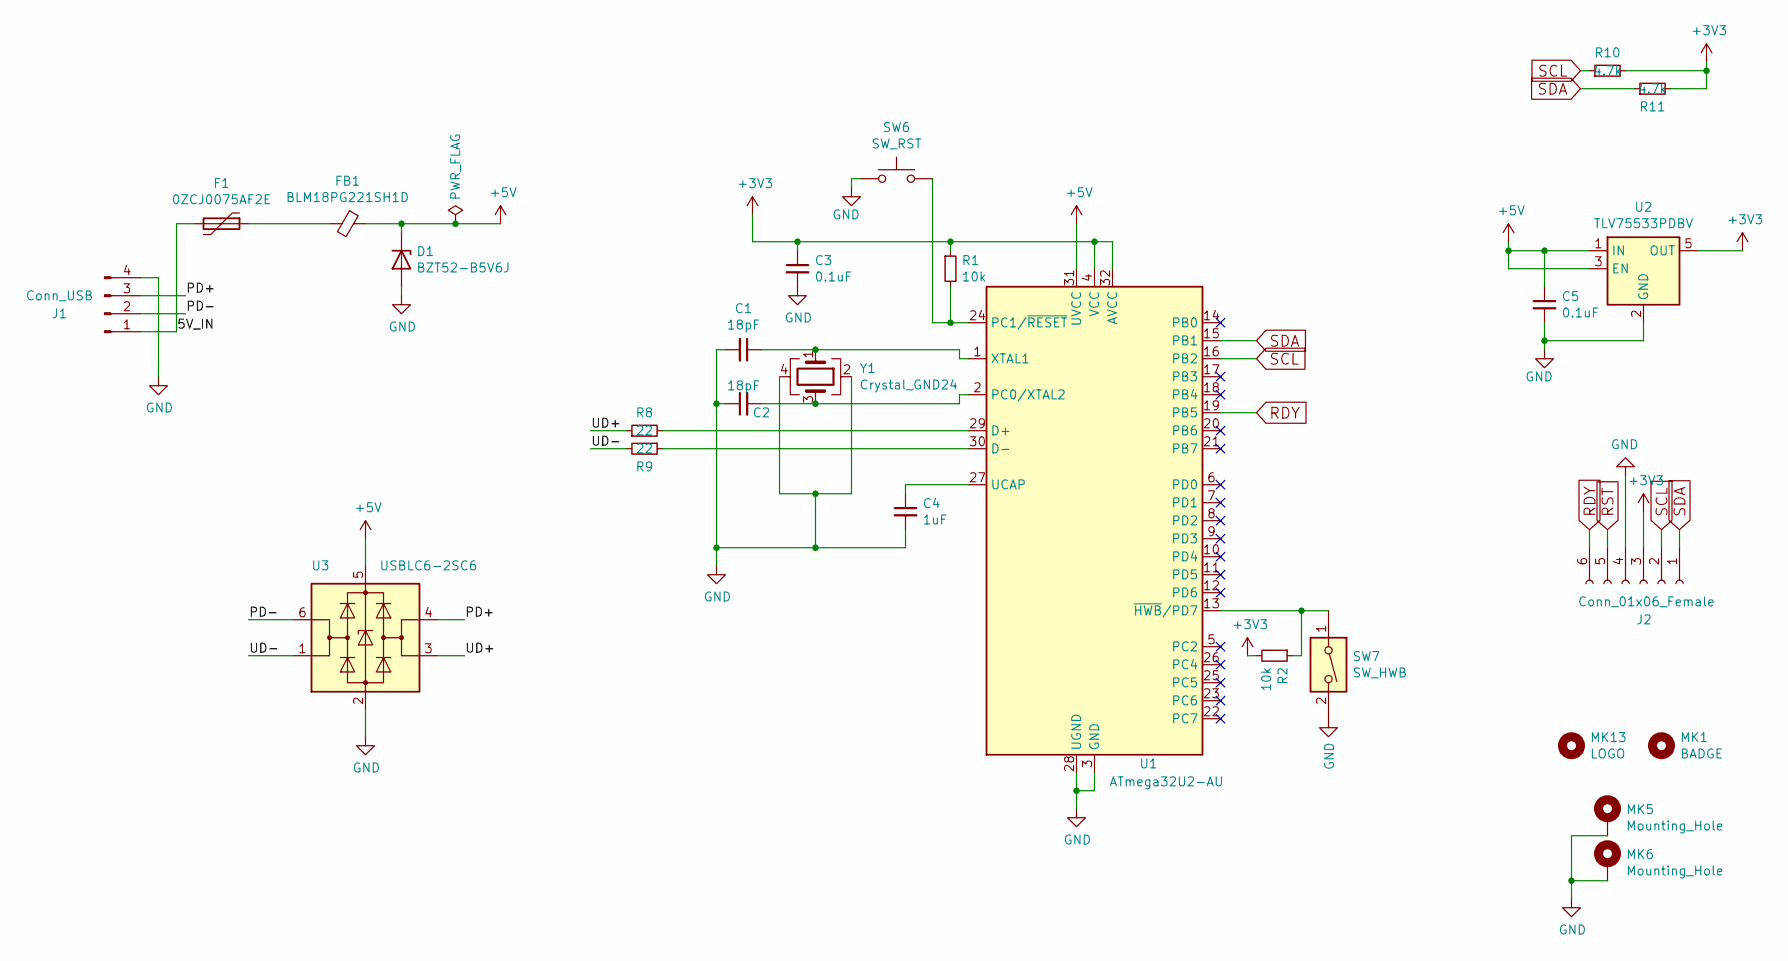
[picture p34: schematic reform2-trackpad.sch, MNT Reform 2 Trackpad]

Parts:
C1, C2: 18pF; C_0603_1608Metric
C3, C5: 0.1uF; C_0603_1608Metric
C4: 1uF; C_0603_1608Metric
D1: BZT52-B5V6J; D_SOD-123
F1: 0ZCJ0075AF2E; Fuse_1206_3216Metric_Castellated
FB1: BLM18PG221SH1D; L_0603_1608Metric
J1: Conn_USB; JST_PH_B4B-PH-K_1x04_P2.00mm_Vertical
J2: Conn_01x06_Female; Hirose_FH12-6S-0.5SH_1x06-1MP_P0.50mm_Horizontal
MK1: BADGE; reform2-trackpadctrl-badge
MK5, MK6: Mounting_Hole; MountingHole_2.2mm_M2_Pad
MK13: LOGO; mnt-minilogo
R1, R2: 10k; R_0603_1608Metric
R8, R9: 22; R_0603_1608Metric
R10, R11: 4.7k; R_0603_1608Metric
SW6: SW_RST; SW_Push_1P1T_NO_CK_KMR2
SW7: SW_HWB; SW_DIP_SPSTx01_Slide_Omron_A6S-110x_W8.9mm_P2.54mm
U1: ATmega32U2-AU; TQFP-32_7x7mm_P0.8mm
U2: TLV75533PDBV; SOT-23-5
U3: USBLC6-2SC6; SOT-23-6
Y1: Crystal_GND24; Crystal_SMD_3225-4Pin_3.2x2.5mm

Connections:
+3V3: C3.1, J2.3, R1.1, R2.2, R10.2, R11.2, U1.4 (VCC), U1.32 (AVCC), U2.5 (OUT)
+5V: C5.1, D1.1 (K), FB1.1, U1.31 (UVCC), U2.1 (IN), U2.3 (EN), U3.5 (VBUS)
/5V_IN: F1.2, J1.1
/PD+: J1.3, U3.4 (I/O2)
/PD-: J1.2, U3.6 (I/O1)
/UD+: R8.1, U3.3 (I/O2)
/UD-: R9.2, U3.1 (I/O1)
GND: C1.2, C2.1, C3.2, C4.2, C5.2, D1.2 (A), J1.4, J2.4, MK5.1, MK6.1, SW6.1, SW7.2, U1.3 (GND), U1.28 (UGND), U2.2 (GND), U3.2 (GND), Y1.2, Y1.4
unnamed: C1.1, U1.1 (XTAL1), Y1.1
unnamed: C2.2, U1.2 (PC0/XTAL2), Y1.3
unnamed: C4.1, U1.27 (UCAP)
unnamed: F1.1, FB1.2
unnamed: R1.2, SW6.2, U1.24 (PC1/~RESET)
unnamed: R2.1, SW7.1, U1.13 (~HWB~/PD7)
unnamed: R8.2, U1.29 (D+)
unnamed: R9.1, U1.30 (D-)
RDY: J2.6, U1.19 (PB5)
RST: J2.5
SCL: J2.2, R10.1, U1.16 (PB2)
SDA: J2.1, R11.1, U1.15 (PB1)

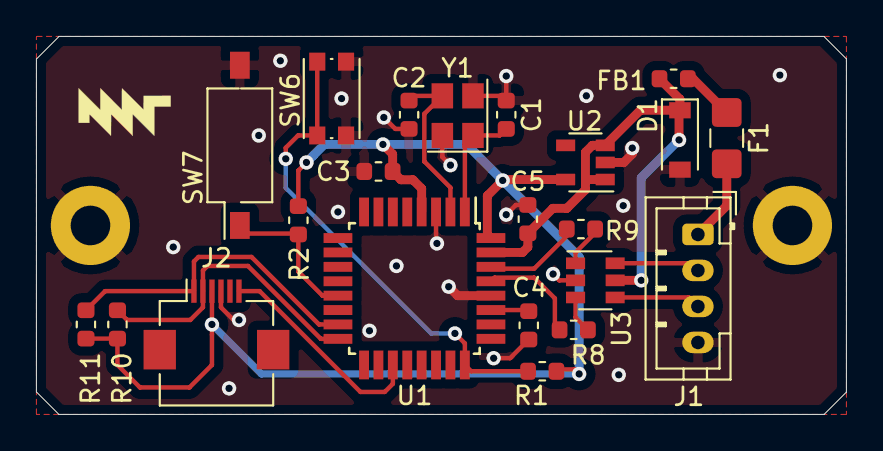
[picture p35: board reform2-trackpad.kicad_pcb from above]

Board: 2 copper layers, 45.0 x 21.0 mm, 26 parts (1 on the bottom side), 19 nets.

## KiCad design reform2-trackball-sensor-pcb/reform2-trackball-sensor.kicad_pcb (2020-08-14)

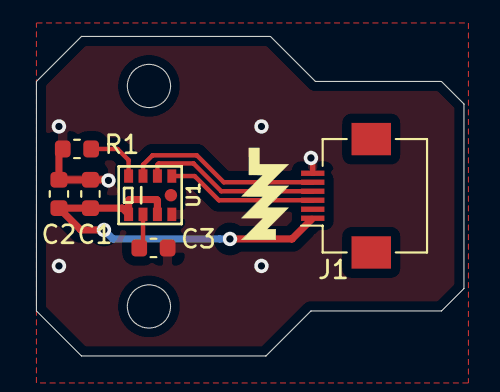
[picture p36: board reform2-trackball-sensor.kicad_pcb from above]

Board: 2 copper layers, 23.8 x 17.8 mm, 10 parts (1 on the bottom side), 7 nets.

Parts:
C1: 1uF; C_0603_1608Metric
C2: 0.1uF; C_0603_1608Metric
C3: 10uF; C_0603_1608Metric
H2, H5: MountingHole; MountingHole_2.2mm_M2
H7, H8: LOGO; mnt-minilogo
J1: Conn_01x06_Male; Hirose_FH12-6S-0.5SH_1x06-1MP_P0.50mm_Horizontal
R1: 0; R_0603_1608Metric
U1: PAT9125EL

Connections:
+3V3: C1.1, C2.1, J1.1, U1.1, U1.3
/MOTION: J1.5, U1.7
/SCL: J1.3, U1.5
/SDA: J1.4, U1.6
GND: C1.2, C2.2, C3.2, J1.6, R1.1, U1.4
unnamed: C3.1, U1.2
unnamed: R1.2, U1.8

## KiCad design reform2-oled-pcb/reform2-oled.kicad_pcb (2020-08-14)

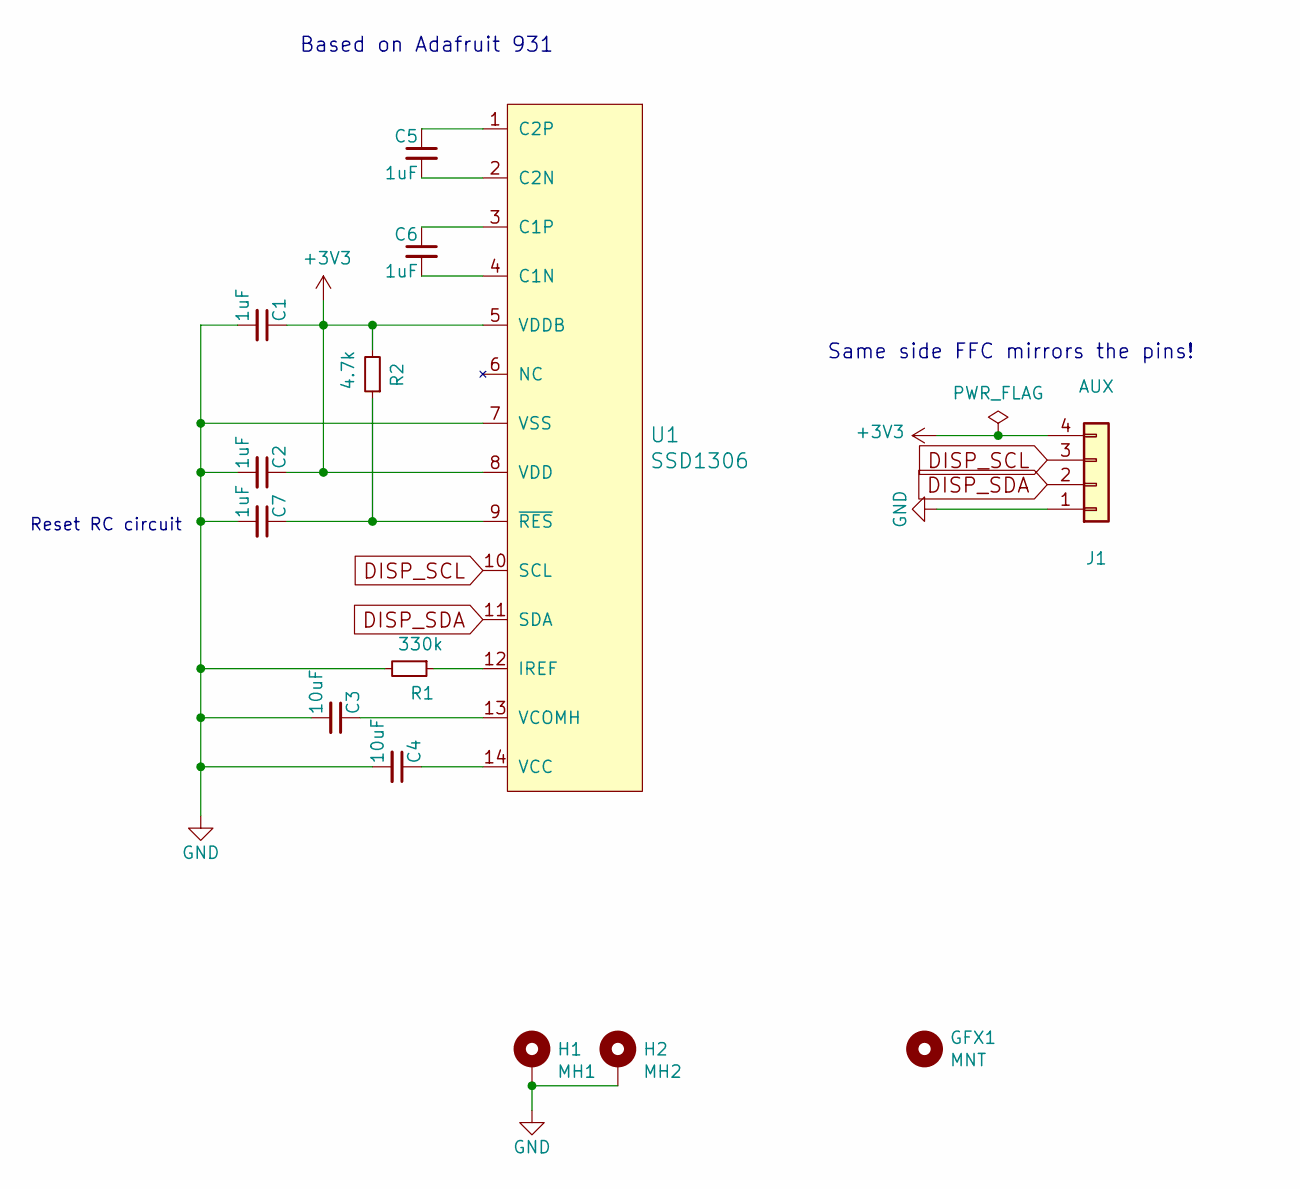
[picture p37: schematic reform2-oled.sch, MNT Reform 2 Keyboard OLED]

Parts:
C1, C2, C5, C6, C7: 1uF; C_0603_1608Metric_Pad1.05x0.95mm_HandSolder
C3, C4: 10uF; C_0603_1608Metric_Pad1.05x0.95mm_HandSolder
GFX1: MNT; mntreform
H1: MH1; MountingHole_2.2mm_M2_Pad
H2: MH2; MountingHole_2.2mm_M2_Pad
J1: AUX; Molex_200528-0040_1x04-1MP_P1.00mm_Horizontal
R1: 330k; R_0603_1608Metric_Pad1.05x0.95mm_HandSolder
R2: 4.7k; R_0603_1608Metric_Pad1.05x0.95mm_HandSolder
U1: SSD1306; SSD1306_OLED-0.91-128x32

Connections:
+3V3: C1.1, C2.1, J1.4, R2.2, U1.5 (VDDB), U1.8 (VDD)
DISP_SCL: J1.3, U1.10 (SCL)
DISP_SDA: J1.2, U1.11 (SDA)
GND: C1.2, C2.2, C3.2, C4.2, C7.2, H1.1, H2.1, J1.1, R1.2, U1.7 (VSS)
unnamed: C3.1, U1.13 (VCOMH)
unnamed: C4.1, U1.14 (VCC)
unnamed: C5.1, U1.1 (C2P)
unnamed: C5.2, U1.2 (C2N)
unnamed: C6.1, U1.3 (C1P)
unnamed: C6.2, U1.4 (C1N)
unnamed: C7.1, R2.1, U1.9 (~RES)
unnamed: R1.1, U1.12 (IREF)

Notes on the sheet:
Based on Adafruit 931
Reset RC circuit
Same side FFC mirrors the pins!

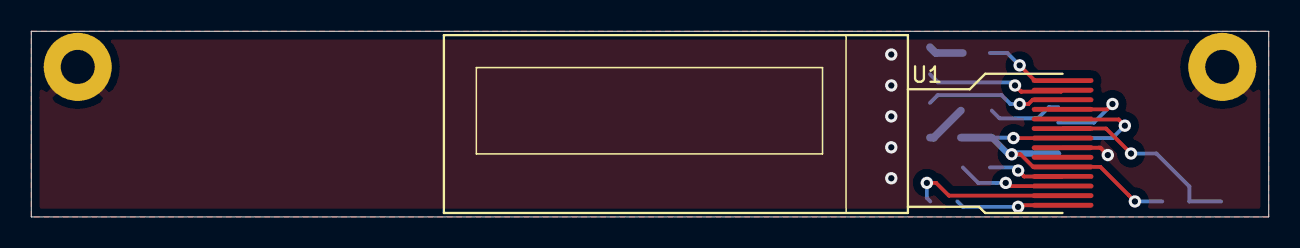
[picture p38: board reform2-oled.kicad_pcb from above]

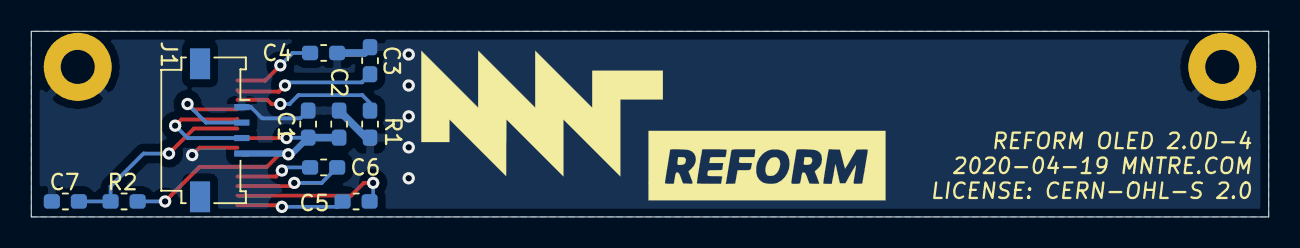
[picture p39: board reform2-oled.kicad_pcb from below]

Board: 2 copper layers, 80.0 x 12.0 mm, 14 parts (11 on the bottom side), 12 nets.

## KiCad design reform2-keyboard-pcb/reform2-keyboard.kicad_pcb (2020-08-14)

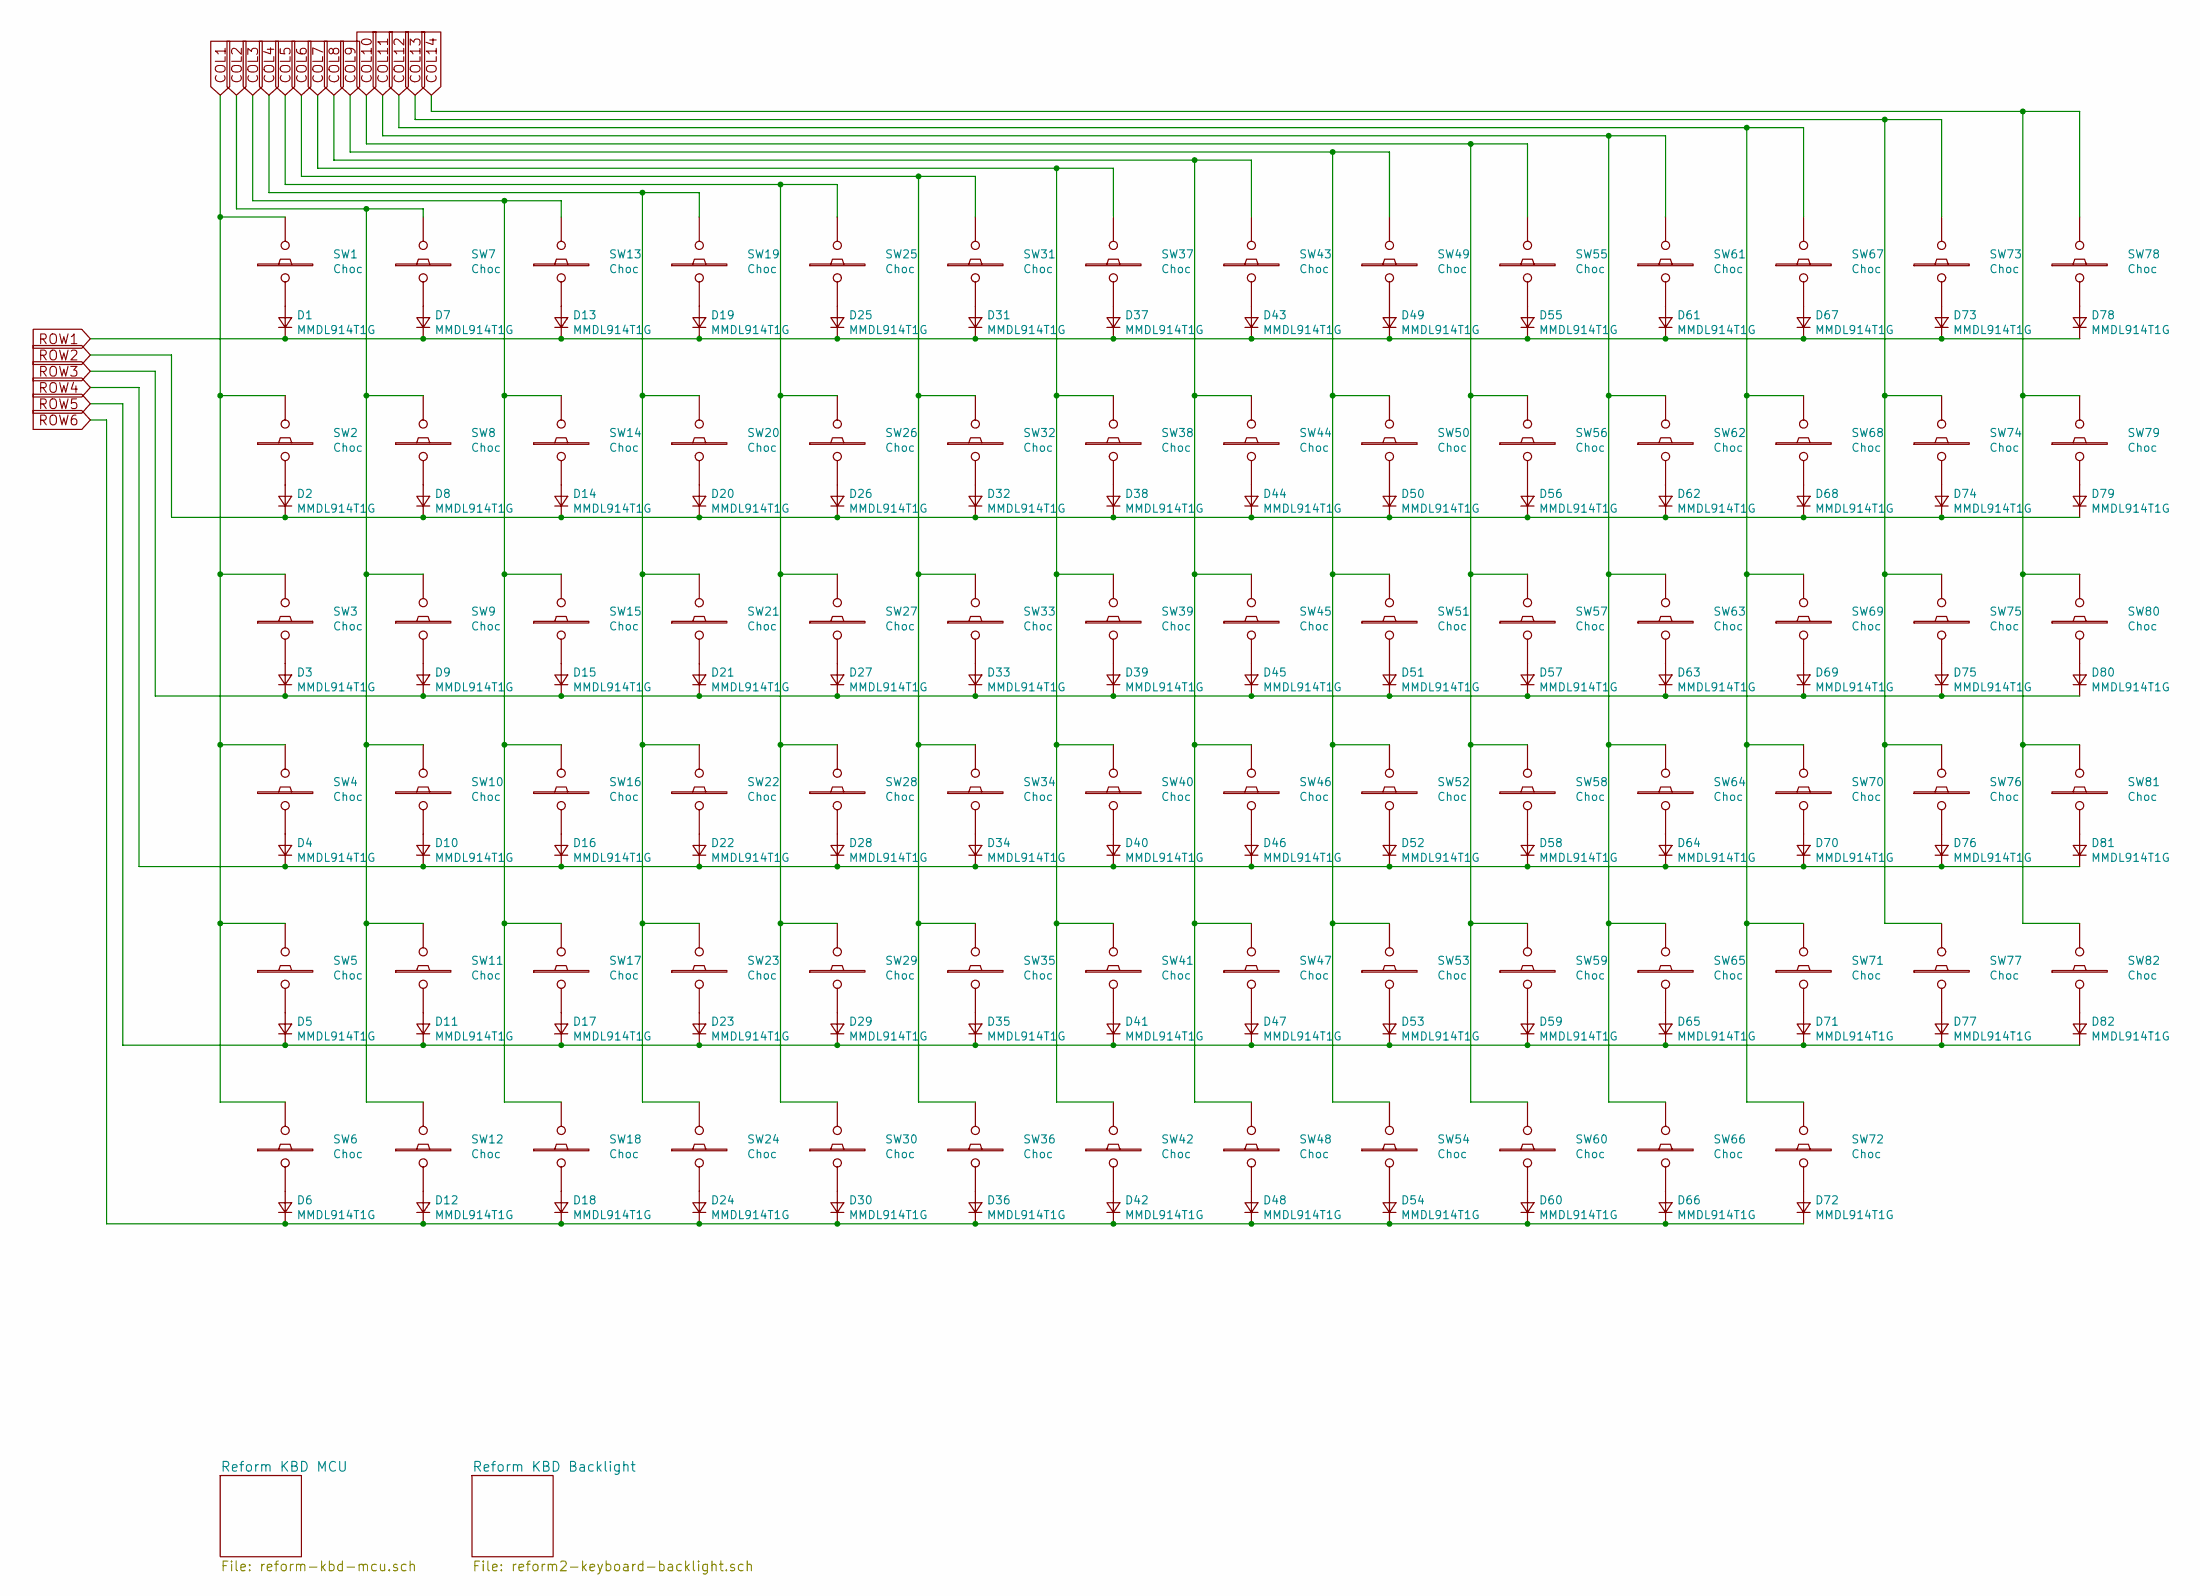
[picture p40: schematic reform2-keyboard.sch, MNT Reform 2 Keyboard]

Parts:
D1, D2, D3, D4, D5, D6, D7, D8, D9, D10, D11, D12, D13, D14, D15, D16, D17, D18, D19, D20, D21, D22, D23, D24, D25, D26, D27, D28, D29, D30, D31, D32, D33, D34, D35, D36, D37, D38, D39, D40, D41, D42, D43, D44, D45, D46, D47, D48, D49, D50, D51, D52, D53, D54, D55, D56, D57, D58, D59, D60, D61, D62, D63, D64, D65, D66, D67, D68, D69, D70, D71, D72, D73, D74, D75, D76, D77, D78, D79, D80, D81, D82: MMDL914T1G; D_0603_1608Metric_Pad1.05x0.95mm_HandSolder
SW1, SW2, SW3, SW4, SW5, SW6, SW7, SW8, SW9, SW10, SW11, SW12, SW13, SW14, SW15, SW16, SW17, SW18, SW19, SW20, SW21, SW22, SW23, SW24, SW25, SW26, SW27, SW28, SW29, SW30, SW31, SW32, SW33, SW34, SW35, SW36, SW37, SW38, SW39, SW40, SW41, SW42, SW43, SW44, SW45, SW46, SW47, SW48, SW49, SW50, SW51, SW52, SW53, SW54, SW55, SW56, SW57, SW58, SW59, SW60, SW61, SW62, SW63, SW64, SW65, SW66, SW67, SW68, SW69, SW70, SW71, SW72, SW73, SW74, SW75, SW76, SW77, SW78, SW79, SW80, SW81, SW82: Choc; PG1350

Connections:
COL1: SW1.1, SW2.1, SW3.1, SW4.1, SW5.1, SW6.1; also elsewhere on the board
COL2: SW7.1, SW8.1, SW9.1, SW10.1, SW11.1, SW12.1; also elsewhere on the board
COL3: SW13.1, SW14.1, SW15.1, SW16.1, SW17.1, SW18.1; also elsewhere on the board
COL4: SW19.1, SW20.1, SW21.1, SW22.1, SW23.1, SW24.1; also elsewhere on the board
COL5: SW25.1, SW26.1, SW27.1, SW28.1, SW29.1, SW30.1; also elsewhere on the board
COL6: SW31.1, SW32.1, SW33.1, SW34.1, SW35.1, SW36.1; also elsewhere on the board
COL7: SW37.1, SW38.1, SW39.1, SW40.1, SW41.1, SW42.1; also elsewhere on the board
COL8: SW43.1, SW44.1, SW45.1, SW46.1, SW47.1, SW48.1; also elsewhere on the board
COL9: SW49.1, SW50.1, SW51.1, SW52.1, SW53.1, SW54.1; also elsewhere on the board
COL10: SW55.1, SW56.1, SW57.1, SW58.1, SW59.1, SW60.1; also elsewhere on the board
COL11: SW61.1, SW62.1, SW63.1, SW64.1, SW65.1, SW66.1; also elsewhere on the board
COL12: SW67.1, SW68.1, SW69.1, SW70.1, SW71.1, SW72.1; also elsewhere on the board
COL13: SW73.1, SW74.1, SW75.1, SW76.1, SW77.1; also elsewhere on the board
COL14: SW78.1, SW79.1, SW80.1, SW81.1, SW82.1; also elsewhere on the board
unnamed: D1.2 (A), SW1.2
unnamed: D2.2 (A), SW2.2
unnamed: D3.2 (A), SW3.2
unnamed: D4.2 (A), SW4.2
unnamed: D5.2 (A), SW5.2
unnamed: D6.2 (A), SW6.2
unnamed: D7.2 (A), SW7.2
unnamed: D8.2 (A), SW8.2
unnamed: D9.2 (A), SW9.2
unnamed: D10.2 (A), SW10.2
unnamed: D11.2 (A), SW11.2
unnamed: D12.2 (A), SW12.2
unnamed: D13.2 (A), SW13.2
unnamed: D14.2 (A), SW14.2
unnamed: D15.2 (A), SW15.2
unnamed: D16.2 (A), SW16.2
unnamed: D17.2 (A), SW17.2
unnamed: D18.2 (A), SW18.2
unnamed: D19.2 (A), SW19.2
unnamed: D20.2 (A), SW20.2
unnamed: D21.2 (A), SW21.2
unnamed: D22.2 (A), SW22.2
unnamed: D23.2 (A), SW23.2
unnamed: D24.2 (A), SW24.2
unnamed: D25.2 (A), SW25.2
unnamed: D26.2 (A), SW26.2
unnamed: D27.2 (A), SW27.2
unnamed: D28.2 (A), SW28.2
unnamed: D29.2 (A), SW29.2
unnamed: D30.2 (A), SW30.2
unnamed: D31.2 (A), SW31.2
unnamed: D32.2 (A), SW32.2
unnamed: D33.2 (A), SW33.2
unnamed: D34.2 (A), SW34.2
unnamed: D35.2 (A), SW35.2
unnamed: D36.2 (A), SW36.2
unnamed: D37.2 (A), SW37.2
unnamed: D38.2 (A), SW38.2
unnamed: D39.2 (A), SW39.2
unnamed: D40.2 (A), SW40.2
unnamed: D41.2 (A), SW41.2
unnamed: D42.2 (A), SW42.2
unnamed: D43.2 (A), SW43.2
unnamed: D44.2 (A), SW44.2
unnamed: D45.2 (A), SW45.2
unnamed: D46.2 (A), SW46.2
unnamed: D47.2 (A), SW47.2
unnamed: D48.2 (A), SW48.2
unnamed: D49.2 (A), SW49.2
unnamed: D50.2 (A), SW50.2
unnamed: D51.2 (A), SW51.2
unnamed: D52.2 (A), SW52.2
unnamed: D53.2 (A), SW53.2
unnamed: D54.2 (A), SW54.2
unnamed: D55.2 (A), SW55.2
unnamed: D56.2 (A), SW56.2
unnamed: D57.2 (A), SW57.2
unnamed: D58.2 (A), SW58.2
unnamed: D59.2 (A), SW59.2
unnamed: D60.2 (A), SW60.2
unnamed: D61.2 (A), SW61.2
unnamed: D62.2 (A), SW62.2
unnamed: D63.2 (A), SW63.2
unnamed: D64.2 (A), SW64.2
unnamed: D65.2 (A), SW65.2
unnamed: D66.2 (A), SW66.2
unnamed: D67.2 (A), SW67.2
unnamed: D68.2 (A), SW68.2
unnamed: D69.2 (A), SW69.2
unnamed: D70.2 (A), SW70.2
unnamed: D71.2 (A), SW71.2
unnamed: D72.2 (A), SW72.2
unnamed: D73.2 (A), SW73.2
unnamed: D74.2 (A), SW74.2
unnamed: D75.2 (A), SW75.2
unnamed: D76.2 (A), SW76.2
unnamed: D77.2 (A), SW77.2
unnamed: D78.2 (A), SW78.2
unnamed: D79.2 (A), SW79.2
unnamed: D80.2 (A), SW80.2
unnamed: D81.2 (A), SW81.2
unnamed: D82.2 (A), SW82.2
ROW1: D1.1 (K), D7.1 (K), D13.1 (K), D19.1 (K), D25.1 (K), D31.1 (K), D37.1 (K), D43.1 (K), D49.1 (K), D55.1 (K), D61.1 (K), D67.1 (K), D73.1 (K), D78.1 (K); also elsewhere on the board
ROW2: D2.1 (K), D8.1 (K), D14.1 (K), D20.1 (K), D26.1 (K), D32.1 (K), D38.1 (K), D44.1 (K), D50.1 (K), D56.1 (K), D62.1 (K), D68.1 (K), D74.1 (K), D79.1 (K); also elsewhere on the board
ROW3: D3.1 (K), D9.1 (K), D15.1 (K), D21.1 (K), D27.1 (K), D33.1 (K), D39.1 (K), D45.1 (K), D51.1 (K), D57.1 (K), D63.1 (K), D69.1 (K), D75.1 (K), D80.1 (K); also elsewhere on the board
ROW4: D4.1 (K), D10.1 (K), D16.1 (K), D22.1 (K), D28.1 (K), D34.1 (K), D40.1 (K), D46.1 (K), D52.1 (K), D58.1 (K), D64.1 (K), D70.1 (K), D76.1 (K), D81.1 (K); also elsewhere on the board
ROW5: D5.1 (K), D11.1 (K), D17.1 (K), D23.1 (K), D29.1 (K), D35.1 (K), D41.1 (K), D47.1 (K), D53.1 (K), D59.1 (K), D65.1 (K), D71.1 (K), D77.1 (K), D82.1 (K); also elsewhere on the board
ROW6: D6.1 (K), D12.1 (K), D18.1 (K), D24.1 (K), D30.1 (K), D36.1 (K), D42.1 (K), D48.1 (K), D54.1 (K), D60.1 (K), D66.1 (K), D72.1 (K); also elsewhere on the board

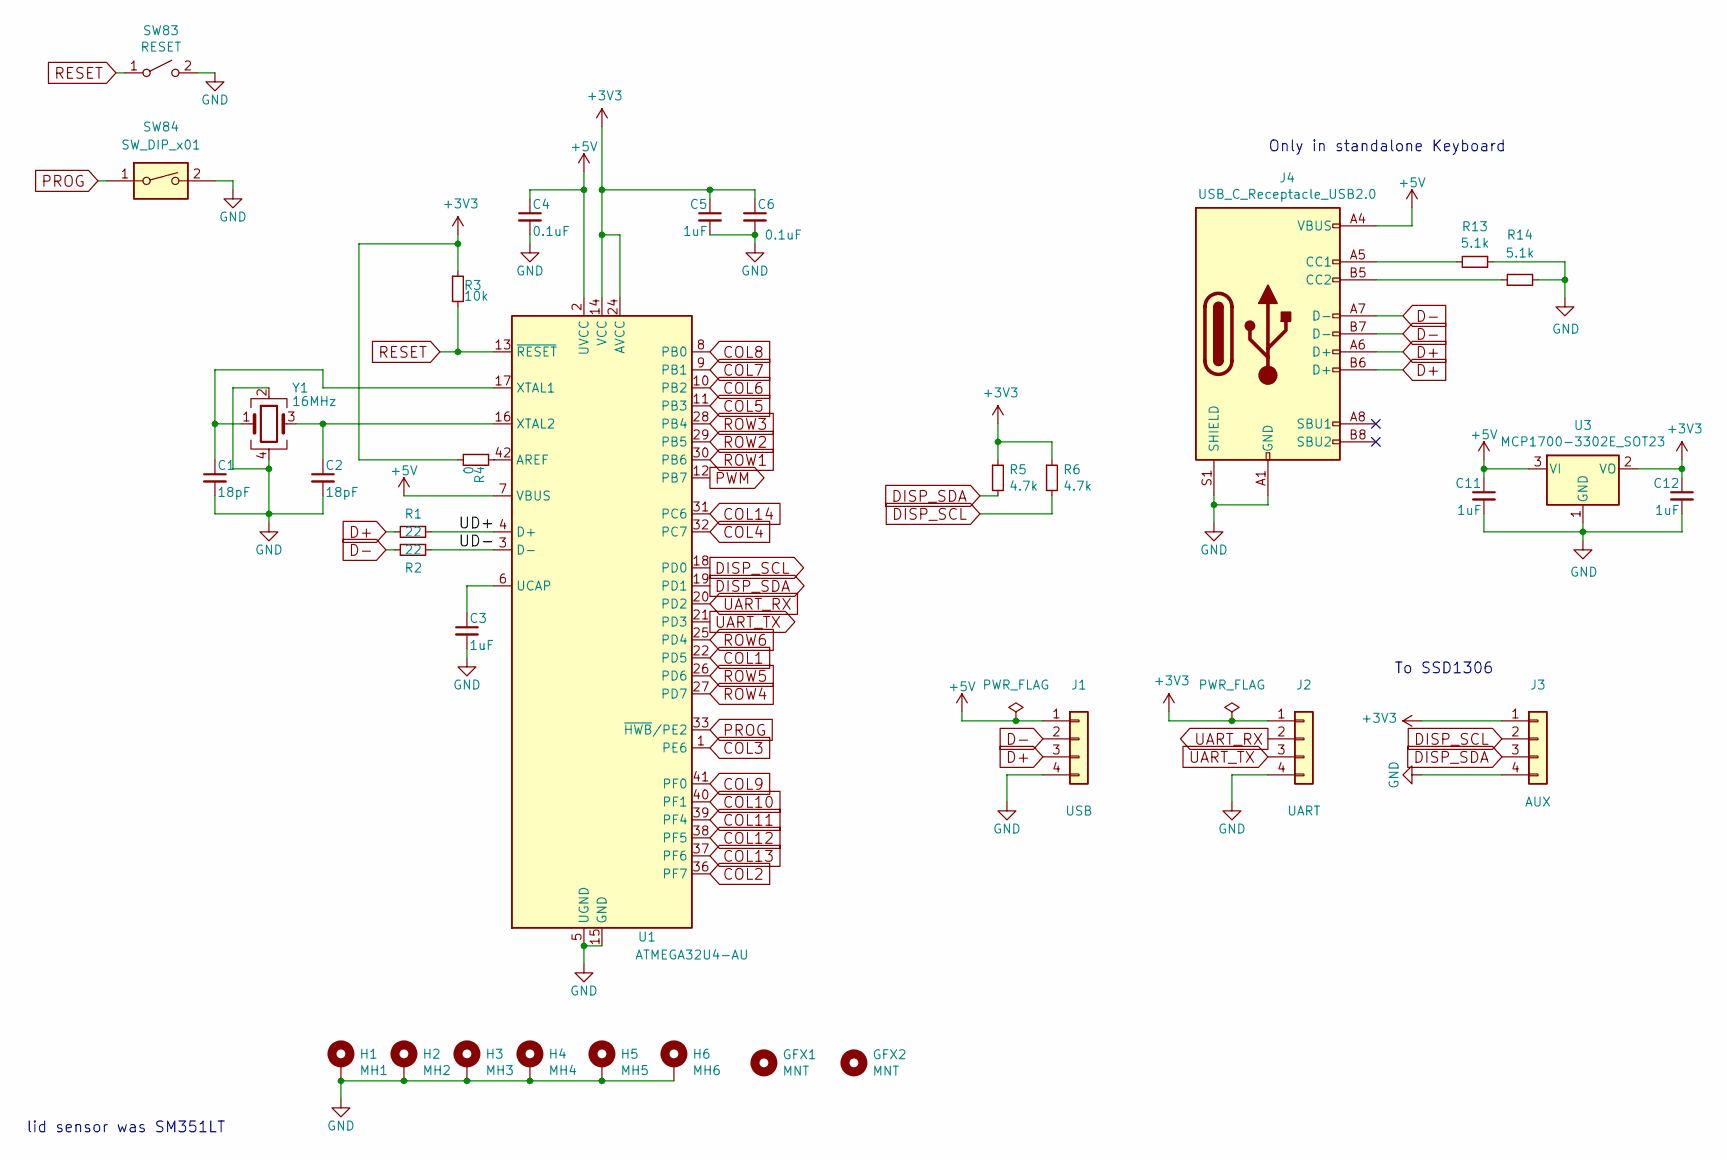
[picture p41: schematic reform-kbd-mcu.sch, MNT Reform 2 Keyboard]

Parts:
C1, C2: 18pF; C_0603_1608Metric
C3, C5, C11, C12: 1uF; C_0603_1608Metric
C4, C6: 0.1uF; C_0603_1608Metric
GFX1, GFX2: MNT; mntreform
H1: MH1; MountingHole_2.2mm_M2_Pad
H2: MH2; MountingHole_2.2mm_M2_Pad
H3: MH3; MountingHole_2.2mm_M2_Pad
H4: MH4; MountingHole_2.2mm_M2_Pad
H5: MH5; MountingHole_2.2mm_M2_Pad
H6: MH6; MountingHole_2.2mm_M2_Pad
J1: USB; JST_PH_S4B-PH-SM4-TB_1x04-1MP_P2.00mm_Horizontal
J2: UART; JST_PH_S4B-PH-SM4-TB_1x04-1MP_P2.00mm_Horizontal
J3: AUX; Molex_200528-0040_1x04-1MP_P1.00mm_Horizontal
J4: USB_C_Receptacle_USB2.0; USB_C_Receptacle_Amphenol_12401610E4-2A
R1, R2: 22; R_0603_1608Metric
R3: 10k; R_0603_1608Metric
R4: 0; R_0603_1608Metric
R5, R6: 4.7k; R_0603_1608Metric
R13, R14: 5.1k; R_0603_1608Metric
SW83: RESET; SW_Push_1P1T_NO_CK_KMR2
SW84: SW_DIP_x01; SW_DIP_SPSTx01_Slide_Omron_A6S-110x_W8.9mm_P2.54mm
U1: ATMEGA32U4-AU; TQFP-44_10x10mm_Pitch0.8mm
U3: MCP1700-3302E_SOT23; SOT-23
Y1: 16MHz; Crystal_SMD_3225-4Pin_3.2x2.5mm

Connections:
+3V3: C5.1, C6.1, C12.1, J2.1, J3.1, R3.1, R4.2, R5.1, R6.1, U1.14 (VCC), U1.24 (AVCC), U1.34 (VCC), U1.44 (AVCC), U3.2 (VO)
+5V: C4.1, C11.1, J1.1, J4.A4 (VBUS), J4.A9 (VBUS), J4.B4 (VBUS), J4.B9 (VBUS), U1.2 (UVCC), U1.7 (VBUS), U3.3 (VI); also elsewhere on the board
/Reform KBD MCU/UD+: R1.1, U1.4 (D+)
/Reform KBD MCU/UD-: R2.1, U1.3 (D-)
COL1: U1.22 (PD5); also elsewhere on the board
COL2: U1.36 (PF7); also elsewhere on the board
COL3: U1.1 (PE6); also elsewhere on the board
COL4: U1.32 (PC7); also elsewhere on the board
COL5: U1.11 (PB3); also elsewhere on the board
COL6: U1.10 (PB2); also elsewhere on the board
COL7: U1.9 (PB1); also elsewhere on the board
COL8: U1.8 (PB0); also elsewhere on the board
COL9: U1.41 (PF0); also elsewhere on the board
COL10: U1.40 (PF1); also elsewhere on the board
COL11: U1.39 (PF4); also elsewhere on the board
COL12: U1.38 (PF5); also elsewhere on the board
COL13: U1.37 (PF6); also elsewhere on the board
COL14: U1.31 (PC6); also elsewhere on the board
D+: J1.3, J4.A6 (D+), J4.B6 (D+), R1.2
D-: J1.2, J4.A7 (D-), J4.B7 (D-), R2.2
DISP_SCL: J3.2, R6.2, U1.18 (PD0)
DISP_SDA: J3.3, R5.2, U1.19 (PD1)
GND: C1.2, C2.2, C3.2, C4.2, C5.2, C6.2, C11.2, C12.2, H1.1, H2.1, H3.1, H4.1, H5.1, H6.1, J1.4, J2.4, J3.4, J4.A1 (GND), J4.A12 (GND), J4.B1 (GND), J4.B12 (GND), J4.S1 (SHIELD), R13.1, R14.2, SW83.2 (B), SW84.2, U1.5 (UGND), U1.15 (GND), U1.23 (GND), U1.35 (GND), U1.43 (GND), U3.1 (GND), Y1.2, Y1.4; also elsewhere on the board
unnamed: C1.1, U1.17 (XTAL1), Y1.1
unnamed: C2.1, U1.16 (XTAL2), Y1.3
unnamed: C3.1, U1.6 (UCAP)
unnamed: J4.A5 (CC1), R13.2
unnamed: J4.B5 (CC2), R14.1
unnamed: R4.1, U1.42 (AREF)
PROG: SW84.1, U1.33 (~HWB~/PE2)
PWM: U1.12 (PB7); also elsewhere on the board
RESET: R3.2, SW83.1 (A), U1.13 (~RESET)
ROW1: U1.30 (PB6); also elsewhere on the board
ROW2: U1.29 (PB5); also elsewhere on the board
ROW3: U1.28 (PB4); also elsewhere on the board
ROW4: U1.27 (PD7); also elsewhere on the board
ROW5: U1.26 (PD6); also elsewhere on the board
ROW6: U1.25 (PD4); also elsewhere on the board
UART_RX: J2.2, U1.20 (PD2)
UART_TX: J2.3, U1.21 (PD3)

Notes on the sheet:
lid sensor was SM351LT
To SSD1306
Only in standalone Keyboard

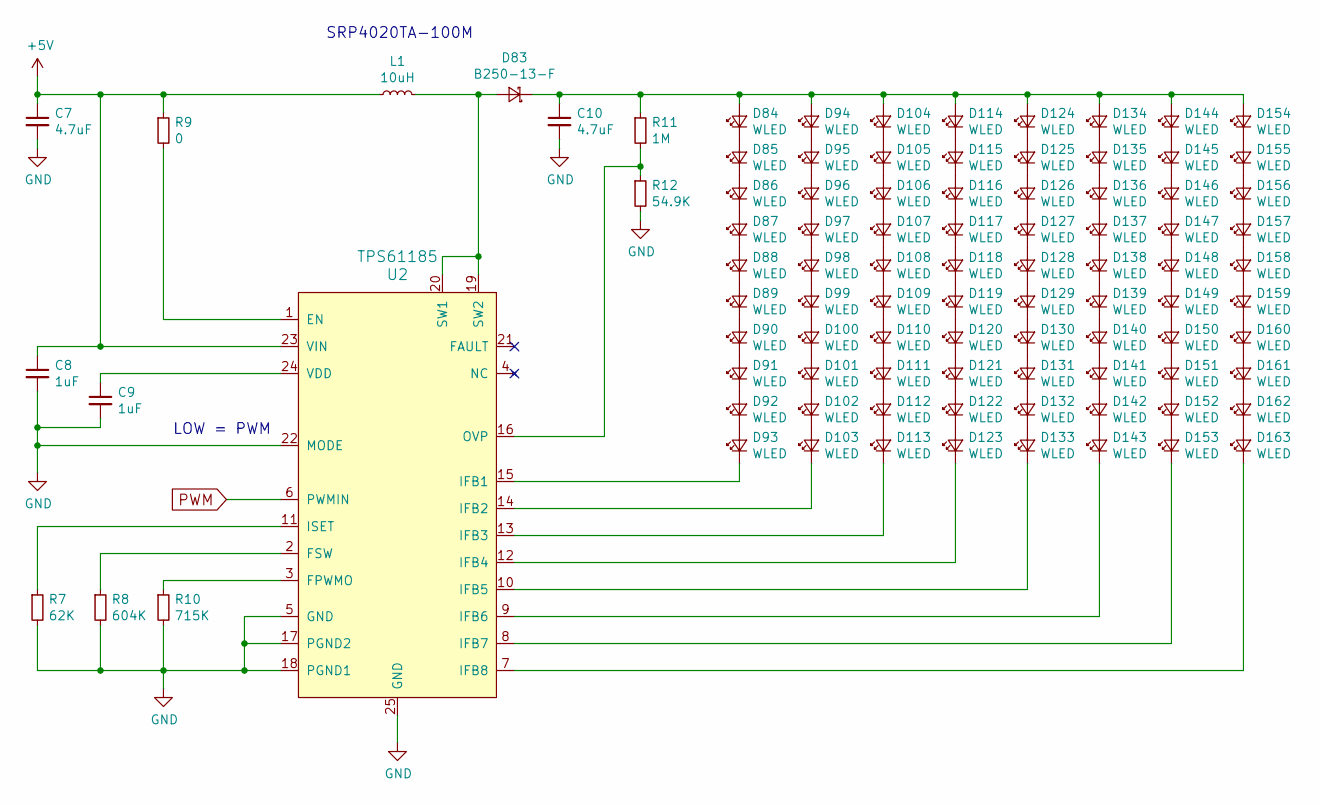
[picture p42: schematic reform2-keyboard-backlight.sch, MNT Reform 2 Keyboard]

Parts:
C7, C10: 4.7uF; C_0603_1608Metric
C8, C9: 1uF; C_0603_1608Metric
D83: B250-13-F; D_SMB_Handsoldering
D84, D85, D86, D87, D88, D89, D90, D91, D92, D93, D94, D95, D96, D97, D98, D99, D100, D101, D102, D103, D104, D105, D106, D107, D108, D109, D110, D111, D112, D113, D114, D115, D116, D117, D118, D119, D120, D121, D122, D123, D124, D125, D126, D127, D128, D129, D130, D131, D132, D133, D134, D135, D136, D137, D138, D139, D140, D141, D142, D143, D144, D145, D146, D147, D148, D149, D150, D151, D152, D153, D154, D155, D156, D157, D158, D159, D160, D161, D162, D163: WLED; LED_0603_1608Metric
L1: 10uH; IND_SRP4020TA-150M
R7: 62K; R_0603_1608Metric
R8: 604K; R_0603_1608Metric
R9: 0; R_0603_1608Metric
R10: 715K; R_0603_1608Metric
R11: 1M; R_0603_1608Metric
R12: 54.9K; R_0603_1608Metric
U2: TPS61185; VQFN-24-1EP_4x4mm_P0.5mm_EP2.45x2.45mm

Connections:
+5V: C7.1, C8.1, L1.1, R9.1, U2.23 (VIN); also elsewhere on the board
GND: C7.2, C8.2, C9.2, C10.2, R7.2, R8.2, R10.2, R12.2, U2.5 (GND), U2.17 (PGND2), U2.18 (PGND1), U2.22 (MODE), U2.25 (GND); also elsewhere on the board
unnamed: C9.1, U2.24 (VDD)
unnamed: C10.1, D83.1 (K), D84.2 (A), D94.2 (A), D104.2 (A), D114.2 (A), D124.2 (A), D134.2 (A), D144.2 (A), D154.2 (A), R11.1
unnamed: D83.2 (A), L1.2, U2.19 (SW2), U2.20 (SW1)
unnamed: D84.1 (K), D85.2 (A)
unnamed: D85.1 (K), D86.2 (A)
unnamed: D86.1 (K), D87.2 (A)
unnamed: D87.1 (K), D88.2 (A)
unnamed: D88.1 (K), D89.2 (A)
unnamed: D89.1 (K), D90.2 (A)
unnamed: D90.1 (K), D91.2 (A)
unnamed: D91.1 (K), D92.2 (A)
unnamed: D92.1 (K), D93.2 (A)
unnamed: D93.1 (K), U2.15 (IFB1)
unnamed: D94.1 (K), D95.2 (A)
unnamed: D95.1 (K), D96.2 (A)
unnamed: D96.1 (K), D97.2 (A)
unnamed: D97.1 (K), D98.2 (A)
unnamed: D98.1 (K), D99.2 (A)
unnamed: D100.1 (K), D101.2 (A)
unnamed: D99.1 (K), D100.2 (A)
unnamed: D101.1 (K), D102.2 (A)
unnamed: D102.1 (K), D103.2 (A)
unnamed: D103.1 (K), U2.14 (IFB2)
unnamed: D104.1 (K), D105.2 (A)
unnamed: D105.1 (K), D106.2 (A)
unnamed: D106.1 (K), D107.2 (A)
unnamed: D107.1 (K), D108.2 (A)
unnamed: D108.1 (K), D109.2 (A)
unnamed: D109.1 (K), D110.2 (A)
unnamed: D110.1 (K), D111.2 (A)
unnamed: D111.1 (K), D112.2 (A)
unnamed: D112.1 (K), D113.2 (A)
unnamed: D113.1 (K), U2.13 (IFB3)
unnamed: D114.1 (K), D115.2 (A)
unnamed: D115.1 (K), D116.2 (A)
unnamed: D116.1 (K), D117.2 (A)
unnamed: D117.1 (K), D118.2 (A)
unnamed: D118.1 (K), D119.2 (A)
unnamed: D119.1 (K), D120.2 (A)
unnamed: D120.1 (K), D121.2 (A)
unnamed: D121.1 (K), D122.2 (A)
unnamed: D122.1 (K), D123.2 (A)
unnamed: D123.1 (K), U2.12 (IFB4)
unnamed: D124.1 (K), D125.2 (A)
unnamed: D125.1 (K), D126.2 (A)
unnamed: D126.1 (K), D127.2 (A)
unnamed: D127.1 (K), D128.2 (A)
unnamed: D128.1 (K), D129.2 (A)
unnamed: D129.1 (K), D130.2 (A)
unnamed: D130.1 (K), D131.2 (A)
unnamed: D131.1 (K), D132.2 (A)
unnamed: D132.1 (K), D133.2 (A)
unnamed: D133.1 (K), U2.10 (IFB5)
unnamed: D134.1 (K), D135.2 (A)
unnamed: D135.1 (K), D136.2 (A)
unnamed: D136.1 (K), D137.2 (A)
unnamed: D137.1 (K), D138.2 (A)
unnamed: D138.1 (K), D139.2 (A)
unnamed: D139.1 (K), D140.2 (A)
unnamed: D140.1 (K), D141.2 (A)
unnamed: D141.1 (K), D142.2 (A)
unnamed: D142.1 (K), D143.2 (A)
unnamed: D143.1 (K), U2.9 (IFB6)
unnamed: D144.1 (K), D145.2 (A)
unnamed: D145.1 (K), D146.2 (A)
unnamed: D146.1 (K), D147.2 (A)
unnamed: D147.1 (K), D148.2 (A)
unnamed: D148.1 (K), D149.2 (A)
unnamed: D149.1 (K), D150.2 (A)
unnamed: D150.1 (K), D151.2 (A)
unnamed: D151.1 (K), D152.2 (A)
unnamed: D152.1 (K), D153.2 (A)
unnamed: D153.1 (K), U2.8 (IFB7)
unnamed: D154.1 (K), D155.2 (A)
unnamed: D155.1 (K), D156.2 (A)
unnamed: D156.1 (K), D157.2 (A)
unnamed: D157.1 (K), D158.2 (A)
unnamed: D158.1 (K), D159.2 (A)
unnamed: D159.1 (K), D160.2 (A)
unnamed: D160.1 (K), D161.2 (A)
unnamed: D161.1 (K), D162.2 (A)
unnamed: D162.1 (K), D163.2 (A)
unnamed: D163.1 (K), U2.7 (IFB8)
unnamed: R7.1, U2.11 (ISET)
unnamed: R8.1, U2.2 (FSW)
unnamed: R9.2, U2.1 (EN)
unnamed: R10.1, U2.3 (FPWMO)
unnamed: R11.2, R12.1, U2.16 (OVP)
PWM: U2.6 (PWMIN); also elsewhere on the board

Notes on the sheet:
LOW = PWM
SRP4020TA-100M

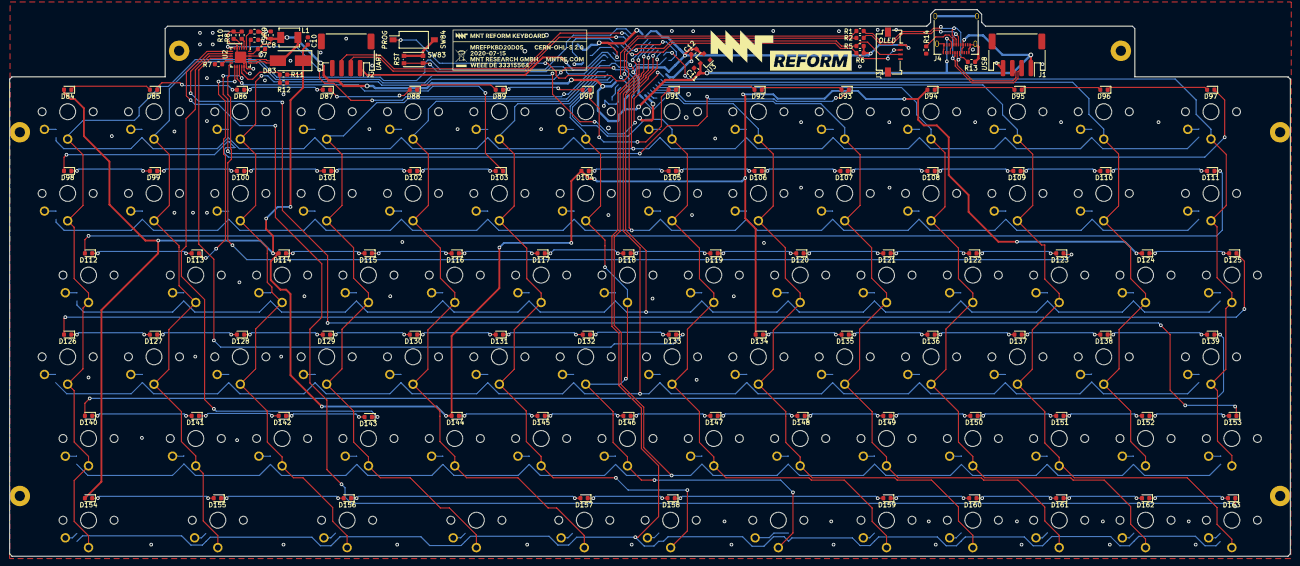
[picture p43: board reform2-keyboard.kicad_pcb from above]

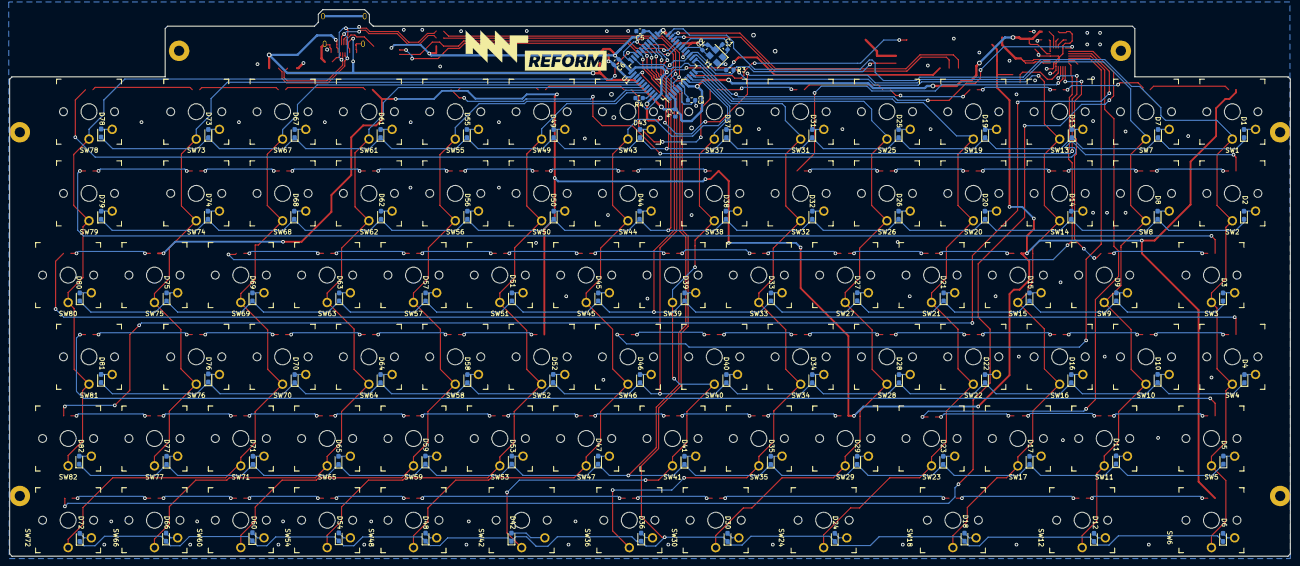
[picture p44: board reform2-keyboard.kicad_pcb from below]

Board: 2 copper layers, 275.9 x 117.8 mm, 290 parts (93 on the bottom side), 210 nets.

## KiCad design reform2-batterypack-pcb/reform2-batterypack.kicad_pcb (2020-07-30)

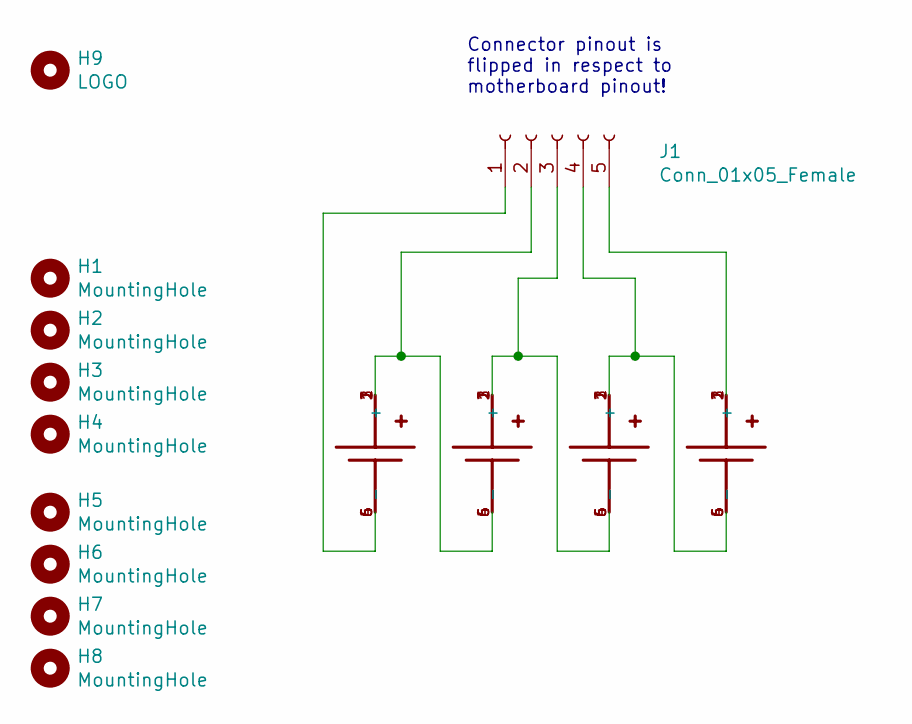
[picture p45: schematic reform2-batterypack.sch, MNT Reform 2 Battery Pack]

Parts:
H1, H2, H3, H4, H5, H6, H7, H8: MountingHole; MountingHole_2.2mm_M2
H9: LOGO; mnt-minilogo
J1: Conn_01x05_Female; Molex_Pico-Lock_504050-0591_1x05-1MP_P1.50mm_Horizontal
U1, U2, U3, U4: KEYSTONE_54; Keystone54

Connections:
unnamed: J1.1, U1.4 (-), U1.5 (-), U1.6 (-)
unnamed: J1.2, U1.1 (+), U1.2 (+), U1.3 (+), U2.4 (-), U2.5 (-), U2.6 (-)
unnamed: J1.3, U2.1 (+), U2.2 (+), U2.3 (+), U3.4 (-), U3.5 (-), U3.6 (-)
unnamed: J1.4, U3.1 (+), U3.2 (+), U3.3 (+), U4.4 (-), U4.5 (-), U4.6 (-)
unnamed: J1.5, U4.1 (+), U4.2 (+), U4.3 (+)

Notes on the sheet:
Connector pinout is flipped in respect to motherboard pinout!


Board: 2 copper layers, 91.0 x 66.0 mm, 13 parts (0 on the bottom side), 5 nets.

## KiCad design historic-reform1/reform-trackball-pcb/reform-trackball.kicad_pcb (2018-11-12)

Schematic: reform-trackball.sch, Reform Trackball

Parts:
C1, C2: 18pF; C_0603_HandSoldering
C3: 0.1uF; C_0603_HandSoldering
C4: 1uF; C_0603_HandSoldering
J1: Conn_USB; Pin_Header_Straight_1x04_Pitch2.00mm
J2: Conn_Sensor; Pin_Header_Straight_1x08_Pitch2.54mm
J3: Conn_RST; Pin_Header_Straight_1x02_Pitch2.54mm
J6: Conn_PWR; Pin_Header_Straight_1x02_Pitch2.54mm
J7: Conn_HWB; Pin_Header_Straight_1x02_Pitch2.54mm
MK2, MK3, MK4: Mounting_Hole; MountingHole_2.2mm_M2_DIN965
MK5, MK6, MK7, MK8: Mounting_Hole; MountingHole_4mm
MK9, MK10, MK11, MK12: Mounting_Hole; MountingHole_3.2mm_M3_DIN965
MK13: LOGO; mnt
MK14: LOGO2; reform04
R1, R2: 10k; R_0603_HandSoldering
SW1, SW2: ML; cherry-ml
U1: ATmega32U2-AU; TQFP-32_7x7mm_Pitch0.8mm
Y1: Crystal_GND24; Crystal_SMD_3225-4pin_3.2x2.5mm_HandSoldering

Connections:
+5V: C3.1, J1.4, J2.1, J6.2, R1.1, R2.1, U1.4 (VCC), U1.31 (UVCC), U1.32 (AVCC)
GND: C1.2, C2.1, C3.2, C4.2, J1.1, J2.7, J3.1, J6.1, J7.1, SW1.4, SW2.4, U1.3 (GND), U1.28 (UGND), Y1.2, Y1.4
MISO: J2.2, U1.17 (PB3)
MOSI: J2.3, U1.16 (PB2)
MT: J2.6, U1.19 (PB5)
unnamed: C1.1, U1.1 (XTAL1), Y1.1
unnamed: C2.2, U1.2 (PC0/XTAL2), Y1.3
unnamed: C4.1, U1.27 (UCAP)
unnamed: J1.2, U1.29 (D+)
unnamed: J1.3, U1.30 (D-)
unnamed: J3.2, R1.2, U1.24 (PC1/~RESET)
unnamed: J7.2, R2.2, U1.13 (~HWB~/PD7)
unnamed: SW1.2, U1.7 (PD1)
unnamed: SW2.2, U1.6 (PD0)
RESET: J2.8, U1.20 (PB6)
SCLK: J2.4, U1.15 (PB1)
SS: J2.5, U1.21 (PB7)


Board: 2 copper layers, 63.2 x 46.5 mm, 28 parts (0 on the bottom side), 17 nets.

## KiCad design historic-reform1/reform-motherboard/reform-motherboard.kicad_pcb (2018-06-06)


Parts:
C11: 0.1uF; C_0603_HandSoldering
C12: 22uF; C_0805_HandSoldering
J1: TinyRex-J1-DF40C; HRS_DF40C-100DS-0.4V(51); Digi-Key_Part_Number H11615CT-ND
J2: TinyRex-J2-DF40C; HRS_DF40C-100DS-0.4V(51); Digi-Key_Part_Number H11615CT-ND
J3: TinyRex-J3-DF40C; HRS_DF40C-100DS-0.4V(51); Digi-Key_Part_Number H11615CT-ND
J8: TEST_BM0; Measurement_Point_Round-SMD-Pad_Small
J10: TEST_PMIC_ON; Measurement_Point_Round-SMD-Pad_Small
J11: TEST_ON; Measurement_Point_Round-SMD-Pad_Small
J20: Conn_GPIO1; Pin_Header_Straight_1x04_Pitch2.00mm
J21: Conn_SPI2; Pin_Header_Straight_1x06_Pitch2.00mm
J35: Conn_SPI1; Pin_Header_Straight_1x06_Pitch2.00mm
MH1, MH2, MH3, MH4: BoardMount; MountingHole_3.2mm_M3_Pad
MH5, MH6: ModuleMount; MountingHole_2.2mm_M2
R6: 0; R_0603_HandSoldering
TP13: TEST_1V2; Measurement_Point_Round-SMD-Pad_Small

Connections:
+3V3: J1.22 (+3V3), J1.24 (+3V3), J1.42 (+3V3), J1.44 (+3V3), J1.46 (+3V3), J2.9 (POK_3V3_BB), J21.6, J35.6; also elsewhere on the board
+5V: C11.1, C12.1, J1.1 (+VIN), J1.2 (+VIN), J1.3 (+VIN), J1.4 (+VIN), J1.6 (+VIN), J1.8 (+VIN), J1.10 (+VIN), J1.12 (+VIN), J1.14 (+VIN), J1.16 (+VIN), J1.18 (+VIN), J1.20 (+VIN), J1.76 (+5V_BB), J1.84 (+5V_BB), J2.7 (POK_5V_BB); also elsewhere on the board
AUD4_CLK: J2.14 (AUD4_CLK); also elsewhere on the board
AUD4_RXD: J2.22 (AUD4_RXD); also elsewhere on the board
AUD4_TXC: J2.16 (AUD4_TXC); also elsewhere on the board
AUD4_TXD: J2.20 (AUD4_TXD); also elsewhere on the board
AUD4_TXFS: J2.18 (AUD4_TXFS); also elsewhere on the board
CSI_CLK0_N: J2.86 (CSI_CLK0_N); also elsewhere on the board
CSI_CLK0_P: J2.88 (CSI_CLK_P); also elsewhere on the board
CSI_D0_N: J2.92 (CSI_D0_N); also elsewhere on the board
CSI_D0_P: J2.94 (CSI_D0_P); also elsewhere on the board
CSI_D1_N: J2.98 (CSI_D1_N); also elsewhere on the board
CSI_D1_P: J2.100 (CSI_D1_P); also elsewhere on the board
CSI_D2_N: J2.91 (CSI_D2_N); also elsewhere on the board
CSI_D2_P: J2.93 (CSI_D2_P); also elsewhere on the board
CSI_D3_N: J2.97 (CSI_D3_N); also elsewhere on the board
CSI_D3_P: J2.99 (CSI_D3_P); also elsewhere on the board
DSI_CLK0_N: J1.98 (DSI_CLK0_N); also elsewhere on the board
DSI_CLK0_P: J1.100 (DSI_CLK0_P); also elsewhere on the board
DSI_D0_N: J1.91 (DSI_D0_N); also elsewhere on the board
DSI_D0_P: J1.93 (DSI_D0_P); also elsewhere on the board
DSI_D1_N: J1.97 (DSI_D1_N); also elsewhere on the board
DSI_D1_P: J1.99 (DSI_D1_P); also elsewhere on the board
ENET_LED_LINK: J3.14 (ENET_LED_LINK); also elsewhere on the board
ENET_LED_RX: J3.16 (ENET_LED_RX); also elsewhere on the board
FAN_PWM: J2.19 (GPIO_OR_PWM_2); also elsewhere on the board
GND: C11.2, C12.2, J1.5 (GND), J1.7 (GND), J1.9 (GND), J1.11 (GND), J1.13 (GND), J1.15 (GND), J1.17 (GND), J1.19 (GND), J1.21 (GND), J1.23 (GND), J1.29 (GND), J1.30 (GND), J1.35 (GND), J1.36 (GND), J1.41 (GND), J1.49 (GND), J1.56 (GND), J1.59 (GND), J1.66 (GND), J1.83 (GND), J1.89 (GND), J1.90 (GND), J1.95 (GND), J1.96 (GND), J2.11 (GND), J2.12 (GND), J2.24 (GND), J2.31 (GND), J2.40 (GND), J2.41 (GND), J2.46 (GND), J2.51 (GND), J2.56 (GND), J2.65 (GND), J2.66 (GND), J2.71 (GND), J2.77 (GND), J2.78 (GND), J2.83 (GND), J2.84 (GND), J2.89 (GND), J2.90 (GND), J2.95 (GND), J2.96 (GND), J3.5 (GND), J3.11 (GND), J3.25 (GND), J3.28 (GND), J3.35 (GND), J3.38 (GND), J3.45 (GND), J3.55 (GND), J3.68 (GND), J3.69 (GND), J3.79 (GND), J3.80 (GND), J3.91 (GND), J3.92 (GND), J20.4, J21.5, J35.5, MH1.1, MH2.1, MH3.1, MH4.1, R6.1; also elsewhere on the board
GPIO2: J1.38 (LVDS0_PWM)
GPIO3: J2.10 (USER_BUTTON), J20.1
HDMI_CEC_IN: J1.80 (HDMI_CEC_IN); also elsewhere on the board
HDMI_CEC_STBY: J1.82 (HDMI_CEC_STBY)
HDMI_CLK_N: J1.92 (HDMI_CLK_N); also elsewhere on the board
HDMI_CLK_P: J1.94 (HDMI_CLK_P); also elsewhere on the board
HDMI_D0_N: J1.86 (HDMI_D0_N); also elsewhere on the board
HDMI_D0_P: J1.88 (HDMI_D0_P); also elsewhere on the board
HDMI_D1_N: J1.79 (HDMI_D1_N); also elsewhere on the board
HDMI_D1_P: J1.81 (HDMI_D1_P); also elsewhere on the board
HDMI_D2_N: J1.85 (HDMI_D2_N); also elsewhere on the board
HDMI_D2_P: J1.87 (HDMI_D2_P); also elsewhere on the board
HDMI_HPD: J1.78 (HDMI_HPD); also elsewhere on the board
I2C1_SCL: J2.26 (I2C1_SCL); also elsewhere on the board
I2C1_SDA: J2.28 (I2C1_SDA); also elsewhere on the board
I2C2_SCL: J2.48 (I2C2_SCL); also elsewhere on the board
I2C2_SDA: J2.50 (I2C2_SDA); also elsewhere on the board
I2C3_SCL: J2.54 (I2C3_SCL); also elsewhere on the board
I2C3_SDA: J2.52 (I2C3_SDA); also elsewhere on the board
LVDS0_CABC: J1.40 (LVDS0_CABC)
LVDS0_CLK_N: J1.25 (LVDS0_CLK_N); also elsewhere on the board
LVDS0_CLK_P: J1.27 (LVDS0_CLK_P); also elsewhere on the board
LVDS0_PWM: J2.17 (GPIO_OR_PWM_1); also elsewhere on the board
LVDS0_TX0_N: J1.26 (LVDS0_TX0_N); also elsewhere on the board
LVDS0_TX0_P: J1.28 (LVDS0_TX0_P); also elsewhere on the board
LVDS0_TX1_N: J1.32 (LVDS0_TX1_N); also elsewhere on the board
LVDS0_TX1_P: J1.34 (LVDS0_TX1_P); also elsewhere on the board
LVDS0_TX2_N: J1.31 (LVDS0_TX2_N); also elsewhere on the board
LVDS0_TX2_P: J1.33 (LVDS0_TX2_P); also elsewhere on the board
LVDS0_TX3_N: J1.37 (LVDS0_TX3_N); also elsewhere on the board
LVDS0_TX3_P: J1.39 (LVDS0_TX3_P); also elsewhere on the board
unnamed: J2.3 (BOOT_MODE0_CON), J8.1
unnamed: J2.13 (CPU_GPIO0), J20.3
unnamed: J2.15 (CPU_GPIO1), J20.2
unnamed: J2.23 (CSPI1_CLK), J35.4
unnamed: J2.25 (CSPI1_MOSI), J35.2
unnamed: J2.27 (CSPI1_MISO), J35.3
unnamed: J2.29 (CSPI1_CS0), J35.1
unnamed: J2.68 (USB0_ID), R6.2
unnamed: J3.6 (+1V2_BB), J3.12 (+1V2_BB), J3.20 (+1V2_BB), TP13.1
unnamed: J2.6 (PMIC_ON_REQ), J10.1
unnamed: J2.8 (ON_OFF), J11.1
unnamed: J3.76 (CSPI2_CS0), J21.1
unnamed: J3.72 (CSPI2_MOSI), J21.2
unnamed: J3.74 (CSPI2_MISO), J21.3
unnamed: J3.70 (CSPI2_CLK), J21.4
PCIE_CLK_N: J2.80 (PCIE_CLK_N); also elsewhere on the board
PCIE_CLK_P: J2.82 (PCIE_CLK_P); also elsewhere on the board
PCIE_RX_N: J2.85 (PCIE_RX_N); also elsewhere on the board
PCIE_RX_P: J2.87 (PCIE_RX_P); also elsewhere on the board
PCIE_TX_N: J2.79 (PCIE_TX_N); also elsewhere on the board
PCIE_TX_P: J2.81 (PCIE_TX_P); also elsewhere on the board
PCIE_WAKE: J2.76 (PCIE_WAKE); also elsewhere on the board
POK_1V5_MODULE: J2.5 (POK_1V5)
POK_2V5: J3.48 (+2V5_BB), J3.58 (+2V5_BB); also elsewhere on the board
RSTINn: J2.2 (RSTINn); also elsewhere on the board
RSTOUTn: J2.4 (RSTOUTn); also elsewhere on the board
SATA_RX_N: J2.36 (SATA_RX_N); also elsewhere on the board
SATA_RX_P: J2.38 (SATA_RX_P); also elsewhere on the board
SATA_TX_N: J2.42 (SATA_TX_N); also elsewhere on the board
SATA_TX_P: J2.44 (SATA_TX_P); also elsewhere on the board
SD1_CD: J3.67 (SD1_CD)
SD1_CLK: J3.89 (SD1_CLK); also elsewhere on the board
SD1_CMD: J3.90 (SD1_CMD); also elsewhere on the board
SD1_DATA0: J3.82 (SD1_DATA0); also elsewhere on the board
SD1_DATA1: J3.84 (SD1_DATA1); also elsewhere on the board
SD1_DATA2: J3.86 (SD1_DATA2); also elsewhere on the board
SD1_DATA3: J3.88 (SD1_DATA3); also elsewhere on the board
SD1_WP: J3.65 (SD1_WP)
SD3_CD: J2.33 (SD3_CD); also elsewhere on the board
SD3_CLK: J2.37 (SD3_CLK); also elsewhere on the board
SD3_CMD: J2.39 (SD3_CMD); also elsewhere on the board
SD3_DATA0: J2.43 (SD3_DATA0); also elsewhere on the board
SD3_DATA1: J2.45 (SD3_DATA1); also elsewhere on the board
SD3_DATA2: J2.47 (SD3_DATA2); also elsewhere on the board
SD3_DATA3: J2.49 (SD3_DATA3); also elsewhere on the board
SD3_WP: J2.35 (SD3_WP); also elsewhere on the board
TRD0_N: J3.1 (TRD0_N); also elsewhere on the board
TRD0_P: J3.3 (TRD0_P); also elsewhere on the board
TRD1_N: J3.7 (TRD1_N); also elsewhere on the board
TRD1_P: J3.9 (TRD1_P); also elsewhere on the board
TRD2_N: J3.2 (TRD2_N); also elsewhere on the board
TRD2_P: J3.4 (TRD2_P); also elsewhere on the board
TRD3_N: J3.8 (TRD3_N); also elsewhere on the board
TRD3_P: J3.10 (TRD3_P); also elsewhere on the board
UART1_CTS: J2.59 (UART1_CTS); also elsewhere on the board
UART1_RTS: J2.57 (UART1_RTS); also elsewhere on the board
UART1_RXD: J2.55 (UART1_RXD); also elsewhere on the board
UART1_TXD: J2.53 (UART1_TXD); also elsewhere on the board
UART2_RXD: J2.63 (UART2_RXD); also elsewhere on the board
UART2_TXD: J2.61 (UART2_TXD); also elsewhere on the board
USB0_N: J2.73 (USB0_N); also elsewhere on the board
USB0_P: J2.75 (USB0_P); also elsewhere on the board
USB1_N: J2.67 (USB1_N); also elsewhere on the board
USB1_P: J2.69 (USB1_P); also elsewhere on the board
USB_OC: J2.70 (USB_OC)

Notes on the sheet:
host mode


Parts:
C2, C24, C29, C34, C39, C43, C44: 1uF; C_0603_HandSoldering
C3: 10uF; CP_Tantalum_Case-T_EIA-3528-12_Hand
C18, C19, C20: 22uF; C_0805_HandSoldering
C21, C22: 22uF; CP_Elec_4x5.8
C23: 47uF; CP_Elec_4x5.8
C25, C33, C35, C36, C37, C92: 0.1uF; C_0603_HandSoldering
C26: 68uF; C_0805_HandSoldering
C27, C38: 10uF; C_0603_HandSoldering
C28: 33uF; C_0805_HandSoldering
C42: 100uF; C_0805_HandSoldering
C94: 10uF; C_0805_HandSoldering
D2, D8: PDS1040; DIO_SBR10U200P5-13
D3: LED_CStat2; LED_0805_HandSoldering
D4: D_Schottky; D_SOD-323_HandSoldering
D5: ZLLS350; D_SOD-523
D7: LED_Charge; LED_0805_HandSoldering
D11: LED_3V3; LED_0805_HandSoldering
J6: Barrel_Jack; SWC_RAPC712X
J15: Conn_FAN; Pin_Header_Straight_1x03_Pitch2.00mm
J22: Conn_PWR; Pin_Header_Straight_1x04_Pitch2.00mm
J33: BAT; Pin_Header_Angled_1x04_Pitch2.54mm
J34: Conn_ATTINY; Pin_Header_Straight_2x04_Pitch2.00mm
L1: 1 uH; Inductor_Wurth_MAPI-4020
L2: 18 uH; SELF-WE-PD-XXL
L3: 10 uH; Inductor_Wurth_MAPI-4020
Q2, Q5: Si2333DDS; SOT-23
Q3: Si7288DP; PowerPAK_SO-8_Dual
R1: 1.5k; R_0603_HandSoldering
R2, R3, R4, R42, R47, R48, R50, R54: 0; R_0603_HandSoldering
R5: 20m; R_1206_HandSoldering
R7, R9: 330; R_0603_HandSoldering
R8: 3.6k; R_0603_HandSoldering
R10: 4.7k; R_0603_HandSoldering
R29: 240; R_0603_HandSoldering
R41, R51, R52, R53, R55: 10k; R_0603_HandSoldering
TP2: TEST_BATOUT; Measurement_Point_Round-SMD-Pad_Small
TP3: TEST_3V3; Measurement_Point_Round-SMD-Pad_Small
TP5: TEST_2V5; Measurement_Point_Round-SMD-Pad_Small
TP6: TEST_1V1; Measurement_Point_Round-SMD-Pad_Small
TP12: TEST_1V5; Measurement_Point_Round-SMD-Pad_Small
TP18: TEST_INALRT; Measurement_Point_Round-SMD-Pad_Small
U2: BQ24650RVAT; QFN50P350X350X100-17N
U3: TPS61235RWLR; CONV_TPS61235RWLR
U4: AP1501A-33K5G-13; DPAK171P1524X485-6N
U5: TLV74311PDBVR; SOT-23-5
U6: INA260AIPW; SOP65P640X120-16N
U11: LP3962EMP-2.5; SOT150P696X180-5N
U13: TLV1117-15; SOT-223
U16: ATTINY841-SSU; SOIC-14_3.9x8.7mm_Pitch1.27mm

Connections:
+1V1: C44.1, TP6.1, U5.5 (OUT); also elsewhere on the board
+3V3: C22.1, C23.1, C26.1, L2.2, R29.1, TP3.1, U4.4 (FB), U11.1 (~SD), U11.2 (VIN); also elsewhere on the board
+5V: C21.1, C94.1, J15.1, J22.1, J22.2, U4.1 (VIN); also elsewhere on the board
BATVCC: C27.1, C33.1, J33.2, J33.3, R47.2, R52.1, R54.2, U6.1 (IN+), U6.2 (IN+), U6.3 (IN+), U6.10 (VS), U6.12 (VBUS)
CHGVCC: C2.1, D2.2 (A), D8.2 (A), J6.1, Q2.1 (G), Q5.1 (G), R1.1, R7.1, R9.1, U2.1 (VCC)
FAN_PWM: J15.2; also elsewhere on the board
GND: C2.2, C3.2, C18.2, C19.2, C20.2, C21.2, C22.2, C23.2, C24.2, C26.2, C27.2, C28.2, C29.2, C33.2, C34.2, C36.2, C37.2, C38.2, C39.2, C42.2, C43.2, C44.2, C92.2, C94.2, D4.2 (A), D11.1 (K), J6.2, J6.3, J15.3, J33.1, J33.4, J34.7, Q3.3 (S), R1.2, R10.1, R41.2, R55.2, U2.11 (GND), U2.17 (EPAD), U3.1 (PGND), U3.4 (CC), U3.5 (AGND), U3.8 (INACT), U4.3 (GND), U4.5 (SD), U4.6 (EXP), U5.2 (GND), U6.6 (GND), U6.11 (GND), U11.4 (~ERROR), U11.5 (GND), U13.1 (GND), U16.14 (GND); also elsewhere on the board
INASCL: R51.2, U6.4 (A1), U6.9 (SCL), U16.13 ((PCINT0/MISO/AREF/ADC0)PA0)
INASDA: R53.2, U6.5 (A0), U6.8 (SDA), U16.12 ((PCINT1/MOSI/TXD0/TOCC0/AIN00/ADC1)PA1)
unnamed: C18.1, C19.1, C20.1, Q2.2 (S), U3.6 (FB), U3.9 (VOUT)
unnamed: C3.1, C24.1, C35.2, C37.1, C38.1, L1.1, R5.2, R8.2, TP2.1, U2.9 (SRN), U3.3 (VIN), U6.14 (IN-), U6.15 (IN-), U6.16 (IN-)
unnamed: C25.1, D5.1 (K), U2.16 (BTST)
unnamed: C25.2, L3.1, Q3.1 (S), Q3.5 (D), Q3.6, U2.14 (PH)
unnamed: C35.1, C36.1, L3.2, R5.1, U2.10 (SRP)
unnamed: C39.1, D5.2 (A), U2.12 (REGN)
unnamed: C42.1, D8.1 (K), J22.3, J22.4, Q5.2 (S)
unnamed: C92.1, R47.1, R51.1, R53.1, U16.1 (VCC)
unnamed: D2.1 (K), Q3.7, Q3.8 (D)
unnamed: D3.1 (K), U2.5 (STAT2)
unnamed: D3.2 (A), R7.2
unnamed: D4.1 (K), L2.1, U4.2 (VOUT)
unnamed: D7.1 (K), U2.3 (STAT1)
unnamed: D7.2 (A), R9.2
unnamed: D11.2 (A), R29.2
unnamed: J34.1, U16.9 ((PCINT4/SCK/SCL/RXD1/T1/TOCC3/AIN11/ADC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)
unnamed: J34.2, U16.3 ((PCINT9/INT0/XTAL2/ADC10)PB1)
unnamed: J34.3, U16.8 ((PCINT5/MISO/TXD1/T2/TOCC4/ACO0/ADC5)PA5)
unnamed: J34.4, U16.2 ((PCINT8/CLKI/XTAL1/ADC11)PB0)
unnamed: J34.5, U16.7 ((PCINT6/MOSI/SDA/XCK1/TOCC5/ACO1/ADC6)P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)
unnamed: J34.6, U16.5 ((PCINT10/RXD0/ICP2/CLKO/TOCC7/ADC8)PB2)
unnamed: J34.8, R52.2, U16.4 ((PCINT11/dW/~RESET~/ADC9)PB3)
unnamed: L1.2, U3.2 (SW)
unnamed: Q2.3 (D), Q5.3 (D)
unnamed: Q3.2 (G), U2.15 (HIDRV)
unnamed: Q3.4 (G), U2.13 (LODRV)
unnamed: R2.2, U2.4 (TS)
unnamed: R3.1, R4.2, U2.6 (VREF)
unnamed: R3.2, R55.1, U2.7 (TERM_EN)
unnamed: R4.1, U2.2 (MPPSET)
unnamed: R2.1, R8.1, R10.2, U2.8 (VFB)
unnamed: R41.1, R42.1, R54.1, U3.7 (EN)
unnamed: R48.2, U16.11 ((PCINT2/~SS~/RXD0/TOCC1/AIN01/ADC2)PA2)
unnamed: R50.2, U16.6 ((PCINT7/~SS~/TXD0/ICP1/TOCC6/ADC7)PA7)
unnamed: TP18.1, U6.7 (ALERT)
POK_1V5: C34.1, C43.1, TP12.1, U5.1 (IN), U5.3 (EN), U13.2 (VO); also elsewhere on the board
POK_2V5: C28.1, C29.1, TP5.1, U11.3 (VOUT), U13.3 (VI); also elsewhere on the board
PWRON: R42.2, U16.10 ((PCINT3/SCK/XCK0/T0/TOCC2/AIN10/ADC3)PA3)
UART2_RXD: R50.1; also elsewhere on the board
UART2_TXD: R48.1; also elsewhere on the board

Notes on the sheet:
Battery V/I Monitor
Tantalum
I2C Addr: 1001110
3.3V Buck
Isolate Battery if jack plugged in
PWR Switch Connector
Without this diode, battery would switch itself off
LiFePO4 Cell
Charger
LED
250mW
PF1206FRF070R02L
(Dis-)Charge Accumulator, UVLO


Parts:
C1, C66: 0.1uF; C_0603_HandSoldering
C74: 10uF; C_0603_HandSoldering
J4: 693072010801
J23: Conn_RESET; Pin_Header_Straight_1x02_Pitch2.54mm
J24: Conn_01x04; Pin_Header_Straight_1x04_Pitch2.00mm
J25: Conn_CONSOLE; Pin_Header_Angled_1x06_Pitch2.54mm
J28: Conn_SDWP; Pin_Header_Straight_1x02_Pitch2.54mm
J29: Conn_5V; Pin_Header_Angled_1x02_Pitch2.54mm
J30: 48099-5701; MOLEX_48099-5701
J38: Conn_SD1; Pin_Header_Straight_2x04_Pitch2.00mm
Q1: 2N7002; SOT-23
R12, R32: 10k; R_0603_HandSoldering
TP1: SATA_DA; Measurement_Point_Round-SMD-Pad_Small
U7: mSATA II; MOLEX_67910-5700
U12: SN74LVC1G08DCKR; SOT65P210X110-5N; Digi-Key_Part_Number 296-11602-1-ND

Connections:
+3V3: C1.1, C66.1, C74.1, J4.4 (VDD), J24.1, J38.1, R12.1, R32.1, U7.2 (+3.3Vaux), U7.24 (+3.3Vaux), U7.39 (+3.3Aux), U7.41 (+3.3Aux), U7.52 (+3.3Vaux), U12.5 (VCC); also elsewhere on the board
+5V: J25.1, J29.1; also elsewhere on the board
GND: C1.2, C66.2, C74.2, J4.6 (VSS), J4.Z1, J4.Z2, J23.1, J24.4, J25.6, J28.1, J29.2, J30.1, J30.2, J30.3, J30.4, J38.2, Q1.2 (S), U7.15 (GND), U7.18 (GND), U7.21 (GND), U7.26 (GND), U7.27 (GND), U7.29 (GND), U7.34 (GND), U7.35 (GND), U7.37 (GND), U7.40 (GND), U7.50 (GND), U12.3 (GND); also elsewhere on the board
I2C2_SCL: J24.2; also elsewhere on the board
I2C2_SDA: J24.3; also elsewhere on the board
unnamed: J4.Z3, J4.Z4, Q1.1 (G), R12.2
unnamed: TP1.1, U7.49 (Reserved)
RESETn: U12.4 (Y); also elsewhere on the board
RSTINn: J23.2, R32.2; also elsewhere on the board
RSTOUTn: U12.1 (A), U12.2 (B); also elsewhere on the board
SATA_RX_N: U7.25 (PERp0); also elsewhere on the board
SATA_RX_P: U7.23 (PERn0); also elsewhere on the board
SATA_TX_N: U7.31 (PETn0); also elsewhere on the board
SATA_TX_P: U7.33 (PETp0); also elsewhere on the board
SD1_CLK: J38.3; also elsewhere on the board
SD1_CMD: J38.4; also elsewhere on the board
SD1_DATA0: J38.5; also elsewhere on the board
SD1_DATA1: J38.6; also elsewhere on the board
SD1_DATA2: J38.7; also elsewhere on the board
SD1_DATA3: J38.8; also elsewhere on the board
SD3_CD: Q1.3 (D); also elsewhere on the board
SD3_CLK: J4.5 (CLK); also elsewhere on the board
SD3_CMD: J4.3 (CMD); also elsewhere on the board
SD3_DATA0: J4.7 (DAT0); also elsewhere on the board
SD3_DATA1: J4.8 (DAT1); also elsewhere on the board
SD3_DATA2: J4.1 (DAT2); also elsewhere on the board
SD3_DATA3: J4.2 (CD/DAT3); also elsewhere on the board
SD3_WP: J28.2; also elsewhere on the board
UART1_CTS: J25.5; also elsewhere on the board
UART1_RTS: J25.4; also elsewhere on the board
UART1_RXD: J25.3; also elsewhere on the board
UART1_TXD: J25.2; also elsewhere on the board

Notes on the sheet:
Reset
Console
Boot SD Card
SD Write Protect
mSATA II
mSATA Latch
Low: Read/Write
Additional SD Card

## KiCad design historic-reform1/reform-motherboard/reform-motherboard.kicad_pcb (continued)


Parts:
C4, C5, C6, C7, C8, C9, C30, C77, C81: 0.1uF; C_0603_HandSoldering
C10: 4.7uF; C_0603_HandSoldering
C31, C32: 330uF; CP_Elec_6.3x7.7
C76, C82: 10uF; C_0603_HandSoldering
C78, C79, C80: 33pF; C_0603_HandSoldering
D9: LED_WLAN; LED_0805_HandSoldering
D10: LED_WWAN; LED_0805_HandSoldering
J27, J31: 48099-5701; MOLEX_48099-5701
J32: SIM_Card; TE_2199337-5
J36: Conn_WWAN_AUX; Pin_Header_Straight_2x03_Pitch2.00mm
R11, R17: 240; R_0603_HandSoldering
R13, R14, R15, R16: 0; R_0603_HandSoldering
TP7: PCIe_WDISn; Measurement_Point_Round-SMD-Pad_Small
TP17: WWAN_RFKILL; Measurement_Point_Round-SMD-Pad_Small
U1: mPCIE 2.0; MOLEX_67910-5700
U8: WWAN USB2.0; MOLEX_67910-5700

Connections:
+3V3: C4.1, C5.1, C6.1, C30.1, C31.1, C32.1, C81.1, C82.1, R11.1, R17.1, U1.2 (+3.3Vaux), U1.24 (+3.3Vaux), U1.39 (+3.3Aux), U1.41 (+3.3Aux), U1.52 (+3.3Vaux), U8.2 (+3.3Vaux), U8.24 (+3.3Vaux), U8.39 (+3.3Aux), U8.41 (+3.3Aux), U8.52 (+3.3Vaux); also elsewhere on the board
GND: C4.2, C5.2, C6.2, C7.1, C8.1, C9.1, C10.1, C30.2, C31.2, C32.2, C76.1, C77.1, C78.1, C79.1, C80.1, C81.2, C82.2, J27.1, J27.2, J27.3, J27.4, J31.1, J31.2, J31.3, J31.4, J32.5 (GND), J36.6, R14.1, U1.4 (GND), U1.9 (GND), U1.15 (GND), U1.18 (GND), U1.21 (GND), U1.26 (GND), U1.27 (GND), U1.29 (GND), U1.34 (GND), U1.35 (GND), U1.37 (GND), U1.40 (GND), U1.43 (GND), U1.50 (GND), U8.4 (GND), U8.9 (GND), U8.15 (GND), U8.18 (GND), U8.21 (GND), U8.26 (GND), U8.27 (GND), U8.29 (GND), U8.34 (GND), U8.35 (GND), U8.37 (GND), U8.40 (GND), U8.43 (GND), U8.50 (GND); also elsewhere on the board
unnamed: C76.2, C77.2, J32.1 (VCC), R13.1
unnamed: D9.1 (K), U1.44 (~LED_WLAN)
unnamed: D9.2 (A), R11.2
unnamed: D10.1 (K), U8.42 (~LED_WWAN)
unnamed: D10.2 (A), R17.2
unnamed: J32.6 (VPP), R15.1
unnamed: J36.1, U8.1 (~WAKE)
unnamed: J36.2, U8.11 (RefClk-)
unnamed: J36.3, U8.13 (RefClk+)
unnamed: J36.4, U8.17 (UIM_C8)
unnamed: J36.5, U8.19 (UIM_C4)
unnamed: R16.2, U8.22 (~PERST)
unnamed: TP7.1, U1.20 (~W_DISABLE)
unnamed: TP17.1, U8.20 (~W_DISABLE)
PCIE_CLK_N: U1.11 (RefClk-); also elsewhere on the board
PCIE_CLK_P: U1.13 (RefClk+); also elsewhere on the board
PCIE_RX_N: U1.23 (PERn0); also elsewhere on the board
PCIE_RX_P: U1.25 (PERp0); also elsewhere on the board
PCIE_SMB_CLK: U1.30 (SMB_CLK)
PCIE_SMB_DATA: U1.32 (SMB_DATA)
PCIE_TX_N: U1.31 (PETn0); also elsewhere on the board
PCIE_TX_P: U1.33 (PETp0); also elsewhere on the board
PCIE_WAKE: U1.1 (~WAKE); also elsewhere on the board
POK_1V5: C7.2, C8.2, C9.2, C10.2, U1.6 (+1.5V), U1.28 (+1.5V), U1.48 (+1.5V), U8.6 (+1.5V), U8.28 (+1.5V), U8.48 (+1.5V); also elsewhere on the board
RESETn: R16.1, U1.22 (~PERST); also elsewhere on the board
UIM_CLK: C78.2, J32.3 (CLK), U8.12 (UIM_CLK)
UIM_DATA: C80.2, J32.7 (I/O), U8.10 (UIM_DATA)
UIM_DET: R14.2, U8.44 (~LED_WLAN)
UIM_PWR: R13.2, U8.8 (UIM_PWR)
UIM_RST: C79.2, J32.2 (RST), U8.14 (UIM_RESET)
UIM_VPP: R15.2, U8.16 (UIM_VPP)
USB_HUB0_N: U8.36 (USB_D-); also elsewhere on the board
USB_HUB0_P: U8.38 (USB_D+); also elsewhere on the board

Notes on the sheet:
mPCIe Latch
WWAN USB2.0
Always check LTE card datasheet!
WWAN Latch
mPCIe Gen2
TE 2199337-5


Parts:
C13, C14, C15, C16, C17, C48, C49, C50, C52, C54, C75, C83, C84, C86, C87: 0.1uF; C_0603_HandSoldering
C40, C41: 18pF; C_0603_HandSoldering
C45, C46, C47, C53: 22uF; C_0603_HandSoldering
C51, C85: 10uF; C_0603_HandSoldering
J5, J7: USB_A
J9: USB_INT_1; Pin_Header_Angled_1x04_Pitch2.00mm
J12: USB_INT_3; Pin_Header_Angled_1x04_Pitch2.00mm
L4, L5: 220@100MHz; R_0603_HandSoldering
P2: J0G-0003NL; PULSE_J0G-0003NL
R18, R19, R20, R21, R23, R24, R26, R27: 27; R_0603_HandSoldering
R22: 9.53k; R_0603_HandSoldering
R25: 10k; R_0603_HandSoldering
R28: 90.9k; R_0603_HandSoldering
R30: 1M; R_0603_HandSoldering
R33, R34, R35: 4.7k; R_0603_HandSoldering
R43, R44, R45, R46: 1.5k; R_0603_HandSoldering
R49: 0; R_0603_HandSoldering
U9: TUSB4041IPAPR; QFP50P1200X1200X105-65N
U15: TPS2044BDR; SOIC127P600X175-16N
Y1: 24MHz; Crystal_SMD_5032-2pin_5.0x3.2mm_HandSoldering

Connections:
+1V1: L5.1; also elsewhere on the board
+3V3: C13.1, L4.1, P2.14 (YEL+), P2.16 (COM+), R43.1, R44.1, R45.1, R46.1; also elsewhere on the board
+5V: C51.1, C52.1, C53.1, C54.1, J7.1 (VBUS), R28.1, U15.2 (IN1), U15.6 (IN2); also elsewhere on the board
ENET_LED_LINK: P2.13 (YEL-); also elsewhere on the board
ENET_LED_RX: P2.17 (GRN-); also elsewhere on the board
GND: C13.2, C14.2, C15.2, C16.2, C17.2, C40.2, C41.2, C45.2, C46.2, C47.2, C48.2, C49.2, C50.2, C51.2, C52.2, C53.2, C54.2, C75.2, C83.2, C84.2, C85.2, C86.2, C87.2, J5.4 (GND), J5.5 (Shield), J7.4 (GND), J7.5 (Shield), J9.4, J12.4, P2.SH1 (SHIELD), P2.SH2 (SHIELD), R22.1, R25.1, R33.2, R34.2, R35.2, U9.9 (PWRCTL_POL), U9.65 (GND_THERMAL), U15.1 (GND_2), U15.5 (GND); also elsewhere on the board
unnamed: C14.1, P2.7 (TRCT4)
unnamed: C15.1, P2.1 (TRCT3)
unnamed: C16.1, P2.6 (TRCT2)
unnamed: C17.1, P2.12 (TRCT1)
unnamed: C40.1, R30.1, U9.30 (XI), Y1.1
unnamed: C41.1, R30.2, U9.29 (XO), Y1.2
unnamed: C75.1, C85.1, L4.2, U9.2 (VDD33@1), U9.20 (VDD33@2), U9.31 (VDD33@3), U9.48 (VDD33@4)
unnamed: C83.1, C84.1, C86.1, C87.1, L5.2, U9.19 (VDD@1), U9.25 (VDD@2), U9.37 (VDD@7), U9.45 (VDD@3), U9.53 (VDD@4), U9.60 (VDD@5), U9.63 (VDD@6)
unnamed: J5.2 (D-), R24.2
unnamed: J5.3 (D+), R23.2
unnamed: J7.2 (D-), R27.2
unnamed: J7.3 (D+), R26.2
unnamed: J9.2, R21.2
unnamed: J9.3, R20.2
unnamed: J12.2, R19.2
unnamed: J12.3, R18.2
unnamed: R22.2, U9.32 (USB_R1)
unnamed: R25.2, R28.2, U9.16 (USB_VBUS)
unnamed: R33.1, U9.13 (AUTOENZ/HS_SUSPEND)
unnamed: R34.1, U9.10 (GANGED/SMBA2/HS_UP)
unnamed: R35.1, U9.8 (FULLPWRMGMTZ/SMBA1)
unnamed: R43.2, U9.14 (OVERCUR1Z), U15.16 (~OC1)
unnamed: R44.2, U9.15 (OVERCUR2Z), U15.13 (~OC2)
unnamed: R45.2, U9.12 (OVERCUR3Z), U15.12 (~OC3)
unnamed: R46.2, U9.11 (OVERCUR4Z), U15.9 (~OC4)
unnamed: R49.1, U9.18 (GRSTZ)
unnamed: U9.4 (PWRCTL1/BATEN1), U15.3 (~EN1)
unnamed: U9.3 (PWRCTL2/BATEN2), U15.4 (~EN2)
unnamed: U9.1 (PWRCTL3/BATEN3), U15.7 (~EN3)
unnamed: U9.64 (PWRCTL4/BATEN4), U15.8 (~EN4)
RESETn: R49.2; also elsewhere on the board
TRD0_N: P2.10 (TDR1-); also elsewhere on the board
TRD0_P: P2.11 (TDR1+); also elsewhere on the board
TRD1_N: P2.5 (TRD2-); also elsewhere on the board
TRD1_P: P2.4 (TRD2+); also elsewhere on the board
TRD2_N: P2.2 (TRD3-); also elsewhere on the board
TRD2_P: P2.3 (TRD3+); also elsewhere on the board
TRD3_N: P2.9 (TRD4-); also elsewhere on the board
TRD3_P: P2.8 (TRD4+); also elsewhere on the board
USB0_N: R27.1; also elsewhere on the board
USB0_P: R26.1; also elsewhere on the board
USB1_N: U9.22 (USB_DM_UP); also elsewhere on the board
USB1_P: U9.21 (USB_DP_UP); also elsewhere on the board
USB_HUB0_5V: U15.15 (OUT1)
USB_HUB0_N: U9.34 (USB_DM_DN1); also elsewhere on the board
USB_HUB0_P: U9.33 (USB_DP_DN1); also elsewhere on the board
USB_HUB1_5V: C45.1, C48.1, J12.1, U15.14 (OUT2)
USB_HUB1_N: R19.1, U9.42 (USB_DM_DN2)
USB_HUB1_P: R18.1, U9.41 (USB_DP_DN2)
USB_HUB2_5V: C47.1, C50.1, J5.1 (VBUS), U15.11 (OUT3)
USB_HUB2_N: R24.1, U9.50 (USB_DM_DN3)
USB_HUB2_P: R23.1, U9.49 (USB_DP_DN3)
USB_HUB3_5V: C46.1, C49.1, J9.1, U15.10 (OUT4)
USB_HUB3_N: R21.1, U9.57 (USB_DM_DN4)
USB_HUB3_P: R20.1, U9.56 (USB_DP_DN4)

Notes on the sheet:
USB 2.0 High Speed Port (480MBps)


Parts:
C67, C68, C89: 10uF; C_0603_HandSoldering
C69, C70, C71, C72, C73, C88, C90, C91, C93: 0.1uF; C_0603_HandSoldering
D6: D_Schottky; D_SOD-323_HandSoldering
J13: Conn_HDMI; 685119134923
J14: Conn_LVDS; Pin_Header_Angled_2x10_Pitch2.00mm
J26: Conn_Backlight; Pin_Header_Angled_1x06_Pitch2.00mm
J37: Conn_CSI; Pin_Header_Straight_2x06_Pitch2.00mm
J39: Conn_DSI; Pin_Header_Straight_2x04_Pitch2.00mm
R36: 47k; R_0603_HandSoldering
R37: 27k; R_0603_HandSoldering
R38, R39: 4.99k; R_0603_HandSoldering
R40: 15k; R_0603_HandSoldering
U14: CM2020-00TR; TSSOP50P640X120-38N

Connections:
+3V3: C68.2, C69.1, C89.2, C90.1, C91.1, C93.1, D6.2 (A), J14.1, J14.2, J14.3, J14.4, J26.3, J37.7, J39.1, U14.2 (LV_SUPPLY); also elsewhere on the board
+5V: C67.2, C70.1, C88.1, J26.1, U14.1 (5V_SUPPLY); also elsewhere on the board
CSI_CLK0_N: J37.2; also elsewhere on the board
CSI_CLK0_P: J37.4; also elsewhere on the board
CSI_D0_N: J37.6; also elsewhere on the board
CSI_D0_P: J37.8; also elsewhere on the board
CSI_D1_N: J37.10; also elsewhere on the board
CSI_D1_P: J37.12; also elsewhere on the board
CSI_D2_N: J37.1; also elsewhere on the board
CSI_D2_P: J37.3; also elsewhere on the board
CSI_D3_N: J37.11; also elsewhere on the board
CSI_D3_P: J37.9; also elsewhere on the board
DSI_CLK0_N: J39.2; also elsewhere on the board
DSI_CLK0_P: J39.3; also elsewhere on the board
DSI_D0_N: J39.8; also elsewhere on the board
DSI_D0_P: J39.7; also elsewhere on the board
DSI_D1_N: J39.6; also elsewhere on the board
DSI_D1_P: J39.5; also elsewhere on the board
GND: C67.1, C68.1, C69.2, C70.2, C71.2, C72.2, C73.2, C88.2, C89.1, C90.2, C91.2, C93.2, J13.2, J13.5, J13.8, J13.11, J13.17, J14.5, J14.6, J26.6, J37.5, J39.4, R40.2, U14.3 (GND), U14.5 (TMDS_GND), U14.8 (TMDS_GND), U14.11 (TMDS_GND), U14.14 (TMDS_GND), U14.25 (TMDS_GND), U14.28 (TMDS_GND), U14.31 (TMDS_GND), U14.34 (TMDS_GND), U14.36 (GND); also elsewhere on the board
HDMI_CEC_IN: U14.16 (CE_REMOTE_IN); also elsewhere on the board
HDMI_CLK_N: J13.12, U14.15 (TMDS_CK-), U14.24 (TMDS_CK-); also elsewhere on the board
HDMI_CLK_P: J13.10, U14.13 (TMDS_CK+), U14.26 (TMDS_CK+); also elsewhere on the board
HDMI_D0_N: J13.9, U14.12 (TMDS_D0-), U14.27 (TMDS_D0-); also elsewhere on the board
HDMI_D0_P: J13.7, U14.10 (TMDS_D0+), U14.29 (TMDS_D0+); also elsewhere on the board
HDMI_D1_N: J13.6, U14.9 (TMDS_D1-), U14.30 (TMDS_D1-); also elsewhere on the board
HDMI_D1_P: J13.4, U14.7 (TMDS_D1+), U14.32 (TMDS_D1+); also elsewhere on the board
HDMI_D2_N: J13.3, U14.6 (TMDS_D2-), U14.33 (TMDS_D2-); also elsewhere on the board
HDMI_D2_P: J13.1, U14.4 (TMDS_D2+), U14.35 (TMDS_D2+); also elsewhere on the board
HDMI_HPD: R36.1, U14.19 (HOTPLUG_DET_IN); also elsewhere on the board
I2C1_SCL: U14.17 (DDC_CLK_IN); also elsewhere on the board
I2C1_SDA: U14.18 (DDC_DAT_IN); also elsewhere on the board
LVDS0_CLK_N: J14.15; also elsewhere on the board
LVDS0_CLK_P: J14.16; also elsewhere on the board
LVDS0_PWM: J26.4; also elsewhere on the board
LVDS0_TX0_N: J14.7; also elsewhere on the board
LVDS0_TX0_P: J14.8; also elsewhere on the board
LVDS0_TX1_N: J14.9; also elsewhere on the board
LVDS0_TX1_P: J14.10; also elsewhere on the board
LVDS0_TX2_N: J14.11; also elsewhere on the board
LVDS0_TX2_P: J14.12; also elsewhere on the board
LVDS0_TX3_N: J14.19; also elsewhere on the board
LVDS0_TX3_P: J14.20; also elsewhere on the board
unnamed: C71.1, U14.37 (ESD_BYP)
unnamed: C72.1, J13.19, R40.1, U14.20 (HOTPLUG_DET_OUT)
unnamed: C73.1, J13.18, R36.2, R38.2, R39.2, U14.38 (5V_OUT)
unnamed: D6.1 (K), R37.2
unnamed: J13.13, R37.1, U14.23 (CE_REMOTE_OUT)
unnamed: J13.15, R38.1, U14.22 (DDC_CLK_OUT)
unnamed: J13.16, R39.1, U14.21 (DDC_DAT_OUT)

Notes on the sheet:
LCD Screen
HDMI


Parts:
C55, C56, C57, C58, C59, C61, C63: 0.1uF; C_0603_HandSoldering
C60, C62, C64, C65: 1uF; C_0603_HandSoldering
J16: Conn_LineIn; Pin_Header_Straight_1x03_Pitch2.00mm
J17: Conn_LineOut; Pin_Header_Straight_1x03_Pitch2.00mm
J18: SJ-43516-SMT
R31: 2.2k; R_0603_HandSoldering
U10: SGTL5000XNAA3; QFN50P500X500X100-33N

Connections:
+3V3: C61.2, C63.2, U10.5 (VDDA), U10.20 (VDDIO); also elsewhere on the board
AUD4_CLK: U10.21 (SYS_MCLK); also elsewhere on the board
AUD4_RXD: U10.25 (I2S_DOUT); also elsewhere on the board
AUD4_TXC: U10.24 (I2S_SCLK); also elsewhere on the board
AUD4_TXD: U10.26 (I2S_DIN); also elsewhere on the board
AUD4_TXFS: U10.23 (I2S_LRCLK); also elsewhere on the board
GND: C55.1, C56.1, C58.1, C59.1, C61.1, C63.1, J16.3, J17.3, U10.1 (GND), U10.3 (GND), U10.7 (AGND), U10.31 (CTRL_ADR0_CS), U10.32 (CTRL_MODE), U10.EXP (GND); also elsewhere on the board
I2C3_SCL: U10.29 (CTRL_CLK); also elsewhere on the board
I2C3_SDA: U10.27 (CTRL_DATA); also elsewhere on the board
unnamed: C55.2, U10.10 (VAG)
unnamed: C56.2, R31.2, U10.16 (MIC_BIAS)
unnamed: C57.1, U10.15 (MIC)
unnamed: C57.2, J18.1 (SLEEVE), R31.1
unnamed: C58.2, U10.18 (CPFILT)
unnamed: C60.1, U10.14 (LINEIN_L)
unnamed: C60.2, J16.1
unnamed: C62.1, U10.13 (LINEIN_R)
unnamed: C62.2, J16.2
unnamed: C64.1, J17.2
unnamed: C64.2, U10.11 (LINEOUT_R)
unnamed: C65.1, J17.1
unnamed: C65.2, U10.12 (LINEOUT_L)
unnamed: J18.2 (TIP), U10.6 (HP_L)
unnamed: J18.3 (RING1), U10.2 (HP_R)
unnamed: J18.4 (RING2), U10.4 (HP_VGND)
POK_1V5: C59.2, U10.30 (VDDD); also elsewhere on the board

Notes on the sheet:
I2C Addr: 0001010


Board: 4 copper layers, 163.0 x 99.0 mm, 241 parts (0 on the bottom side), 245 nets.

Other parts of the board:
R: V; VIA-0.4mm

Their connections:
GND: R.1; also elsewhere on the board

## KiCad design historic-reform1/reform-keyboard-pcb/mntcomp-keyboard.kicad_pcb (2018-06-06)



Board: 2 copper layers, 276.9 x 114.8 mm, 237 parts (91 on the bottom side), 117 nets.

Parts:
C1, C2: 10pF; C_0603_HandSoldering
C3, C4, C5: 1uF; C_0603_HandSoldering
D1, D2, D3, D4, D5, D6, D7, D8, D9, D10, D11, D12, D13, D14, D15, D16, D17, D18, D19, D20, D21, D22, D23, D24, D25, D26, D27, D28, D29, D30, D31, D32, D33, D34, D35, D36, D37, D38, D39, D40, D41, D42, D43, D44, D45, D46, D47, D48, D49, D50, D51, D52, D53, D54, D55, D56, D57, D58, D59, D60, D61, D62, D63, D64, D65, D66, D67, D68, D69, D70, D71, D72, D73, D74, D75, D76, D77, D78, D79: D_Small; D_1206
D80: LED; LED_0805_HandSoldering
J1: Conn_01x02; Pin_Header_Straight_1x02_Pitch2.00mm
J2: Conn_01x06; Pin_Header_Straight_1x06_Pitch2.00mm
J3: Conn_01x05; Pin_Header_Straight_1x05_Pitch2.00mm
MH1, MH2, MH3, MH4, MH5, MH6: Hole; MountingHole_3mm
R: V; VIA-0.4mm
R1, R2: 22; R_0603_HandSoldering
R3: 10k; R_0603_HandSoldering
R4: R_Small; R_0603_HandSoldering
R#2, R#3, R#4, R#5, R#6, R#7, R#8, R#9, R#10, R#11, R#12, R#13, R#14, R#15, R#16, R#17, R#18, R#19, R#20, R#21, R#22, R#23, R#24, R#25, R#26, R#27, R#28, R#29, R#30, R#31, R#32, R#33, R#34, R#35, R#36, R#37, R#38, R#39, R#40, R#41, R#42, R#43, R#44, R#45, R#46, R#47, R#48, R#49, R#50: V; VIA-0.4mm
SH1, SH2, SH3, SH4, SH5, SH6, SH7, SH8: Hole; MountingHole_4mm
SW1, SW2, SW3, SW4, SW5, SW6, SW7, SW8, SW9, SW10, SW11, SW12, SW13, SW14, SW15, SW16, SW17, SW18, SW19, SW20, SW21, SW22, SW23, SW24, SW25, SW26, SW27, SW28, SW29, SW30, SW31, SW32, SW33, SW34, SW35, SW36, SW37, SW38, SW39, SW40, SW41, SW42, SW43, SW44, SW45, SW46, SW47, SW48, SW49, SW50, SW51, SW52, SW53, SW54, SW55, SW56, SW57, SW58, SW59, SW60, SW61, SW62, SW63, SW64, SW65, SW66, SW67, SW68, SW69, SW70, SW71, SW72, SW73, SW74, SW75, SW76, SW77, SW78, SW79: ML; cherry-ml
U1: ATMEGA32U4-AU; TQFP-44_10x10mm_Pitch0.8mm
Y1: 16MHz; Crystal_SMD_3225-4pin_3.2x2.5mm_HandSoldering

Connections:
COL1: SW1.2, SW16.2, SW30.2, SW44.2, SW57.2, SW70.2, U1.30
COL2: SW2.2, SW17.2, SW31.2, SW45.2, SW58.2, SW71.2, U1.12
COL3: SW3.2, SW18.2, SW32.2, SW46.2, SW59.2, SW72.2, U1.18
COL4: SW4.2, SW19.2, SW33.2, SW47.2, SW60.2, SW73.2, U1.19
COL5: SW5.2, SW20.2, SW34.2, SW48.2, SW61.2, SW74.2, U1.20
COL6: SW6.2, SW21.2, SW35.2, SW49.2, SW62.2, SW75.2, U1.21
COL7: SW7.2, SW22.2, SW36.2, SW50.2, SW63.2, SW76.2, U1.25
COL8: SW8.2, SW23.2, SW37.2, SW51.2, SW64.2, SW77.2, U1.22
COL9: SW9.2, SW24.2, SW38.2, SW52.2, SW65.2, SW78.2, U1.26
COL10: SW10.2, SW25.2, SW39.2, SW53.2, SW66.2, SW79.2, U1.27
COL11: SW11.2, SW26.2, SW40.2, SW54.2, SW67.2, U1.41
COL12: SW12.2, SW27.2, SW41.2, SW55.2, SW68.2, U1.40
COL13: SW13.2, SW28.2, SW42.2, SW56.2, SW69.2, U1.39
COL14: SW14.2, SW29.2, SW43.2, U1.38
COL15: SW15.2, U1.37
D+: J2.3, R1.2
D-: J2.2, R2.2
GND: C1.2, C2.2, C3.2, C4.2, C5.2, J1.1, J2.4, J3.4, R.1, R#2.1, R#3.1, R#4.1, R#5.1, R#6.1, R#7.1, R#8.1, R#9.1, R#10.1, R#11.1, R#12.1, R#13.1, R#14.1, R#15.1, R#16.1, R#17.1, R#18.1, R#19.1, R#20.1, R#21.1, R#22.1, R#23.1, R#24.1, R#25.1, R#26.1, R#27.1, R#28.1, R#29.1, R#30.1, R#31.1, R#32.1, R#33.1, R#34.1, R#35.1, R#36.1, R#37.1, R#38.1, R#39.1, R#40.1, R#41.1, R#42.1, R#43.1, R#44.1, R#45.1, R#46.1, R#47.1, R#48.1, R#49.1, R#50.1, U1.5, U1.15, U1.23, U1.35, U1.43, Y1.2, Y1.4
unnamed: C1.1, U1.17, Y1.1
unnamed: C2.1, U1.16, Y1.3
unnamed: C3.1, U1.6
unnamed: D1.2, SW1.4
unnamed: D2.2, SW2.4
unnamed: D3.2, SW3.4
unnamed: D4.2, SW4.4
unnamed: D5.2, SW5.4
unnamed: D6.2, SW6.4
unnamed: D7.2, SW7.4
unnamed: D8.2, SW8.4
unnamed: D9.2, SW9.4
unnamed: D10.2, SW10.4
unnamed: D11.2, SW11.4
unnamed: D12.2, SW12.4
unnamed: D13.2, SW13.4
unnamed: D14.2, SW14.4
unnamed: D15.2, SW15.4
unnamed: D16.2, SW16.4
unnamed: D17.2, SW17.4
unnamed: D18.2, SW18.4
unnamed: D19.2, SW19.4
unnamed: D20.2, SW20.4
unnamed: D21.2, SW21.4
unnamed: D22.2, SW22.4
unnamed: D23.2, SW23.4
unnamed: D24.2, SW24.4
unnamed: D25.2, SW25.4
unnamed: D26.2, SW26.4
unnamed: D27.2, SW27.4
unnamed: D28.2, SW28.4
unnamed: D29.2, SW29.4
unnamed: D30.2, SW30.4
unnamed: D31.2, SW31.4
unnamed: D32.2, SW32.4
unnamed: D33.2, SW33.4
unnamed: D34.2, SW34.4
unnamed: D35.2, SW35.4
unnamed: D36.2, SW36.4
unnamed: D37.2, SW37.4
unnamed: D38.2, SW38.4
unnamed: D39.2, SW39.4
unnamed: D40.2, SW40.4
unnamed: D41.2, SW41.4
unnamed: D42.2, SW42.4
unnamed: D43.2, SW43.4
unnamed: D44.2, SW44.4
unnamed: D45.2, SW45.4
unnamed: D46.2, SW46.4
unnamed: D47.2, SW47.4
unnamed: D48.2, SW48.4
unnamed: D49.2, SW49.4
unnamed: D50.2, SW50.4
unnamed: D51.2, SW51.4
unnamed: D52.2, SW52.4
unnamed: D53.2, SW53.4
unnamed: D54.2, SW54.4
unnamed: D55.2, SW55.4
unnamed: D56.2, SW56.4
unnamed: D57.2, SW57.4
unnamed: D58.2, SW58.4
unnamed: D59.2, SW59.4
unnamed: D60.2, SW60.4
unnamed: D61.2, SW61.4
unnamed: D62.2, SW62.4
unnamed: D63.2, SW63.4
unnamed: D64.2, SW64.4
unnamed: D65.2, SW65.4
unnamed: D66.2, SW66.4
unnamed: D67.2, SW67.4
unnamed: D68.2, SW68.4
unnamed: D69.2, SW69.4
unnamed: D70.2, SW70.4
unnamed: D71.2, SW71.4
unnamed: D72.2, SW72.4
unnamed: D73.2, SW73.4
unnamed: D74.2, SW74.4
unnamed: D75.2, SW75.4
unnamed: D76.2, SW76.4
unnamed: D77.2, SW77.4
unnamed: D78.2, SW78.4
unnamed: D79.2, SW79.4
unnamed: D80.1, J3.5, U1.1
unnamed: D80.2, R4.1
unnamed: J3.1, U1.31
unnamed: J3.2, U1.32
unnamed: J3.3, U1.33
unnamed: R1.1, U1.4
unnamed: R2.1, U1.3
PWRON: J2.5, U1.36
RAWVCC: C5.1, J2.6, R3.1, R4.2, U1.14, U1.24, U1.34, U1.44
RESET: J1.2, R3.2, U1.13
ROW1: D1.1, D2.1, D3.1, D4.1, D5.1, D6.1, D7.1, D8.1, D9.1, D10.1, D11.1, D12.1, D13.1, D14.1, D15.1, U1.8
ROW2: D16.1, D17.1, D18.1, D19.1, D20.1, D21.1, D22.1, D23.1, D24.1, D25.1, D26.1, D27.1, D28.1, D29.1, U1.9
ROW3: D30.1, D31.1, D32.1, D33.1, D34.1, D35.1, D36.1, D37.1, D38.1, D39.1, D40.1, D41.1, D42.1, D43.1, U1.10
ROW4: D44.1, D45.1, D46.1, D47.1, D48.1, D49.1, D50.1, D51.1, D52.1, D53.1, D54.1, D55.1, D56.1, U1.11
ROW5: D57.1, D58.1, D59.1, D60.1, D61.1, D62.1, D63.1, D64.1, D65.1, D66.1, D67.1, D68.1, D69.1, U1.28
ROW6: D70.1, D71.1, D72.1, D73.1, D74.1, D75.1, D76.1, D77.1, D78.1, D79.1, U1.29
UVCC: C4.1, J2.1, U1.2, U1.7

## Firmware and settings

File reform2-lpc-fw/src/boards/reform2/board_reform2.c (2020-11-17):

#include "projectconfig.h"

#ifdef CFG_BRD_REFORM2

#include <string.h> /* strlen */

#include "boards/board.h"
#include "core/gpio/gpio.h"
#include "core/delay/delay.h"
#include "core/eeprom/eeprom.h"
#include "core/pmu/pmu.h"
#include "core/i2c/i2c.h"
#include "core/ssp0/ssp0.h"
#include "core/ssp1/ssp1.h"
#include "core/uart/uart.h"

#ifdef CFG_USB
  #include "core/usb/usbd.h"
  #ifdef CFG_USB_CDC
    #include "core/usb/usb_cdc.h"
  #endif
#endif

#ifdef CFG_INTERFACE
  #include "cli/cli.h"
#endif

#ifdef CFG_PROTOCOL
  #include "protocol/protocol.h"
#endif

#define REFORM_MBREV_D2 2
#define REFORM_MBREV_D3 3
#define REFORM_MBREV_D4 4
#define REFORM_MBREV_R1 11
#define REFORM_MBREV_R2 12

// don't forget to set this!
#define REFORM_MOTHERBOARD_REV REFORM_MBREV_D4
//#define REF2_DEBUG 1
#define FW_REV "R2 "

#define INA260_ADDRESS 0x4e
#define LTC4162F_ADDRESS 0x68
#define I2C_READ 1

#define ST_EXPECT_DIGIT_0 0
#define ST_EXPECT_DIGIT_1 1
#define ST_EXPECT_DIGIT_2 2
#define ST_EXPECT_DIGIT_3 3
#define ST_EXPECT_CMD     4
#define ST_SYNTAX_ERROR   5
#define ST_EXPECT_RETURN  6

extern volatile uint8_t   i2c_write_buf[I2C_BUFSIZE];
extern volatile uint8_t   i2c_read_buf[I2C_BUFSIZE];
extern volatile uint32_t  i2c_read_len, i2c_write_len;

err_t i2c_write8(uint8_t i2c_addr, uint8_t reg, uint8_t value)
{
  i2c_write_len = 3;
  i2c_read_len = 0;
  i2c_write_buf[0] = i2c_addr << 1;
  i2c_write_buf[1] = reg;
  i2c_write_buf[2] = value;
  i2cEngine();

  return ERROR_NONE;
}

int16_t i2c_read16_le(uint8_t i2c_addr, uint8_t reg)
{
  i2c_write_len = 2;
  i2c_read_len = 2;
  i2c_write_buf[0] = i2c_addr << 1;
  i2c_write_buf[1] = reg;
  i2c_write_buf[2] = (i2c_addr << 1) | I2C_READ;
  i2cEngine();

  int16_t value = (i2c_read_buf[0] << 8) | i2c_read_buf[1];
  return value;
}

int16_t i2c_read16_be(uint8_t i2c_addr, uint8_t reg)
{
  i2c_write_len = 2;
  i2c_read_len = 2;
  i2c_write_buf[0] = i2c_addr << 1;
  i2c_write_buf[1] = reg;
  i2c_write_buf[2] = (i2c_addr << 1) | I2C_READ;
  i2cEngine();

  int16_t value = (i2c_read_buf[1] << 8) | i2c_read_buf[0];
  return value;
}

err_t i2c_write16_be(uint8_t i2c_addr, uint8_t reg, uint16_t value)
{
  i2c_write_len = 4;
  i2c_read_len = 0;
  i2c_write_buf[0] = i2c_addr << 1;
  i2c_write_buf[1] = reg;
  i2c_write_buf[2] = value&0xff;
  i2c_write_buf[3] = value>>8;
  i2cEngine();

  return ERROR_NONE;
}

// see https://www.analog.com/media/en/technical-documentation/data-sheets/680324fa.pdf
// default = 0x41
uint8_t calc_pec(uint8_t d, uint8_t pec) {
  //uint8_t pec = 0x41; // 0100 0001

  for (int i=0; i<8; i++) {
    uint8_t bit = (d>>7)&1; // pop off upper bit
    d = d<<1;
    uint8_t in0 = bit ^ (pec>>7);
    uint8_t in1 = (pec & 1) ^ in0;
    uint8_t in2 = ((pec & 2)>>1) ^ in0;
    pec = (pec<<1)&0xf8;
    pec |= in2<<2;
    pec |= in1<<1;
    pec |= in0;
  }

  return pec;
}

// main charger state machine
enum state_t {
              ST_CHARGE,
              ST_OVERVOLTED,
              ST_UNDERVOLTED,
              ST_MISSING,
              ST_FULLY_CHARGED
};

// charging state machine
int state = ST_CHARGE;
int cycles_in_state = 0;
int charge_current = 1;
uint32_t cur_second = 0;
uint32_t last_second = 0;

// 1.8A x 3600 seconds/hour
#define MAX_CAPACITY (1.8)*3600.0
float capacity_max_ampsecs =  MAX_CAPACITY;
float capacity_accu_ampsecs = MAX_CAPACITY;
float capacity_min_ampsecs = 430*3.6; // TODO save this in flash after learning
int capacity_percentage = 0;
float volts = 0;
float current = 0;
unsigned long lastTime = 0;
char uartBuffer[255] = {0};
float cells_v[8] = {0,0,0,0,0,0,0,0};
int num_undervolted_cells = 0;
int num_undervolted_critical_cells = 0;
int num_fully_charged_cells = 0;
int num_overvolted_cells = 0;
int num_missing_cells = 0;
uint8_t reached_full_charge = 0;
uint16_t discharge_bits = 0;
uint16_t overvoltage_bits = 0;
uint16_t undervoltage_bits = 0;
uint16_t missing_bits = 0;
uint16_t missing_reason = 0;
uint8_t spir[64];

#define OVERVOLTAGE_START_VALUE 3.61
#define OVERVOLTAGE_STOP_VALUE 3.4
#define UNDERVOLTAGE_VALUE 2.45
#define UNDERVOLTAGE_CRITICAL_VALUE 2.3
#define MISSING_VALUE_HI 4.3
#define MISSING_VALUE_LO 0.2
#define FULLY_CHARGED_VOLTAGE 3.4
#define WALLPOWER_DETECT_VOLTAGE 24

void set_discharge_bits(uint16_t bits) {
  // 0x10: WRCFG, write config
  spir[0] = 0x01;
  spir[1] = 0xc7;

  spir[2] = 0xe1; // set cdc to 2 = continuous measurement
  spir[3] = bits&0xff; // first 8 bits of discharge switches
  spir[4] = (bits&0xf00)>>8; // last 4 bits of discharge switches

  spir[5] = 0x0;
  spir[6] = 0x0;
  spir[7] = 0x0;

  uint8_t pec = 0x41;
  for (int i=2; i<=7; i++) {
    pec = calc_pec(spir[i], pec);
  }
  spir[8] = pec;

  LPC_GPIO->CLR[1] = (1 << 23);
  ssp1Send(spir, 9);
  LPC_GPIO->SET[1] = (1 << 23);
}

void disable_charge_current(void) {
  if (REFORM_MOTHERBOARD_REV >= REFORM_MBREV_R1) {
    LPC_GPIO->SET[1] |= (1 << 25);
  } else {
    LPC_GPIO->CLR[1] |= (1 << 25);
  }
}

void enable_charge_current(void) {
  if (REFORM_MOTHERBOARD_REV >= REFORM_MBREV_R1) {
    LPC_GPIO->CLR[1] |= (1 << 25);
  } else {
    LPC_GPIO->SET[1] |= (1 << 25);
  }
}

void measure_cell_voltages_and_control_discharge() {
  // first, turn off any discharging
  set_discharge_bits(0);

  // defensive: make sure not to charge with any discharge bits
  // turned on, regardless of state
  if (state == ST_CHARGE && discharge_bits == 0) {
    // we're in normal charge mode, so remove charge current limit
    enable_charge_current();
  } else {
    // we're discharging (balancing), or full charged,
    // so limit charge current
    // also don't charge if we have missing cells
    disable_charge_current();
    set_discharge_bits(discharge_bits);
  }

  // 0x10: STCVDC, start adc
  spir[0] = 0x60;
  spir[1] = 0xe7;
  LPC_GPIO->CLR[1] = (1 << 23);
  ssp1Send(spir, 2);
  LPC_GPIO->SET[1] = (1 << 23);

  // delay is measured in "ticks", which are basically ms?
  delay(50); // FIXME tunable

  // 0x4: RDCV, read all cell voltages
  spir[0] = 0x4;
  spir[1] = 0xdc;

  LPC_GPIO->CLR[1] = (1 << 23);
  ssp1Send(spir, 2);
  memset(spir, 0, 32);
  ssp1Receive(spir, 19);
  LPC_GPIO->SET[1] = (1 << 23);

  int j=0;
  for (int i=0; i<8; i+=2) {
    cells_v[i]   = ((float)((spir[j]|((spir[j+1]&0xf)<<8))-512)) * 1.5 / 1000.0;
    cells_v[i+1] = ((float)((spir[j+1]&0xf0)>>4|(spir[j+2]<<4))-512) * 1.5 / 1000.0;
    j+=3;

#ifdef REF2_DEBUG
    sprintf(uartBuffer,"cell %d: %fV cell %d: %fV\r\n",
                            i, cells_v[i], i+1, cells_v[i+1]);
    uartSend((uint8_t *)uartBuffer, strlen(uartBuffer));
#endif
  }

  num_missing_cells = 0;
  num_undervolted_cells = 0;
  num_fully_charged_cells = 0;
  num_overvolted_cells = 0;
  num_undervolted_critical_cells = 0;

  missing_bits = 0;
  undervoltage_bits = 0;
  overvoltage_bits = 0;
  for (int i=0; i<8; i++) {
    if (cells_v[i] >= MISSING_VALUE_HI || cells_v[i] <= MISSING_VALUE_LO) {
      missing_bits |= (1<<i);
      num_missing_cells++;
    }
    else if ((state == ST_OVERVOLTED && cells_v[i] >= OVERVOLTAGE_STOP_VALUE) ||
             (state != ST_OVERVOLTED && cells_v[i] >= OVERVOLTAGE_START_VALUE)) {
      overvoltage_bits |= (1<<i);
      num_overvolted_cells++;
      // we assume that overvoltage also means fully charged
      num_fully_charged_cells++;
    }
    else if (cells_v[i] >= FULLY_CHARGED_VOLTAGE) {
      num_fully_charged_cells++;
    }
    else if (cells_v[i] < UNDERVOLTAGE_VALUE) {
      undervoltage_bits |= (1<<i);
      num_undervolted_cells++;

      if (cells_v[i] < UNDERVOLTAGE_CRITICAL_VALUE) {
        num_undervolted_critical_cells++;
      }
    }
  }

  // 0x2: RDCFG, read config registers
  /*spir[0] = 0x2;
  spir[1] = 0xce;

  LPC_GPIO->CLR[1] = (1 << 23);
  delay(2);
  ssp1Send(spir, 2);
  memset(spir, 0, 32);
  ssp1Receive(spir, 7);
  delay(2);
  LPC_GPIO->SET[1] = (1 << 23);

  sprintf(uartBuffer,"CFG00 %02x %02x %02x %02x %02x %02x %02x %02x\r\n",
          spir[0], spir[1], spir[2], spir[3], spir[4], spir[5], spir[6], spir[7]);
          uartSend((uint8_t *)uartBuffer, strlen(uartBuffer));*/
}

void discharge_overvolted_cells() {
  discharge_bits = overvoltage_bits;
}

void reset_discharge_bits() {
  discharge_bits = 0;
}

// using INA260 current monitor, count amp-secs going in and out of battery
// (battery gauge)
void measure_and_accumulate_current() {
  float raw_volts   = (float)i2c_read16_le(INA260_ADDRESS, 0x2);
  float raw_current = (float)i2c_read16_le(INA260_ADDRESS, 0x1);

  volts   = raw_volts * 0.00125;
  current = raw_current * 0.001;

  if (current>-0.02 && current<0.02) current = 0; // clamp to zero

  unsigned long thisTime = delayGetSecondsActive();
  if (lastTime>0 && thisTime>lastTime) {
    unsigned long secondsPassed = thisTime - lastTime;

    if (secondsPassed >= 1) {
      lastTime = thisTime;

      // decrease estimated battery capacity
      capacity_accu_ampsecs -= current*(secondsPassed);
    }
  } else {
    // timer uninitialized or timer wrap
    lastTime = thisTime;
  }

#ifdef REF2_DEBUG
  sprintf(uartBuffer,"\033[H\033[2JINA Ah: %f V: %f A: %f\r\n",capacity_accu_ampsecs/3600,volts,current);
  uartSend((uint8_t *)uartBuffer, strlen(uartBuffer));
#endif
}

uint16_t charger_state;
uint16_t charge_status;
uint16_t system_status;
uint16_t limit_alerts;
uint16_t charger_alerts;
uint16_t status_alerts;
float chg_vin;
float chg_vbat;

void turn_som_power_on(void) {
  LPC_GPIO->CLR[1] = (1 << 28); // hold in reset

  LPC_GPIO->CLR[0] = (1 << 20); // PCIe off
  LPC_GPIO->CLR[1] = (1 << 19); // 1v2 off
  LPC_GPIO->CLR[1] = (1 << 31); // USB 5v off (R1+)
  LPC_GPIO->CLR[0] = (1 << 7);  // AUX 3v3 off (R1+)

  if (REFORM_MOTHERBOARD_REV >= REFORM_MBREV_R1) {
    LPC_GPIO->CLR[1] = (1 << 16); // 3v3 on
    LPC_GPIO->CLR[1] = (1 << 15); // 5v on
  } else {
    LPC_GPIO->SET[1] = (1 << 16); // 3v3 on
    LPC_GPIO->SET[1] = (1 << 15); // 5v on
  }

  LPC_GPIO->SET[0] = (1 << 20); // PCIe on
  LPC_GPIO->SET[1] = (1 << 19); // 1v2 on
  LPC_GPIO->SET[1] = (1 << 31); // USB 5v on (R1+)
  LPC_GPIO->SET[0] = (1 << 7);  // AUX 3v3 on (R1+)

  LPC_GPIO->SET[1] = (1 << 28); // release reset
}

// TODO: power leak into USB_5V when turned off (~1.5V)
// try to desolder:
// - R152 (spkvdd)
// - R43/R44 (hdmi i2c pullups) -> disappeared!
// - FB15 (BL_VCC, unlikely)
// - R61 (USB_VBUS of TUSB, unlikely)

// power leak of 0.5V into AUX_3V3
// - FB1
// no, power is leaking through pullups of OVERCUR pins

void turn_som_power_off(void) {
  LPC_GPIO->CLR[1] = (1 << 28); // hold in reset

  if (REFORM_MOTHERBOARD_REV >= REFORM_MBREV_R1) {
    LPC_GPIO->SET[1] = (1 << 16); // 3v3 off
    LPC_GPIO->SET[1] = (1 << 15); // 5v off
  } else {
    LPC_GPIO->CLR[1] = (1 << 16); // 3v3 off
    LPC_GPIO->CLR[1] = (1 << 15); // 5v off
  }

  LPC_GPIO->CLR[0] = (1 << 20); // PCIe off
  LPC_GPIO->CLR[1] = (1 << 19); // 1v2 off
  LPC_GPIO->CLR[1] = (1 << 31); // USB 5v off (R1+)
  LPC_GPIO->CLR[0] = (1 << 7);  // AUX 3v3 off (R1+)
}

void turn_periph_power_on(void) {
}

void turn_periph_power_off(void) {
}

void brownout_setup(void) {
  // Set brownout threshold to 2.63-2.71V (highest level)
  // and enable brownout reset
  LPC_SYSCON->BODCTRL = 0x3 | (1<<4);
}

void watchdog_feed(void) {
  LPC_WWDT->FEED = 0xAA;
  LPC_WWDT->FEED = 0x55;
}

#define WWDT_WDMOD_WDEN             ((uint32_t) (1 << 0))
#define WWDT_WDMOD_WDRESET          ((uint32_t) (1 << 1))

void watchdog_setup(void) {
  LPC_SYSCON->SYSAHBCLKCTRL |= (1<<15); // WWDT enable

  LPC_SYSCON->WDTOSCCTRL =
    (1<<5) | // FREQSEL 0.6MHz
    31; // DIVSEL 64 (31+1)*2

  LPC_SYSCON->PDRUNCFG &= ~(1<<6); // WDTOSC_PD disable

  LPC_WWDT->CLKSEL = 1; // WDOSC

  LPC_WWDT->TC = 0xffff/5; // timeout counter, ~5 seconds

  LPC_WWDT->MOD = 0;
  LPC_WWDT->MOD |= WWDT_WDMOD_WDRESET; // enable WDRESET (watchdog resets system)
  LPC_WWDT->MOD |= WWDT_WDMOD_WDEN; // watchdog enable

  watchdog_feed();
}

void boardInit(void)
{
  SystemCoreClockUpdate();
  GPIOInit();
  delayInit();

  // Set up GPIO directions

  // 5V regulator (U7) on/off
  LPC_GPIO->DIR[1] |= (1 << 15);
  // 3V3 regulator (U12) on/off
  LPC_GPIO->DIR[1] |= (1 << 16);
  // 1V2 regulator (U13) on/off
  LPC_GPIO->DIR[1] |= (1 << 19);
  // PCIe 1 power supply transistor (1V5 regulator U19 and 3V3 load switch)
  LPC_GPIO->DIR[0] |= (1 << 20);
  // USB 5V rail on/off (U24) (board revision R-1+)
  LPC_GPIO->DIR[1] |= (1 << 31);
  // AUX 3V3 power rail on/off (U27), and downstream 1V8 (U17) (board revision R-1+)
  LPC_GPIO->DIR[0] |= (1 << 7);

  // IMX Wake
  LPC_GPIO->DIR[1] |= (1 << 24);
  // IMX Reset
  LPC_GPIO->DIR[1] |= (1 << 28);

  // RNG/SS pin of LTC4020: control/limit charge current
  LPC_GPIO->DIR[1] |= (1 << 25);

  // start with low charge current
  disable_charge_current();

  // initially turn the system off
  turn_som_power_off();

  uartInit(CFG_UART_BAUDRATE);
  i2cInit(I2CMASTER);

  // SPI1 connected to battery monitor (we're controller)
  ssp1Init();
  ssp1ClockSlow();

  // SPI0 connected to the main SOM (they're controller)
  ssp0Init();
  ssp0ClockSlow();

  // SPI chip select
  LPC_GPIO->DIR[1] |= (1 << 23);
  LPC_GPIO->SET[1] =  (1 << 23); // active low

  // UART connected to i.MX8M ttymxc2 REFORM
  /* Set 0.14 UART RXD */
  // this disrupts keyboard communication when main power turned off
  //LPC_IOCON->PIO1_14 &= ~0x07;
  //LPC_IOCON->PIO1_14 |= 0x03;

  // only send to reform, don't receive from it
  /* Set 0.13 UART TXD */
  LPC_IOCON->PIO1_13 &= ~0x07;
  LPC_IOCON->PIO1_13 |= 0x3;

#ifdef REF2_DEBUG
  sprintf(uartBuffer, "\r\nMNT Reform 2.0 MCU initialized.\r\n");
  uartSend((uint8_t*)uartBuffer, strlen(uartBuffer));
#endif
}

char remote_cmd = 0;
uint8_t remote_arg = 0;
unsigned char cmd_state = ST_EXPECT_DIGIT_0;
unsigned int cmd_number = 0;
int cmd_echo = 0;
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
int main(void)
{
  boardInit();
  reset_discharge_bits();

  state = ST_CHARGE;
  cycles_in_state = 0;

  last_second = delayGetSecondsActive();

  // WIP, not yet tested
  //watchdog_setup();
  //sprintf(uartBuffer, "\r\nwatchdog_setup() completed.\r\n");
  //uartSend((uint8_t*)uartBuffer, strlen(uartBuffer));

  while (1)
  {
    // algorithm idea:
    // - check all cell voltages
    // - charging state: if a cell voltage is higher than nominal, do not charge, enter balancing state
    //   - option 1: suspend_charger (CONFIG_BITS_REG, 0x14, bit [5])
    //   - option 2: charge_current_setting (0x1A) to a low level
    // - charging state: if cell voltages are on average lower than nominal, enter charging state
    // - balancing state: discharge the cell with highest voltage (enable discharge switch)
    // - idle state: if one cell voltages is below undervoltage threshold, enter alert state
    // - alert state: constantly signal undervoltage alert to host. after timeout, switch off 5v rail and 3v3 rail

    // charge current 2: ~0.2A

    //watchdog_feed();

    measure_and_accumulate_current();
    measure_cell_voltages_and_control_discharge();
    calculate_capacity_percentage();

    if (state == ST_CHARGE) {
      reset_discharge_bits();

      if (num_missing_cells > 0) {
        missing_reason = missing_bits;
        state = ST_MISSING;
        // if cells were unplugged, we don't know the capacity anymore.
        reached_full_charge = 0;
        cycles_in_state = 0;
      }
      else if (num_undervolted_cells > 0) {
        // when transitioning to undervoltage, we assume we reached the bottom
        // of usable capacity, so record it
        // but only if we reached top charge once, or our counter will
        // be off.
        if (cycles_in_state > 5) {
          if (reached_full_charge > 0) {
            capacity_min_ampsecs = capacity_accu_ampsecs;
          }
          state = ST_UNDERVOLTED;
          cycles_in_state = 0;
        }
      }
      else if (num_overvolted_cells < 8 && num_fully_charged_cells >= 8) {
        // when transitioning to fully charged, we assume that we're at max capacity
        capacity_accu_ampsecs = capacity_max_ampsecs;
        state = ST_FULLY_CHARGED;
        reached_full_charge = 1;
        cycles_in_state = 0;
      }
      else if (num_overvolted_cells > 0) {
        if (cycles_in_state > 5) {
          // some cool-off time
          state = ST_OVERVOLTED;
          cycles_in_state = 0;
        }
      }
    }
    else if (state == ST_UNDERVOLTED) {
      // TODO: issue alert -- switch off system if critical
      reset_discharge_bits();

      if (cycles_in_state > 1) {
        // TODO: find safe heuristic. here we turn off if half
        // of the cells are undervolted and there's no wall power.
        if (volts < WALLPOWER_DETECT_VOLTAGE && (num_undervolted_critical_cells >= 1 || num_undervolted_cells >= 4)) {
          turn_som_power_off();
        }

        state = ST_CHARGE;
        cycles_in_state = 0;
      }
    }
    else if (state == ST_OVERVOLTED) {
      if (num_missing_cells > 0) {
        missing_reason = missing_bits;
        state = ST_MISSING;
        // if cells were unplugged, we don't know the capacity anymore.
        reached_full_charge = 0;
        cycles_in_state = 0;
      } else {
        discharge_overvolted_cells();

        // discharge
        if (cycles_in_state > 5 && (num_overvolted_cells==0 || num_undervolted_cells>0)) {
          reset_discharge_bits();

          state = ST_CHARGE;
          cycles_in_state = 0;
        }
      }
    }
    else if (state == ST_MISSING) {
      reset_discharge_bits();

      if (cycles_in_state > 5) {
        if (num_missing_cells < 1) {
          state = ST_CHARGE;
          cycles_in_state = 0;
        } else if (volts < WALLPOWER_DETECT_VOLTAGE) {
          turn_som_power_off();
        }
      }
    }
    else if (state == ST_FULLY_CHARGED) {
      if (cycles_in_state > 5) {
        // if none of the cells are fully charged anymore, allow charging again
        if (num_fully_charged_cells < 1) {
          state = ST_CHARGE;
          cycles_in_state = 0;
        }
        else if (num_overvolted_cells > 0) {
          state = ST_OVERVOLTED;
          cycles_in_state = 0;
        }
      }
    }

    // handle keyboard commands
    handle_commands();
    cur_second = delayGetSecondsActive();

    if (last_second != cur_second) {
      if (cur_second-last_second<10) {
        // prevent rollovers
        cycles_in_state += cur_second-last_second;

        // report to SPI0 controller
        // TODO: not yet functional
        // report_to_spi();
      }
      last_second = cur_second;
    }
  }
}

#endif

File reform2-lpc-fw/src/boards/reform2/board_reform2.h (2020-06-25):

/**************************************************************************/
/*!
    @file     board_lpcxpresso1347.h
    @author   K. Townsend (microBuilder.eu)

    @brief    Board file for the LPC1347 LPCXpresso board from NXP
    @ingroup  Boards

    @section LICENSE

    Software License Agreement (BSD License)

    Copyright (c) 2012 K. Townsend
    All rights reserved.

    Redistribution and use in source and binary forms, with or without
    modification, are permitted provided that the following conditions are met:
    1. Redistributions of source code must retain the above copyright
    notice, this list of conditions and the following disclaimer.
    2. Redistributions in binary form must reproduce the above copyright
    notice, this list of conditions and the following disclaimer in the
    documentation and/or other materials provided with the distribution.
    3. Neither the name of the copyright holders nor the
    names of its contributors may be used to endorse or promote products
    derived from this software without specific prior written permission.

    THIS SOFTWARE IS PROVIDED BY THE COPYRIGHT HOLDERS ''AS IS'' AND ANY
    EXPRESS OR IMPLIED WARRANTIES, INCLUDING, BUT NOT LIMITED TO, THE IMPLIED
    WARRANTIES OF MERCHANTABILITY AND FITNESS FOR A PARTICULAR PURPOSE ARE
    DISCLAIMED. IN NO EVENT SHALL THE COPYRIGHT HOLDER BE LIABLE FOR ANY
    DIRECT, INDIRECT, INCIDENTAL, SPECIAL, EXEMPLARY, OR CONSEQUENTIAL DAMAGES
    (INCLUDING, BUT NOT LIMITED TO, PROCUREMENT OF SUBSTITUTE GOODS OR SERVICES;
    LOSS OF USE, DATA, OR PROFITS; OR BUSINESS INTERRUPTION) HOWEVER CAUSED AND
    ON ANY THEORY OF LIABILITY, WHETHER IN CONTRACT, STRICT LIABILITY, OR TORT
    (INCLUDING NEGLIGENCE OR OTHERWISE) ARISING IN ANY WAY OUT OF THE USE OF THIS
    SOFTWARE, EVEN IF ADVISED OF THE POSSIBILITY OF SUCH DAMAGE.
*/
/**************************************************************************/
#ifndef __BOARD_REFORM2_H__
#define __BOARD_REFORM2_H__

#ifdef __cplusplus
extern "C" {
#endif

#include "sysdefs.h"

/*=========================================================================
    MCU SELECTION

    Include one of the following definitions depending on if you are
    using the LPC11U37 or LPC1347.  They're generally interchangeable, but
    the LPC11Uxx and LPC13xx CMSIS implementations have some differences
    in naming convention, and occasionally a feature is only available on
    the M3 (DWT for example).  Selecting the appropriate MCU allows
    the right code to be included when differences between the CMSIS
    implementations are present.

    -----------------------------------------------------------------------*/
    #define CFG_MCU_LPC11U24FBD48_401
    // #define CFG_MCU_LPC11U37FBD48_401
    // #define CFG_MCU_LPC1347FBD48
    // #define CFG_MCU_LPC1347FHN33

    /* Basic error checking */
    #if !defined CFG_MCU_LPC1347FBD48 && \
        !defined CFG_MCU_LPC11U37FBD48_401 && \
        !defined CFG_MCU_LPC11U24FBD48_401 && \
        !defined CFG_MCU_LPC1347FHN33
      #error "An MCU must be selected in projectconfig.h (Ex. CFG_MCU_LPC11U37FBD48_401, CFG_MCU_LPC1347FBD48, etc.)"
    #endif

    /* Set flag to indicate which CMSIS library to use */
    #if (defined CFG_MCU_LPC1347FBD48 || defined CFG_MCU_LPC1347FHN33)
      #define CFG_MCU_FAMILY_LPC13UXX
    #elif (defined CFG_MCU_LPC11U24FBD48_401 || defined CFG_MCU_LPC11U37FBD48_401)
      #define CFG_MCU_FAMILY_LPC11UXX
    #endif

    /* Include the correct MCU header file */
    #if defined CFG_MCU_FAMILY_LPC13UXX
      #include "LPC13Uxx.h"
    #endif
    #if defined CFG_MCU_FAMILY_LPC11UXX
      #include "LPC11Uxx.h"
    #endif
/*=========================================================================*/


/*=========================================================================
    FIRMWARE VERSION SETTINGS
    -----------------------------------------------------------------------*/
    #define CFG_FIRMWARE_VERSION_MAJOR      (0)
    #define CFG_FIRMWARE_VERSION_MINOR      (0)
    #define CFG_FIRMWARE_VERSION_REVISION   (0)
/*=========================================================================*/
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

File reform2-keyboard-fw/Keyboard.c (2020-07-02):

/*
  MNT Reform v2 Keyboard Firmware
  Copyright 2019  Lukas F. Hartmann / MNT Research GmbH, Berlin
  lukas@mntmn.com  
*/
/*
             LUFA Library
     Copyright (C) Dean Camera, 2018.

  dean [at] fourwalledcubicle [dot] com
           www.lufa-lib.org
*/
/*
  Copyright 2018  Dean Camera (dean [at] fourwalledcubicle [dot] com)

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
  The author disclaims all warranties with regard to this
  software, including all implied warranties of merchantability
  and fitness.  In no event shall the author be liable for any
  special, indirect or consequential damages or any damages
  whatsoever resulting from loss of use, data or profits, whether
  in an action of contract, negligence or other tortious action,
  arising out of or in connection with the use or performance of
  this software.
*/

#include "Config/LUFAConfig.h"
#include "Keyboard.h"
#include <avr/io.h>
#include "LUFA/Drivers/Peripheral/Serial.h"
#include "ssd1306.h"
#include "scancodes.h"
#include <stdlib.h>

/** Buffer to hold the previously generated Keyboard HID report, for comparison purposes inside the HID class driver. */
static uint8_t PrevKeyboardHIDReportBuffer[sizeof(USB_KeyboardReport_Data_t)];

/** LUFA HID Class driver interface configuration and state information. This structure is
 *  passed to all HID Class driver functions, so that multiple instances of the same class
 *  within a device can be differentiated from one another.
 */
USB_ClassInfo_HID_Device_t Keyboard_HID_Interface =
  {
    .Config =
      {
        .InterfaceNumber              = INTERFACE_ID_Keyboard,
        .ReportINEndpoint             =
          {
            .Address              = KEYBOARD_EPADDR,
            .Size                 = KEYBOARD_EPSIZE,
            .Banks                = 1,
          },
        .PrevReportINBuffer           = PrevKeyboardHIDReportBuffer,
        .PrevReportINBufferSize       = sizeof(PrevKeyboardHIDReportBuffer),
      },
  };


#define output_low(port,pin) port &= ~(1<<pin)
#define output_high(port,pin) port |= (1<<pin)
#define set_input(portdir,pin) portdir &= ~(1<<pin)
#define set_output(portdir,pin) portdir |= (1<<pin)

const uint8_t matrix[15*6] = {
  KEY_ESCAPE, KEY_F1, KEY_F2, KEY_F3, KEY_F4, KEY_F5, KEY_F6, KEY_F7, KEY_F8, KEY_F9, KEY_F10, KEY_F11, KEY_F12, HID_KEYBOARD_SC_EXSEL, HID_KEYBOARD_SC_EXSEL,
  
  KEY_GRAVE_ACCENT_AND_TILDE, KEY_1, KEY_2, KEY_3, KEY_4, KEY_5, KEY_6, KEY_7, KEY_8, KEY_9, KEY_0, KEY_MINUS_AND_UNDERSCORE, KEY_EQUAL_AND_PLUS, KEY_BACKSPACE, 0,
  
  KEY_TAB, KEY_Q, KEY_W, KEY_E, KEY_R, KEY_T, KEY_Y, KEY_U, KEY_I, KEY_O, KEY_P, KEY_OPENING_BRACKET_AND_OPENING_BRACE, KEY_CLOSING_BRACKET_AND_CLOSING_BRACE, KEY_BACKSLASH_AND_PIPE, 0,
  
  HID_KEYBOARD_SC_LEFT_CONTROL, HID_KEYBOARD_SC_APPLICATION, KEY_A, KEY_S, KEY_D, KEY_F, KEY_G, KEY_H, KEY_J, KEY_K, KEY_L, KEY_SEMICOLON_AND_COLON, KEY_APOSTROPHE_AND_QUOTE, KEY_ENTER, 0,
  
  HID_KEYBOARD_SC_LEFT_SHIFT, KEY_DELETE, KEY_Z, KEY_X, KEY_C, KEY_V, KEY_B, KEY_N, KEY_M, HID_KEYBOARD_SC_COMMA_AND_LESS_THAN_SIGN, HID_KEYBOARD_SC_DOT_AND_GREATER_THAN_SIGN, KEY_SLASH_AND_QUESTION_MARK,  HID_KEYBOARD_SC_UP_ARROW, HID_KEYBOARD_SC_RIGHT_SHIFT, 0,
  
  HID_KEYBOARD_SC_EXSEL, HID_KEYBOARD_SC_LEFT_GUI, HID_KEYBOARD_SC_LEFT_CONTROL, KEY_SPACE, HID_KEYBOARD_SC_LEFT_ALT, HID_KEYBOARD_SC_RIGHT_ALT, KEY_SPACE, HID_KEYBOARD_SC_PAGE_UP, HID_KEYBOARD_SC_PAGE_DOWN, HID_KEYBOARD_SC_LEFT_ARROW, HID_KEYBOARD_SC_DOWN_ARROW, HID_KEYBOARD_SC_RIGHT_ARROW,  0,0,0
};

uint8_t matrix_debounce[15*6];

// f8 = sleep
// 49 = mute
// 84 = scroll lock

char r_inbuf[10];

void gfx_clear(void) {
  for (int y=0; y<4; y++) {
    for (int x=0; x<21; x++) {
      gfx_poke(x,y,' ');
    }
  }
}

void empty_serial(void) {
  int clock = 0;
  while (Serial_ReceiveByte()>=0 && clock<1000) {
    // flush serial
    clock++;
  }
}

int term_x = 0;
int term_y = 0;

char response[64];

int remote_receive_string(int print) {
  char done = 0;
  int32_t clock = 0;
  int res_x = 0;
  response[0] = 0;
  
  while (!done) {
    int16_t chr = -1;
    clock = 0;
    while (chr==-1 || chr==0) {
      chr=Serial_ReceiveByte();
      clock++;
      if (clock>500000) goto timeout;
    }
    int poke_chr = chr;
    if (chr=='\n') poke_chr=' ';
    if (chr!='\r') {
      if (print) {
        gfx_poke(term_x,term_y,poke_chr);
        gfx_poke(term_x+1,term_y,' ');
        term_x++;
        if (term_x>=20) {
          term_x=0;
          term_y++;
          if (term_y>=3) {
            term_y=0;
          }
        }
      }
      if (res_x<63) {
        response[res_x++] = chr;
        response[res_x] = 0;
      }
    }
    if (chr=='\r') done = 1;
  }
timeout:
  if (!done && print) gfx_poke(20,0,'T');
  empty_serial();
  if (print) {
    iota_gfx_flush();
  }
  return done;
}

void anim_hello(void) {
  gfx_clear();
  iota_gfx_on();
  for (int y=0; y<3; y++) {
    for (int x=0; x<12; x++) {
      gfx_poke(x+4,y+1,(5+y)*32+x);
      iota_gfx_flush();
    }
  }
  for (int y=0; y<0xff; y++) {
    iota_gfx_contrast(y);
    Delay_MS(2);
  }
  for (int y=0; y<0xff; y++) {
    iota_gfx_contrast(0xff-y);
    Delay_MS(2);
  }
}

void anim_goodbye(void) {
  gfx_clear();
  iota_gfx_on();
  for (int y=0; y<3; y++) {
    for (int x=0; x<12; x++) {
      gfx_poke(x+4,y+1,(5+y)*32+x);
    }
  }
  for (int y=0; y<3; y++) {
    for (int x=0; x<12; x++) {
      gfx_poke(x+4,y+1,' ');
      iota_gfx_flush();
    }
  }
  iota_gfx_off();
}

float voltages[8];

void insert_bat_icon(char* str, int x, float v) {
  char icon = 0;
  if (v>=3.3) {
    icon = 8;
  } else if (v>=3.1) {
    icon = 6;
  } else if (v>=3.0) {
    icon = 4;
  } else if (v>=2.9) {
    icon = 2;
  } else {
    icon = 0;
  }
  str[x]   = 4*32+icon;
  str[x+1] = 4*32+icon+1;
}
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

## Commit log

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2018-01-02 add component, footprint libs; add manufacturing files for 0.1
    [SW3dPS-rapc722.STEP]
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2018-01-17 Reform 0.2 mainboard schematics and PCB work in progress
    [reform-audio.sch, reform-display.sch, reform-eth-usb.sch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]
2018-01-18 Reform 0.2 main PCB routing WIP, 164 nets to go
    [reform-motherboard.kicad_pcb]
2018-01-18 Reform 0.2 main PCB routing WIP, 119 nets to go
    [reform-motherboard.kicad_pcb]
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2018-04-14 WIP snapshot; new BQ24650 charger; mosfet load switch; back to high-speed USB hub; integrate USB and UIM in miniPCIe for LTE
    [reform-audio.sch, reform-display.sch, reform-eth-usb.sch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]
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2018-05-03 0.3 PCB WIP; introduce attiny for battery mgmt
    [reform-eth-usb.sch, reform-motherboard.kicad_pcb, reform-motherboard.sch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]
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2018-05-08 reform 0.3 pcb snapshot manufacture RC; cleaned up module deps; polishing and stitches
    [reform-audio.sch, reform-display.sch, reform-eth-usb.sch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]
2018-05-09 Reform 0.3 final schematics and PCB version for manufacture
    [reform-audio.sch, reform-display.sch, reform-eth-usb.sch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]
2018-06-06 Reform motherboard 0.4 snapshot for manufacturing; fixes wrong TRRS (headset) pinout, missing POWEROK signals and charger TS, TERM signals. also fixes GND stitch going through ENET_LED_LINK line.
    [reform-audio.sch, reform-display.sch, reform-eth-usb.sch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]
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2018-10-29 attiny fw: replace state magic numbers with defined names
    [reform-tiny-fw.ino]
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2018-11-15 fix battery capacity reset in reformd; timestamp to unixtime; make suspend command more universal
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2018-12-03 case: add last-minute screen front rebuild (openSCAD); add trackball spacer (openSCAD)
    [screen-front-v4b.scad, trackball-spacer.scad, trackball-spacer.stl]
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2019-03-29 keyboard pcb: updated with small cleanups to KiCAD 5.x
    [mntcomp-keyboard.sch, reform-kbd-mcu.sch]
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2019-05-28 WIP reform2 kbd: dimensions adjusted to mech. model; initial keys routing
    [reform2-keyboard.kicad_pcb]
2019-05-29 WIP reform2 kbd: restructure switches, led, finer placement, some routing
    [reform-kbd-mcu.sch, reform2-keyboard.kicad_pcb, reform2-keyboard.sch]
2019-05-30 WIP reform2 kbd: MCU section routed, removed LED, introduced AUX port
    [EG1271A.step, reform-kbd-mcu.sch, reform2-keyboard.kicad_pcb]
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2019-05-31 Reform2 Keyboard final prep and snapshot for first prototype manufacturing
    [KMR221GLFS.step, Kailh_keycap-switch_system_1.5x1.step, Kailh_keycap-switch_system_1x1.step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]
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2019-06-14 reform2: add schematic pages for display, eth, usb, sd, pcie, hdmi, audio and some chip work
    [reform2-audio.sch, reform2-display.sch, reform2-eth.sch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]
2019-06-15 reform2: schematic work, mainly power, display, first footprint tests
    [reform2-display.sch, reform2-eth.sch, reform2-hdmi.sch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]
2019-06-20 WIP reform2: more schematics ground work on USB, PCIe, Display, Audio, Power
    [reform2-audio.sch, reform2-display.sch, reform2-eth.sch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]
2019-06-21 WIP reform2: more power/charger details in schematic, footprint fixes
    [reform2-audio.sch, reform2-display.sch, reform2-motherboard.kicad_pcb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]
2019-06-24 WIP: Reform2 more serious component placement on motherboard
    [reform2-hdmi.sch, reform2-motherboard.kicad_pcb, reform2-power.sch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]
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2019-06-25 WIP: reform2 schematic detail work all over the board and more footprints and 3d models added; changed one mpcie to M.2/NGFF/NVMe
    [5035000993.stp, 679105700.stp, FH12-30S-0.5SH.stp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]
2019-07-02 WIP reform2: motherboard: many components sanity checked, passives footprints, fixed wrong NVMe/M.2 connector symbol and pins
    [SW3dPS-rapc722.STEP, reform2-display.sch, reform2-motherboard.sch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]
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2019-07-03 WIP reform2: motherboard: power component tweaks; USB finishing/polishing
    [reform2-power.sch, reform2-usb.sch]
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2019-07-03 WIP: reform2 motherboard: more sanity and footprint checks, passives
    [reform2-display.sch, reform2-eth.sch, reform2-hdmi.sch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]
2019-07-06 WIP: reform2 motherboard: more schematics tuning, preliminary selection of most components
    [reform2-audio.sch, reform2-display.sch, reform2-eth.sch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]
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2019-07-10 WIP: reform 2 motherboard: initial power section placement, routing tests
    [reform2-audio.sch, reform2-display.sch, reform2-eth.sch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]
2019-07-10 WIP reform 2 motherboard: WIP power routing and some footprint files checked in
    [reform2-motherboard.kicad_pcb]
2019-07-10 WIP reform 2 motherboard: more power and charger routing
    [reform2-motherboard.kicad_pcb, reform2-power.sch]
2019-07-11 WIP: reform2 motherboard routing: NVMe and some DSI/eDP
    [reform2-display.sch, reform2-motherboard.kicad_pcb, reform2-pcie.sch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]
2019-07-12 WIP: reform2 motherboard: upgraded to 6 layers, HDMI routed
    [reform2-display.sch, reform2-motherboard.kicad_pcb]
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2019-07-13 WIP: reform2 motherboard: most of battery stuff routed, reshuffled
    [reform2-motherboard.kicad_pcb, reform2-usb.sch]
2019-07-13 WIP: reform2 motherboard: bulk of signal routing done
    [reform2-motherboard.kicad_pcb, reform2-power.sch]
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2019-07-14 WIP: reform2: migrate to Boundary Devices i.MX8M SOM
    [reform2-motherboard.kicad_pcb, reform2-motherboard.sch]
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2019-07-15 WIP: reform2: silkscreen cleanups and more 3d models added
    [1050170001.stp, 21-0140L_T1655-2.step, 436500500.stp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]
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2019-07-17 reform2 motherboard: pinout and footprint checks completed; ERC checks fixed 100%
    [reform2-audio.sch, reform2-display.sch, reform2-hdmi.sch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]
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2019-07-18 reform2: fixed last minute EDP lane polarity error; added EDP dupont breakout
    [reform2-display.sch, reform2-motherboard.sch]
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2019-10-20 Reform 2 Rev 2 WIP: fixed various Rev 1 bugs; consolidate battery connector; consolidate 5v powers; make power rails switchable by LPC; exchange TUSB QFN for TQFP; remove eDP FPC; fixes holes; add SD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
    [reform2-audio.sch, reform2-display.sch, reform2-eth.sch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]
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2019-10-29 Reform 2 motherboard Rev 2 final tweaks before order; added footprints for Molex battery connector and WA SMSI M2 smd screw mounts
    [1054051110.stp, reform2-audio.sch, reform2-display.sch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]
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2019-10-29 fix pullups for all 5 buttons; fix wheel handling
    [Mouse.c]
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2019-11-28 WIP fix baudrate, hyper combo
    [Keyboard.c]
2019-11-28 WIP fix meta-0/1 handling
    [Keyboard.c]
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2020-02-08 Rev 2.0D-3 snapshot.
    Main changes:
    - Charger swapped to LTC4020 (incl. boost converter)
    - 1.2V, 1.5V LDOs swapped to switchers (TLV62568), 1.1V+1.2V unified
    - Audio chip and amp swapped to WM8960 which includes 2 amps and 2
    volumes for speakers/headphones
    - Headphone jack detection
    - Optional routes for Boundary's PCIe 1 Refclk bodge wires
    - Introduces extra LM2841X for standby power 3.3v with analog UVLO
    - Introduces realtime clock PCF8523T
    - Introduces cleaned up "keyboard system control port"
    - Changes generic 2mm headers for USB and speakers to JST PH
    - Power rail rework for more current
    [reform2-audio.sch, reform2-display.sch, reform2-eth.sch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]
2020-02-10 reform2-motherboard: final cleanups and tweaks for D-3, selected all components in BOM
    [5040500591.stp, 9774010243R.stp, FH12-33S-0.5SH.stp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]
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2020-03-19 keyboard fw: fix serial, add some debug output
    [Keyboard.c]
2020-03-23 kbd oled: move font out of oled driver, replace by custom hand pixeled font
2020-03-23 kbd: fix serial comms; introduce hello/goodbye animations
    [Keyboard.c]
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2020-05-19 reform2-motherboard: version D-4 finished; fixes critical D-3 bugs; adds PCIe refclk termination, speaker output filter stage, pcie0 3v3 load switch, imx reset line to lpc, charge current control lin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
    [7447709001.stp, reform2-audio.sch, reform2-display.sch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]
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2020-07-01 LPC: WIP: some more replacements to fix build
    [board_reform2.c, i2c.c, i2c.h]
2020-07-02 lpc: in missing and fully_charged states, we could still become overvolted
    [board_reform2.c]
2020-07-02 keyboard: fix HID report overflow with 7+ keys; add debouncing
    [Keyboard.c]
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2020-07-26 reform2 trackpad: simplify and fix motion and touch detection
    [Mouse.c]
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2020-08-14 reform2-keyboard: version 2d5; add info badge; finalize connector positions; add optional 3v3 regulator for standalone
    [reform-kbd-mcu.sch, reform2-keyboard-backlight.sch, reform2-keyboard.kicad_pcb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]
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2020-08-14 reform2-oled: fix: swap sda/scl
    [reform2-oled.kicad_pcb, reform2-oled.sch]
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2020-09-23 reform2-motherboard: first R-1 snapshot. main changes: EMI, ESD, audio filter, enable FETs, SHDN fix, more rail switches
    [reform2-audio.sch, reform2-display.sch, reform2-hdmi.sch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]
2020-09-23 reform2-motherboard: R-1 silkscreen cleanup; usb hub reset pulldown added
    [reform2-audio.sch, reform2-display.sch, reform2-motherboard.sch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]
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2020-11-03 reform2-lpc-fw: detect full charge; more robust/safe handling of missing cells, avoid charge+discharge collision
    [board_reform2.c]
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2020-11-05 lpc-fw: tweak missing cell and full charged voltages; change flash.sh path
    [board_reform2.c]
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

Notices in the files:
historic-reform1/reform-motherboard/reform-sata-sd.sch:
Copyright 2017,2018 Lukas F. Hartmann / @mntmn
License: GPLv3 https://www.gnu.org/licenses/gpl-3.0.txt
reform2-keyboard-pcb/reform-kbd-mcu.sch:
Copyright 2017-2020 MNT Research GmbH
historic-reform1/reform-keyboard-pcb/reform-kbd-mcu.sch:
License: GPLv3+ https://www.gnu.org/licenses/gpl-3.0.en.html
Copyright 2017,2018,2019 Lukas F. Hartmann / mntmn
